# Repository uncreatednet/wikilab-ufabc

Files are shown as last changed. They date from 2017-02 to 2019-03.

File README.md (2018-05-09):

# wikilab

Um laboratório experimental baseado no [wikihouse](http://wikihouse.cc/) e na [casa modelo](http://www.archdaily.com.br/br/773676/casa-revista-a-primeira-casa-fabricada-digitalmente-no-brasil) da UFRJ (também feito com o wikihouse).

[English version here](english.md)

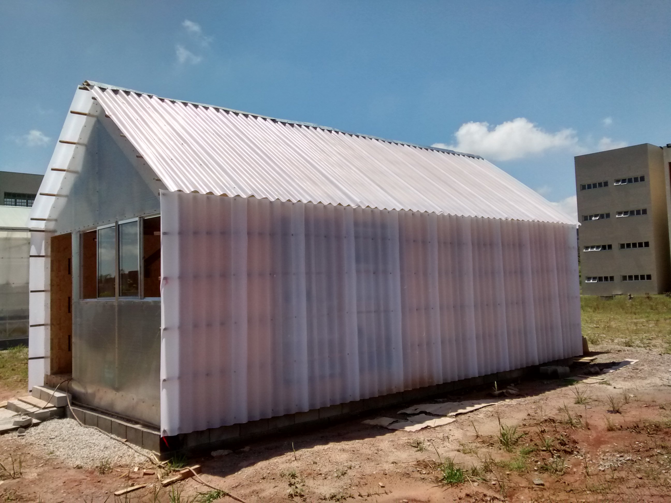
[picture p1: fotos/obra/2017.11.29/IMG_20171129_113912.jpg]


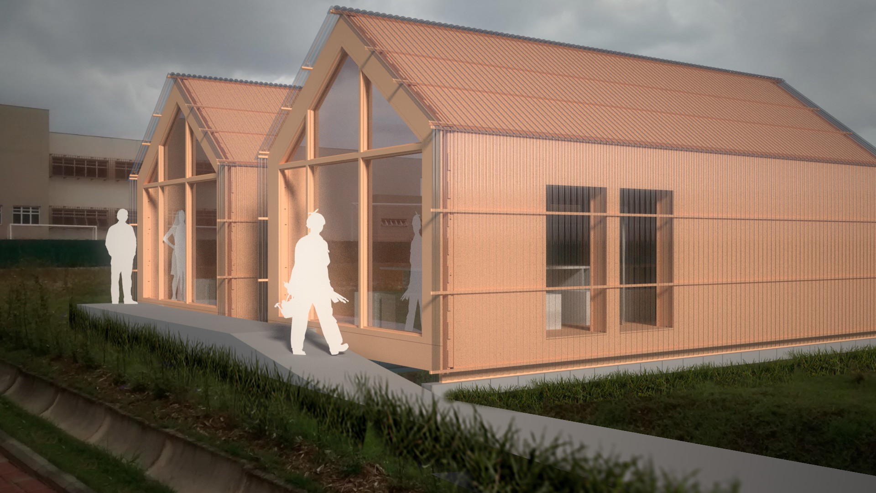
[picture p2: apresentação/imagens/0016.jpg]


Este projeto foi construído no segundo semestre de 2017. O projeto foi desenvolvido de forma aberta como parceria entre diferentes entidades incluindo o labLivre da UFABC e o [uncreated.net](http://www.uncreated.net)

Nas pastas deste projeto, podem ser encontrados:

* O modelo principal do projeto, que é o arquivo [wikilab.FCStd](wikilab.FCStd) a ser aberto com o [FreeCAD](http://www.freecadweb.org) contendo o projeto completo em 3D ([BIM](https://pt.wikipedia.org/wiki/BIM))
* O módulo de base, que serviu para o corte das peças com máquina CNC, está no arquivo separado [modulo wren.FCStd](modulo wren.FCStd)
* Um manual de construção, que descreve passo a passo todas etapas da construção do Wikilab
* Fotos da preparação, da montagem (obra) e do Wikilab acabado
* A pasta "apresentação" contém arquivos .blend do mesmo modelo, para geração de imagens, a serem abertos com o [Blender](http://www.blender.org)
* Na parta "orçamento" estão as planilhas dos orçamentos preliminares e definitivo do projeto. O projeto foi construido, com algumas trocas e modificações, dentro do preço do orçamento final
* Exemplos e referências de outros projetos
* Plantas clássicas de arquitetura, que foram feitas para obtenção da aprovação do projeto junto a UFABC, está no pasta "aprovação 
* A pasta "folhas de corte" contem as bases que foram extraidas do modelo 3D, e os arquivos gcode que forma gerados a partir dessas bases

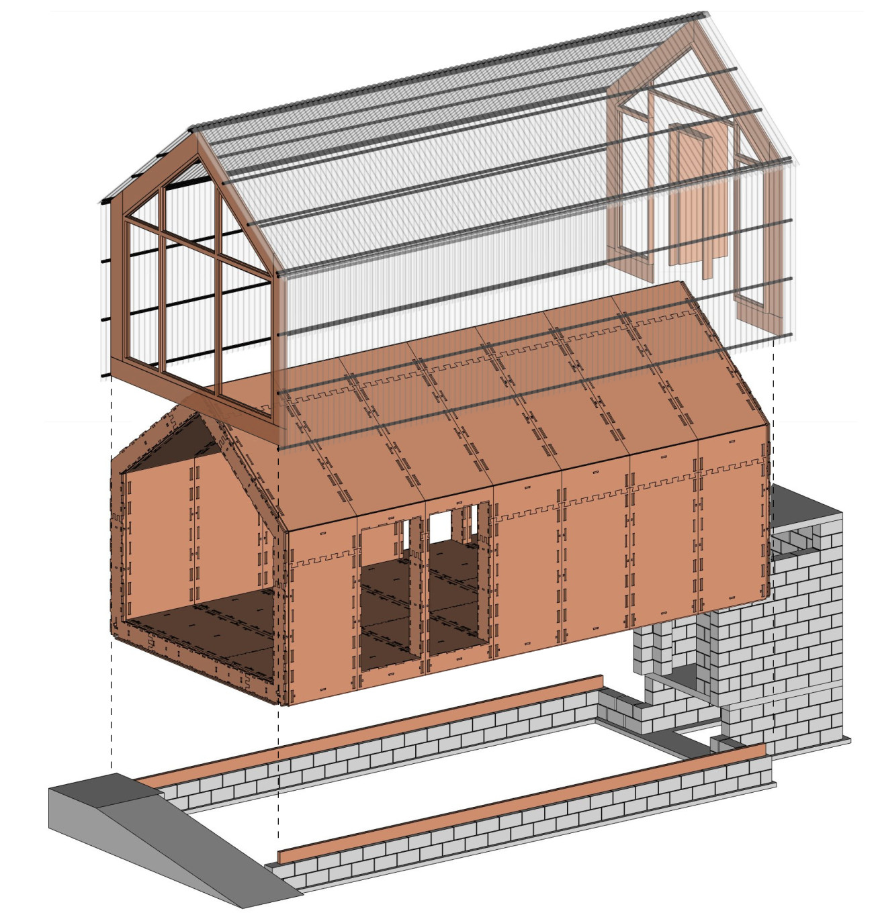
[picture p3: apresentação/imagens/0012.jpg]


Veja também o [modelo no sketchfab](https://sketchfab.com/models/bab56ed7d2414e13b3eacd6c2f29ce65)

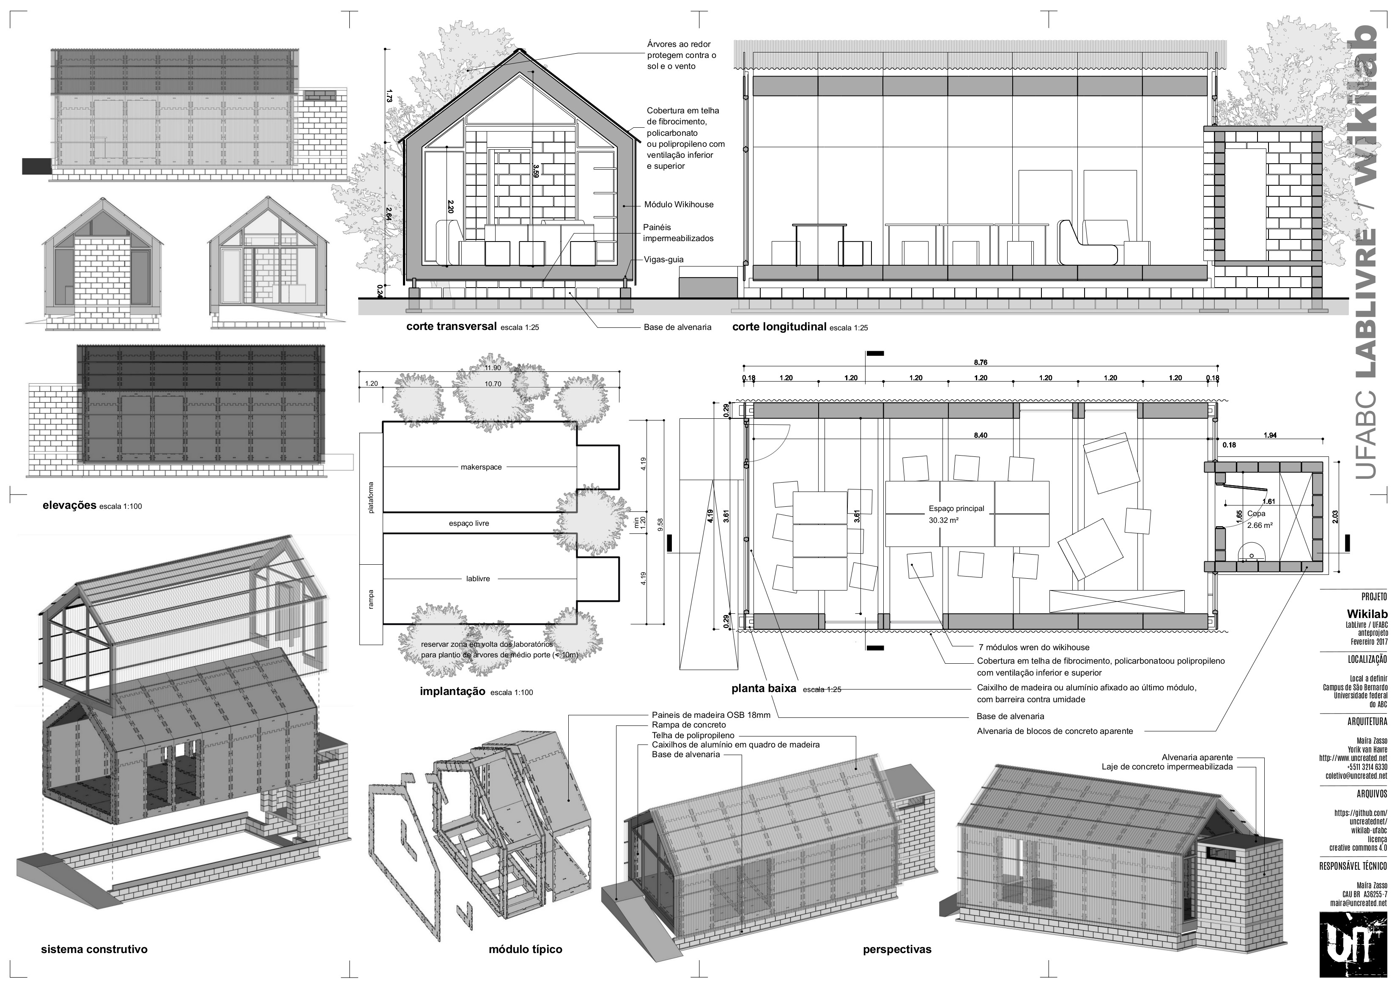
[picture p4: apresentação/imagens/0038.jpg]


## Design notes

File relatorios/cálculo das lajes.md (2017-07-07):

# Cálculo das lajes

usando o método de Marcus ([tabelas](https://drive.google.com/file/d/0B_sf8aj9_lOfUndZOWZqelZ1c2M/view?usp=sharing))

e método [curso de engenharia da USP](http://www.set.eesc.usp.br/mdidatico/concreto/Textos/11%20Lajes%20Macicas.pdf)

respeita [NBR 6118](https://drive.google.com/file/d/0B_sf8aj9_lOfVngzNnpPVkN6aWc/view?usp=sharing) e [NBR6120](https://drive.google.com/file/d/0B_sf8aj9_lOfbG9CeE1PY1ZnVHc/view?usp=sharing)

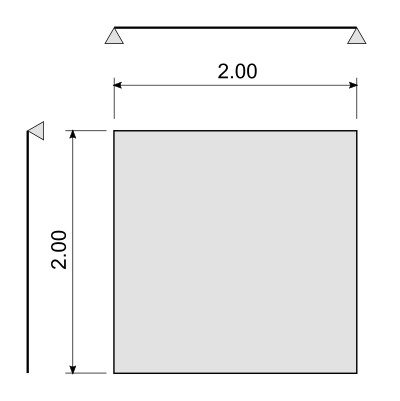
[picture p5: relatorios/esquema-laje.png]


## 1. Predimensionamento / flexão máxima

Usando a [NBR 6118](https://drive.google.com/file/d/0B_sf8aj9_lOfVngzNnpPVkN6aWc/view?usp=sharing)

Fórmula: d >= L / (psi2 x psi3)

psi2 = 1 (apoios simples em 3 lados)

psi3 = 30 (usando CA-50)

d = 200 cm / (1 x 30) = 6.7cm

espessura = 6.7 cm + 2 cm de recobrimento (tipo I da NBR) = 8.7 cm = **9 cm**

## 2. Área e carga

Área: 2 m x 2 m = **4 m²**

Peso próprio = 0.09 m x 2500 kg/m³ (concreto) = 225 kg/m² = 2.25 kN/m²

Sobrecarga = 200 kg/m² (carga padrão para uso residencial) = 2 kN/m²

Carga total = **4.25 kN/m²**

## 3. Tabela de Marcus

Usando o caso 1 da [tabela de Marcus](https://drive.google.com/file/d/0B_sf8aj9_lOfUndZOWZqelZ1c2M/view?usp=sharing), sem engastes:

Lx / Ly = 2.00 / 2.00 = 1

mx = 27.4

my = 27.4

Kx = 0.5

## 4. Cálculo dos momentos máximos

Usando a tabela de Marcus:

Mx = qL²/mx = 4.25 kN/m² x 4 m² / 27.4 = 0.62 kNm = **6.2 tfcm**

My = Mx = 0.62 kNm = 6.2 tfcm

qx = Kx x q = 0.5 x 4.25 kN/m² = 2.125 kN/m²

Considerando que um lado é engastado (improvável, só para ver o que seria o caso extremo)

Ma = -qL²/8 = -2.125 kNm = -21.25 tfcm

Usando a NBR ([tabela de Bares](https://drive.google.com/file/d/0B_sf8aj9_lOfZUlBdGNsOEcyMWM/view?usp=sharing)):

Caso 1 (apoios simples)

Mux = Muy = 4.23

Mx = My = Mux x qL²/100 = 4.23 x 4.25Kn/m² x 4 / 100 = 0.71 kNm = **7.1 tfcm**

## 5. Dimensionamento das ferragens 

Usando aço CA-50 / concreto C20

~~x = metade da altura total da laje = 9cm / 2 = 4.5cm~~

d = altura da laje acima da ferragem = 7cm

**Dimensionamento para Mx/My (Marcus)**

~~Usando sigma calculado = x/d = 4.5/7 = 0.6428 -> k6 = 41 -> k3 = 0.429~~

Usando k6 da tabela = 00 x d² / q = 100 x 7² / 6.2 tfcm = 790 -> k3 = 0.325

Área de aço As = 0.325 x 6.2 / 7 = **0.28 cm²/m**

**Dimensionamento para Mx/My (NBR)**

Usando [Tabelas Gerais](https://drive.google.com/file/d/0B_sf8aj9_lOfUGpUWXpqQ3o5UVE/view?usp=sharing)

Usando momento de cálculo Md = 1.4 x Mx = 1.4 x 0.71 kNm = 0.994 kNm = 99.4 kNcm

kc = bd²/Md = 100 x 7² / 99.4 = 49.3 cm²/kN

ks = 0.023 (tabela)

Área de aço  As = ks x Md / d = 0.023 x 99.4 / 7 = **0.32 cm²/m**

**Dimensionamento para Ma** (caso não existente  apenas para ver o que seria o extremo)

~~Usando sigma calculado = x/d = 4.5/7 = 0.6428 -> k6 = 41 -> k3 = 0.429~~

Usando k6 da tabela = 100 x d² / q = 100 x 7² / 21.25 tfcm = 230 -> k3 = 0.331

Área de aço As = 0.331 x 21.25 / 7 = **1.0 cm²/m**

## 6. Verificação tamanho mínimo (NBR):

As min = 0.00075 x h xl = 0.00075 x 7 x 100 = **0.52 cm²/m**

## 7. Ferragens

Telas disponíveis e área em cm²/m

| Bitola | 20 cm | 15 cm | 10 cm |
| --- | ----- | ----- | ----- |
| 3.4 mm | 0.36  | 0.54  | 0,81  |
| 4.2 mm | 0.55  | 0.82  | 1.24  |

Ferragem apropriado: **4.2 mm x 20 cm ou 3.4 mm x 15 cm**

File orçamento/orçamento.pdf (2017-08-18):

Wikilab - orçamento 18/08/2017 | 1/3
Orçamento definitivo | data: 18.08.2017 | fonte PMSP: http://www.prefeitura.sp.gov.br/cidade/secretarias/obras/tabelas_de_custos/index.php?p=232211
Escopo Seção | Item | Descição | Quantidade | Unidade | Preço material | Total material Total mão de obra | Preço total | Fonte do preço | Observações

E

m

# preiteira

## 1 Fundação, alvenaria e estrutura

1.1 | | 46.37 | m² | R$ 0.00 | R$ 4.15 | R$ 0.00 | R$ 192.43 | R$ 192.43 | PMSP 01-01-08
1.2 | Escavação manual das valas de 30cm x 30cm | 2.55 | m³ | R$ 0.00 | R$ 49.81 | R$ 0.00 | R$ 127.22 | R$ 127.22 | PMSP 01-04-01
1.3 | Lastro de concreto de 7cm no funda da vala | 0.60 | m³ | R$ 173.62 | R$ 140.24 | R$ 103.36 | R$ 83.49 | R$ 186.86 | PMSP 13-01-14
1.4 | Lastro de concreto de 5cm no terreno todo | 1.58 | m³ | R$ 173.62 | R$ 140.24 | R$ 273.52 | R$ 220.94 | R$ 494.46 | PMSP 13-01-14
1.5 | | 10.28 | m² | R$ 52.69 | R$ 29.53 | R$ 541.65 | R$ 303.57 | R$ 845.22 | PMSP 04-01-35
1.6 | Grauteamento dos blocos | 0.98 | m³ | R$ 219.27 | R$ 400.41 | R$ 214.14 | R$ 391.04 | R$ 605.18 | PMSP 04-01-97
1.7 | | 11.07 | kg | R$ 3.37 | R$ 3.09 | R$ 37.30 | R$ 34.19 | R$ 71.48 | PMSP 04-01-95
1.8 | | 10.28 | m² | R$ 28.19 | R$ 35.81 | R$ 289.79 | R$ 368.13 | R$ 657.92 | PMSP 02-06-05
1.9 | Lona de polietileno 4x3m de baixo da laje | 1.00 | un | R$ 16.00 | R$ 0.00 | R$ 16.00 | R$ 0.00 | R$ 16.00 | Leroy Merlin
1.10 | Forma para lajes de concreto em tábuas de madeira | 7.33 | m² | R$ 8.54 | R$ 44.52 | R$ 62.60 | R$ 326.33 | R$ 388.93 | PMSP 02-03-01
1.11 | | 0.79 | m³ | R$ 260.60 | R$ 121.96 | R$ 206.86 | R$ 96.81 | R$ 303.68 | PMSP 02-05-06
1.12 | | 5.62 | kg | R$ 4.34 | R$ 1.55 | R$ 24.39 | R$ 8.71 | R$ 33.10 | PMSP 03-02-09
1.13 | Impermeabilização de laje | 4.45 | m² | R$ 28.19 | R$ 35.81 | R$ 125.45 | R$ 159.35 | R$ 284.80 | PMSP 02-06-05
1.14 | | 26.00 | m² | R$ 52.69 | R$ 29.53 | R$ 1,370.11 | R$ 767.87 | R$ 2,137.98 | PMSP 04-01-35
1.15 | Grauteamento dos blocos abaixo da laje superior | 0.15 | m³ | R$ 219.27 | R$ 400.41 | R$ 33.68 | R$ 61.50 | R$ 95.18 | PMSP 04-01-97
1.16 | | 3.53 | kg | R$ 3.37 | R$ 3.09 | R$ 11.89 | R$ 10.90 | R$ 22.79 | PMSP 04-01-95
1.17 | Porcas 8mm + aruelas | 16.00 | un | R$ 3.40 | R$ 0.00 | R$ 54.40 | R$ 0.00 | R$ 54.40 | Leroy Merlin
1.18 | Rampa de concreto | 1.93 | m³ | R$ 258.86 | R$ 110.35 | R$ 499.60 | R$ 212.98 | R$ 712.58 | PMSP 03-03-05
1.19 | Calçada de concreto | 25.20 | m² | R$ 290.46 | R$ 35.69 | R$ 7,319.59 | R$ 899.39 | R$ 8,218.98 | PMSP 17-02-65
1.20 | Tubulação de PVC 50mm | 3.00 | m | R$ 7.34 | R$ 22.60 | R$ 22.02 | R$ 67.80 | R$ 89.82 | PMSP 10-09-31
1.21 | Tubulaçõa de PVC 75mm | 3.00 | m | R$ 10.07 | R$ 33.89 | R$ 30.21 | R$ 101.67 | R$ 131.88 | PMSP 10-09-32
| Total seção | | | | | R$ 3,417.38 | R$ 3,321.96 | R$ 6,739.33

## Lablivre Wikilab

Preço mão de
obra

Limpeza do terreno + remoção da camada vegetal em toda a área da construção (11m x 4.20m)

Sapata corrida em alvenaria de bloco de concreto estrutural de 19cm (duas fileiras, fileira de cima em bloco canaleta)

Ferragem de reforço em alvenaria: 2 barras bitola 5mm CA-50 (total 65m)
Impermeabilização da sapata com cimentagem e pintura bituminosa (topo da sapata)

Concreto estrutural 20Mpa em duas lajes de 2m x 2m x 9cm
Ferragens – malha 20x20 bitola 4.2mm – 2 peças de 2m x 2m

Alvenaria de bloco de concreto de 19cm aparente (12 fileiras, fileira superior em bloco canaleta)

Ferros filetados 16 barras dobradas CA50 de 8mm x 55cm = 9m

Retirado provisoriamente do orçamento (definir melhor
como fazer)
Retirado provisoriamente do orçamento (definir melhor
como fazer)

Escopo Seção | Item | Descição | Quantidade | Unidade | Preço material | Total material Total mão de obra | Preço total | Fonte do preço | Observações Preço mão de
obra

E

m

# preiteira

## 2 Marcenaria

2.1 | | 17.52 | m | R$ 25.00 | R$ 2.00 | R$ 438.00 | R$ 35.04 | R$ 473.04
2.2 | | 1.00 | un | R$ 153.80 | R$ 55.65 | R$ 153.80 | R$ 55.65 | R$ 209.45 | PMSP 07-01-11
2.3 | Batente de madeira para porta interior | 1.00 | un | R$ 216.20 | R$ 52.36 | R$ 216.20 | R$ 52.36 | R$ 268.56 | PMSP 07-01-50
2.4 | | 1.00 | un | R$ 953.00 | R$ 0.00 | R$ 953.00 | R$ 0.00 | R$ 953.00 | Leroy Merlin
2.5 | Caixilho de alumínio de correr 120cm x 100 cm | 2.00 | un | R$ 390.00 | R$ 0.00 | R$ 780.00 | R$ 0.00 | R$ 780.00 | Leroy Merlin
2.6 | Caixilho de alumínio maximar 60cm x 60cm | 1.00 | un | R$ 325.00 | R$ 0.00 | R$ 325.00 | R$ 0.00 | R$ 325.00 | Leroy Merlin
2.7 | Caixilho de alumínio basculante 80cm x80cm | 2.00 | un | R$ 214.00 | R$ 0.00 | R$ 428.00 | R$ 0.00 | R$ 428.00 | Leroy Merlin
2.8 | Instalação de 6 portas e caixilhos de alumínio | 5.93 | m² | R$ 0.00 | R$ 37.00 | R$ 0.00 | R$ 219.41 | R$ 219.41 | PMSP 08-02-05
2.9 | | 26.22 | m | R$ 8.00 | R$ 0.00 | R$ 209.76 | R$ 0.00 | R$ 209.76 | Leroy Merlin
2.10 | | 24.53 | m² | R$ 0.00 | R$ 29.68 | R$ 0.00 | R$ 727.99 | R$ 727.99 | PMSP 06-01-01
2.11 | | 65.00 | un | R$ 6.50 | R$ 0.00 | R$ 422.50 | R$ 0.00 | R$ 422.50 | Leroy Merlin
2.12 | | 1.00 | un | R$ 42.00 | R$ 0.00 | R$ 42.00 | R$ 0.00 | R$ 42.00 | Leroy Merlin | Quantidade estimada
2.13 | Parafusos 35mm para módulos wikihouse (caixa com 500) | 4.00 | un | R$ 26.00 | R$ 0.00 | R$ 104.00 | R$ 0.00 | R$ 104.00 | Leroy Merlin | Quantidade estimada
2.14 | Réguas de madeira de 2x2cm | 23.52 | m | R$ 4.00 | R$ 0.00 | R$ 94.08 | R$ 0.00 | R$ 94.08 | Leroy Merlin
2.15 | Enverizagem dos caibros e réguas | 10.00 | m² | R$ 18.06 | R$ 15.46 | R$ 180.60 | R$ 154.60 | R$ 335.20 | PMSP 15-02-20 | Quantidade estimada
2.16 | Vidro liso 4mm com instalação com massa de vidraceiro | 3.84 | m² | R$ 62.00 | R$ 55.68 | R$ 237.91 | R$ 213.66 | R$ 451.56 | PMSP 14-01-03
2.17 | Placas cimentícias 6mm | 12.62 | m² | R$ 44.00 | R$ 0.00 | R$ 555.28 | R$ 0.00 | R$ 555.28 | Breithaupt
2.18 | Painéis de OSB de 1cm | 5.54 | m² | R$ 35.00 | R$ 0.00 | R$ 193.90 | R$ 0.00 | R$ 193.90 | Leroy Merlin
2.19 | Caibros 3x3cm para instalação da cobertura | 374.00 | m | R$ 1.00 | R$ 0.00 | R$ 374.00 | R$ 0.00 | R$ 374.00 | Preço madeireiras
2.20 | Instalação dos caibros para cobertura | 101.36 | m² | R$ 0.00 | R$ 35.24 | R$ 0.00 | R$ 3,571.93 | R$ 3,571.93 | PMSP 06-01-13 | Instalado por voluntários
2.21 | | 5.00 | un | R$ 26.00 | R$ 0.00 | R$ 130.00 | R$ 0.00 | R$ 130.00 | Mercado livre | Quantidade estimada
Total seção | R$ 5,838.03 | R$ 1,458.71 | R$ 7,296.73

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
## 3 Módulos wikihouse

3.1 | Painéis de compensado ou OSB 1200x2400x18mm | 150.00 | un | R$ 75.00 | R$ 0.00 | R$ 11,250.00 | R$ 0.00 | R$ 11,250.00 | Beija-flor
3.3 | Recorte dos painéis em empresa de CNC | 1.00 | un | R$ 0.00 | R$ 21,000.00 | R$ 0.00 | R$ 21,000.00 | R$ 21,000.00 | 123painéis
Total seção | R$ 11,250.00 | R$ 21,000.00 | R$ 32,250.00

Vigas-guia em madeira de 9x9cm em pinus autoclavado tratado para uso exterior

PMSP 06-01-01 +
Preço madeireiras
Porta interior de madeira de 80x210cm com batente, ferragens e instalação

Porta exterior de alumínio com vidro inteiro de 90cm x 210cm

Estrutura de caibros 6x6cm autoclavados tratados para uso exterior - suporte de esquadrias
Instalação e montagem da estrutura de caibros, e fechamentos com placa cimentícia
Cantoneiras metálicas para fixação dos caibros e para fixação dos módulos wikihouse nas vigas-guia
Parafusos 45mm para fixação das cantoneiras (caixa com 500)

Parafusos + aruelas de borracha para fixação das telhas (caixa com 100)

A ser feito por equipe de
voluntários. Sem custos de mão de obra

30 minutos por painel em
média, segundo pessoas do
projeto Wikihouse

Escopo Seção | Item | Descição | Quantidade | Unidade | Preço material | Total material Total mão de obra | Preço total | Fonte do preço | Observações Preço mão de
obra

E

m

# preiteira

## 4 Elétrica

4.1 | | 1.00 | un | R$ 47.55 | R$ 40.59 | R$ 47.55 | R$ 40.59 | R$ 88.14 | PMSP 09-05-04
4.2 | Disjuntores bipolares termomagnéticos de 20A | 4.00 | un | R$ 33.47 | R$ 20.07 | R$ 133.88 | R$ 80.28 | R$ 214.16 | PMSP 09-08-12
4.3 | Eletroduto de PVC 25mm embutido em pisos e paredes | 8.00 | m | R$ 2.95 | R$ 12.93 | R$ 23.60 | R$ 103.44 | R$ 127.04 | PMSP 09-02-02
4.4 | | 42.00 | m | R$ 1.11 | R$ 2.16 | R$ 46.62 | R$ 90.72 | R$ 137.34 | PMSP 09-03-21
4.5 | Interuptores de uma tecla simples 10A – 250V | 1.00 | un | R$ 22.85 | R$ 86.21 | R$ 22.85 | R$ 86.21 | R$ 109.06 | PMSP 09-07-01
4.6 | Tomada simples | 1.00 | un | R$ 24.44 | R$ 86.21 | R$ 24.44 | R$ 86.21 | R$ 110.65 | PMSP 09-07-60
4.7 | Ponto de luz em laje de concreto | 1.00 | un | R$ 35.74 | R$ 137.93 | R$ 35.74 | R$ 137.93 | R$ 173.67 | PMSP 09-07-90
4.8 | Eletrocalha metálica perfurada 100x50mmx3m | 4.00 | un | R$ 52.00 | R$ 0.00 | R$ 208.00 | R$ 0.00 | R$ 208.00 | Mercado livre | Instalado por voluntários
4.9 | Caixa de passagem em PVC embutida em parede | 2.00 | un
| Fixação da eletrocalha?
| Total seção | | | | | R$ 542.68 | R$ 625.38 | R$ 1,168.06

Voluntários

## 5 Cobertura

5.1 | | 40.00 | un | R$ 82.00 | R$ 0.00 | R$ 3,280.00 | R$ 0.00 | R$ 3,280.00 | Telhaton | Preço a verificar
5.2 | Instalação da cobertura | 101.36 | m² | R$ 0.00 | R$ 14.06 | R$ 0.00 | R$ 1,425.12 | R$ 1,425.12 | PMSP 06-02-21 | Instalado por voluntários
| Total seção | | | | | R$ 3,280.00 | R$ 0.00 | R$ 3,280.00

E

m

# preiteira

## 6 Infraestrutura

6.1 | Escavação manual das valas de 30cm x 30cm | 3.39 | m³ | R$ 0.00 | R$ 49.81 | R$ 0.00 | R$ 169.01 | R$ 169.01 | PMSP 01-04-01
6.2 | Eletroduto de PVC 100mm enterrado | 37.70 | m | R$ 35.61 | R$ 25.86 | R$ 1,342.50 | R$ 974.92 | R$ 2,317.42 | PMSP 09-02-09
6.3 | Reaterro de vala com compactação manual | 3.39 | m³ | R$ 0.00 | R$ 9.87 | R$ 0.00 | R$ 33.49 | R$ 33.49 | PMSP 01-04-80
6.4 | Caixa de inspeção em alvenaria 30x30x60cm | 0.45 | m² | R$ 81.09 | R$ 146.71 | R$ 36.49 | R$ 66.02 | R$ 102.51 | PMSP 10-10-95/96
6.5 | Tampa de concreto 30x60cm | 0.45 | m² | R$ 38.12 | R$ 126.92 | R$ 17.15 | R$ 57.11 | R$ 74.27 | PMSP 10-10-98
Fibra ótica exterior | 70.00 | m | Providenciado pelo NTI
| | 222.00 | m | R$ 2.51 | R$ 3.02 | R$ 557.22 | R$ 670.44 | R$ 1,227.66
| Instalação da fibra ótica em canaletas existentes | 70.00 | m
| Instalação da fiação elétrica em canaletas existentes | 74.00 | m
Total seção | R$ 1,396.14 | R$ 1,300.55 | R$ 2,696.69
| material | mão de obra | total
TOTAL GERAL EMPREITEIRA | R$ 14,474.22 | R$ 6,706.59 | R$ 21,180.82
TOTAL GERAL DA OBRA | R$ 25,724.22 | R$ 27,706.59 | R$ 53,430.82

Quadro geral de distribuição elétrica em PVC embutido em parede de alvenaria

Fiação de cobre de 2.5mm / 4mm isolada com PVC com resistência mínima de 750V / 70°C

Telha de polipropileno ou fibra de vidro transparente em chapas de 1.1x3m

Fiação de cobre de 6mm isolada com PVC com resistência mínima de 0.7kV

Providenciado por?
Patrocínio? UFABC?
Providenciado pela
prefeitura?
Providenciado pela
prefeitura?

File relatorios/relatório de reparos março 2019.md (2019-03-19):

## Relatório de danos e reparos a efeituar no WikiLab

Elaborado por Yorik van Havre, [uncreated.net](http://www.uncreated.net) 15 de Março de 2019

### Danos constatados no WikiLab

Em geral, o WikiLab resistiu bastante bem desde a sua construção até agora. Não foram constatados nenhum dano grave, a quase totalidade são problemas de infiltração de água devida a vedação insuficiente entre os paineis de policarbonato alveolar das duas fachadas verticais Norte e Sul. Foram identificados os seguintes problemas:

* A água de chuva consegue entrar por dentro pelas frestas deixadas entre as placas de policarbonato, ou entre as placas de policarbonato e os caixilhos de portas e janelas. Estava prevista uma vedação melhor ali, que nunca foi feita. A água que se infiltrou danificou partes da madeia, geralmente no piso, que é onde a água acaba acumulando. Indicado nas imagens abaixo nos pontos **1,2 3,6,7**.
* A água consegue também, por vento forte, atingir as faces laterais, normalmente protegidas pelas telhas de polipropileno onduladas. Porém, ali é um dano muito superficial, que só alcance alguns centímetros, e não são motivos para preocupação, já que a madeira consegue secar com facilidade. Não está indicado nas imagens abaixo.
* Alguns dos elements de cumeira metálicos foram também mal instalados, e se deslocaram com o tempo e a força do vento nas telhas. Em um lugar, a telha de polipropileno conseguiu se soltar da cumeira, e não está mais presa em baixo. Por vento muito forte e indo na direção errada, a água consegue entrar entre a cumeira e as telhas Indicado nas imagens abaixo no ponto **4**.
* A placa de policarbonato em cima da laje de concreto está insuficientemente vedada, e a água consegue entrar para baixo dela. Indicado nas imagens abaixo no ponto **5**.
* Partes da madeira não está cobertos com placas de policarbonato e estão totalmente expostas à chuva. Indicado nas imagens abaixo nos pontos **6 e 7**.

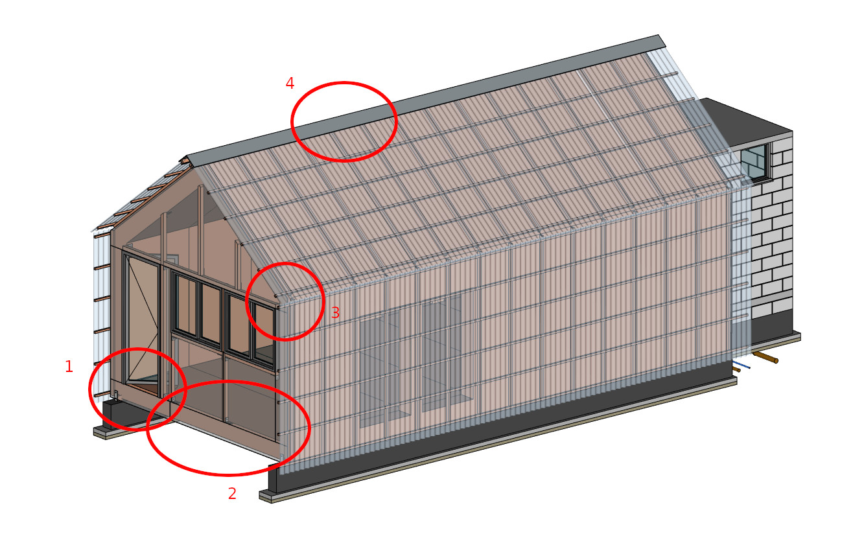
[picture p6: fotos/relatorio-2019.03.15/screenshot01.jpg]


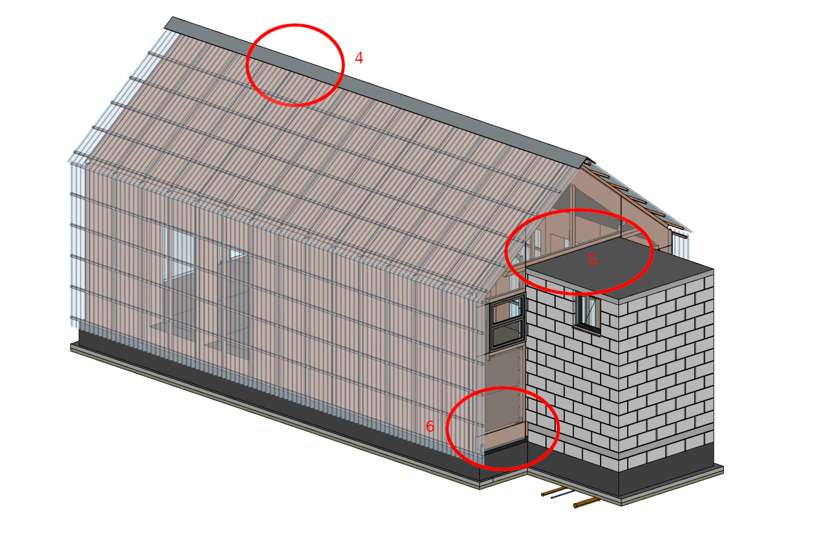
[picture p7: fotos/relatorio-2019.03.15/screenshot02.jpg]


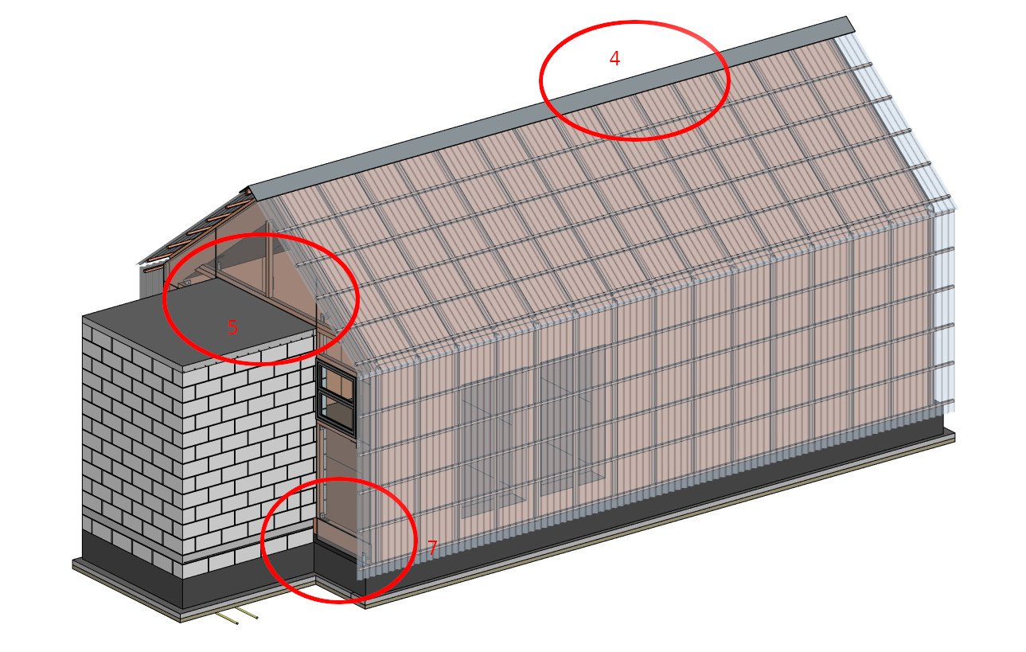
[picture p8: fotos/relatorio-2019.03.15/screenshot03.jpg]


Fotos dos problemas acima e dos danos provocados:

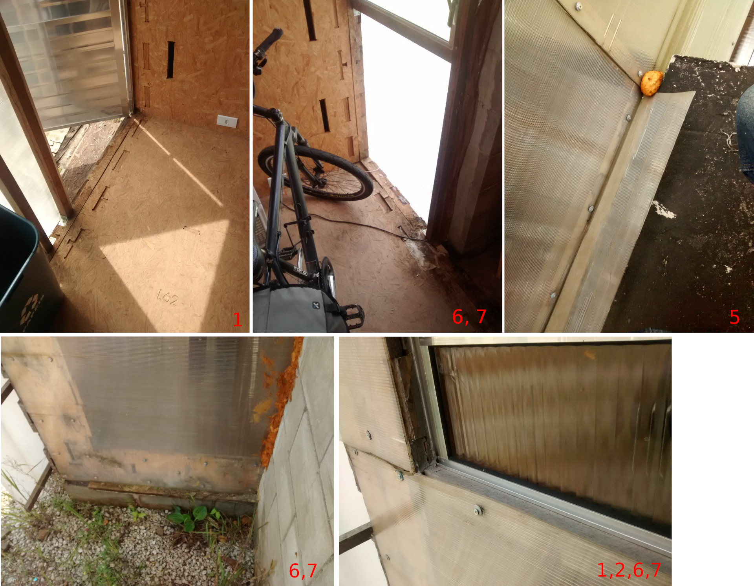
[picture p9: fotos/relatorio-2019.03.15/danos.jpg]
danos


Mais fotos das partes danificadas estão [disponíveis aqui](../foros/relatorio-2019.03.15).

### Reparos propostos

Todos os problemas acima podem ser facilmente resolvidos melhorando a vedação **exterior** do WikiLab. O elemento responsável pela impermeabilização é a "pele" exterior do WikiLab (telhas de polipropileno onduladas e placas alveolares de policarbonato). É importante ressaltar que todos os reparos devem ser feitos no exterior, porque se a pele é comprometida, e a água consegue entrar, vedar pelo interior não adianta, e pode até piorar as coisas provocando retenção de água.

As partes de madeira já danificadas não podem ser restauradas, e vão continuar com o visual danificado. No entanto, se cortamos a fonte de humidade, elas vão secar, e os problemas vão parar ali.

Propomos os reparos seguintes. Os pontos 1,2 e 3 são os mais urgentes:

#### 1,2,3,5,6,7:Vedar as juntas entre as placas de policarbonato, e entre as placas e os caixilhos metálicos, com silicone

Todas as bordas das janelas (exceto as bordas superiores, onde a água não consegue entrar), devem ser cobertas e vedadas com silicone, de maneira a formar uma superfície completamente impermeável entre os caixilhos metálicos e o policarbonato. Onde existe um espaço muito grande para ser coberto, pode ser pregado uma tira de policarbonato, para diminuir a quantidade de silicone a ser usado.

Exemplo:

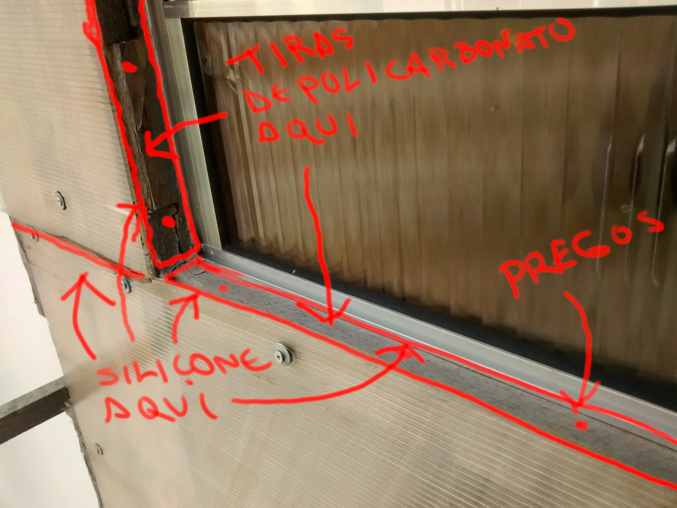
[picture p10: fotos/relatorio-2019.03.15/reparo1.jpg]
reparo1


**Material necessário estimado:**

* 4 ou 5 bisnagas de silicone, preferencialmente transparente, e uma "pistola" para as bisnagas (contando para todos os reparos deste relatório)
* Algumas tiras de policarbonato cortados a partir das sobras existentes (medir no local, onde precisar)
* Trena de medir, Estilete para cortar o policarbonato, régua para guiar o corte
* Pregos +/- 4cm e martel

#### 6,7: obrir as partes de madeira expostas no pé da fachada traseira

Mesma técnica que o ponto acima, vedar todo com silicone depois. Do lado direito, essa placa fica em contato com o solo, o que deve ser evitado também. Sugerimos cavar alguns centímetros para baixar o nível do terreno ao redor desse pedaço de madeira

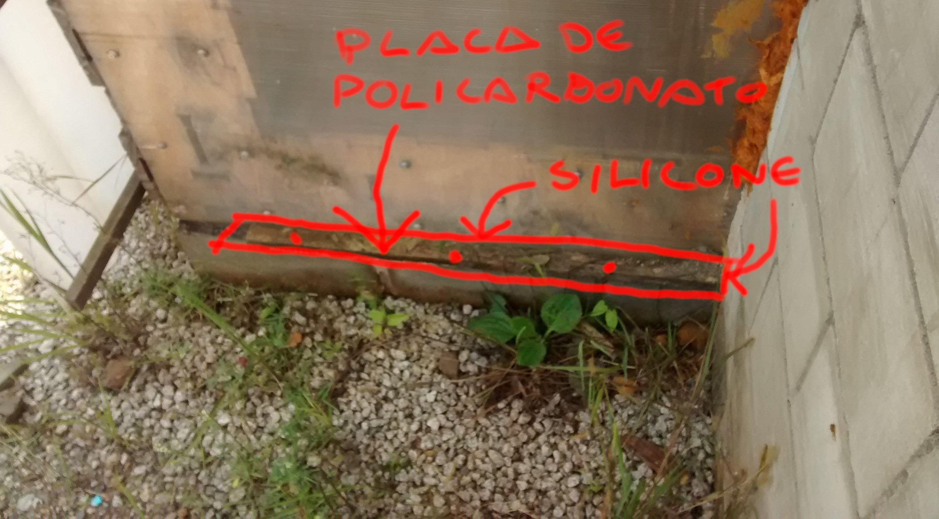
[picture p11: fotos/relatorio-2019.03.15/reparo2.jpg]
reparo2


#### 5:Vedação acima da laje

Deve ser afixado o pedaço de policarbonato "solto" na laje, usando parafusos com buchas, e vedado com silicone depois:

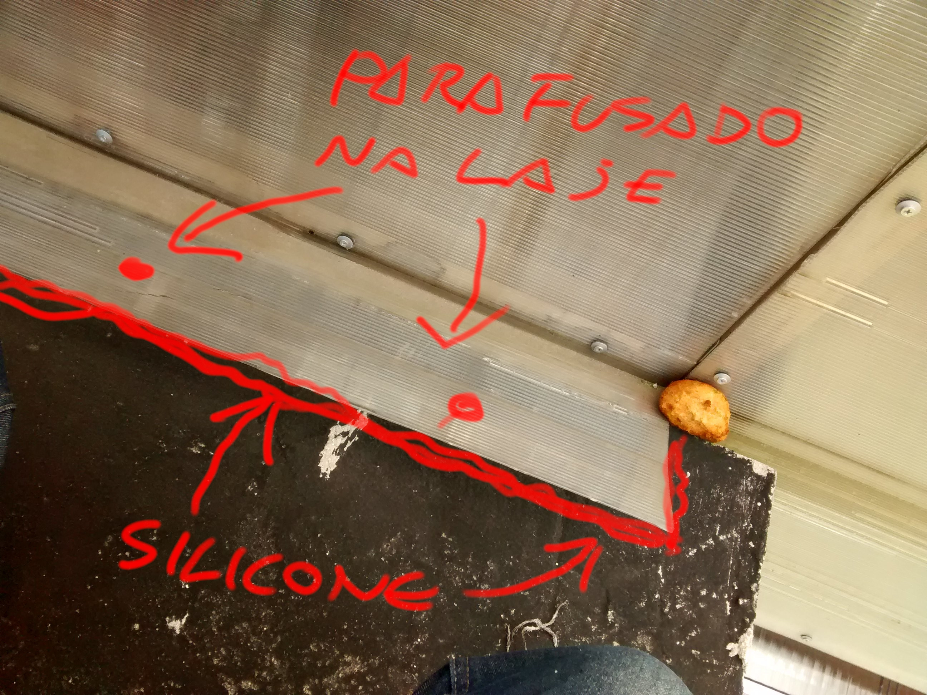
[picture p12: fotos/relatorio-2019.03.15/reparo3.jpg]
reparo3


**Material necessário estimado:**

* 5 ou 6 parafusos de +/- 4cm de comprimento (não passar de 6cm), com buchas apropriadas
* Furadeira com broca apropriada às buchas escolhidas
* Extensão elétrica

#### 4: Troca de um elemento de cumeira

Deve ser comprado um elemento adicional de cumeira em chapa de aço galvanizado (a espessura não tem muita importância), fabricado especialmente por uma funilaria com as dimensões abaixo. Se trata de um elemento simples e relativemente barato:

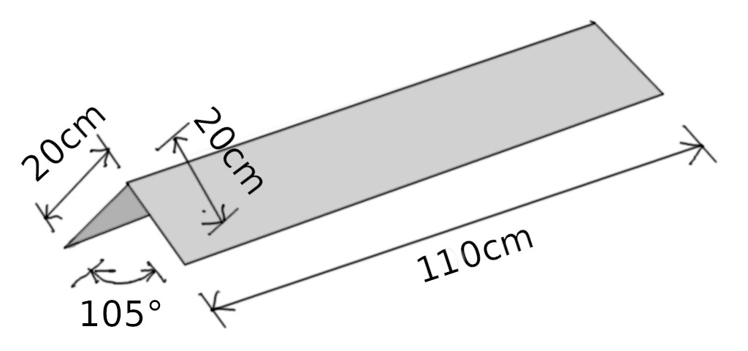
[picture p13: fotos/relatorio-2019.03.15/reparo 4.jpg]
reparo 4


Este elemento deve ser furado na hora de instalar (min. 4 furos), e parafusado no lugar do elemento antigo, que deve ser removido (e guardado para reuso futuro). Os parafusos existentes podem ser reaproveitados aqui.

**Material necessário estimado:**

* Broca grande para furar o metal (verificar tamanho dos parafusos existentes)

#### 1: Troca da soleira da porta de entrada

A soleira da entrada está danificando rapidamente. Pode ser trocada por uma peça de madeira boa (cumaru, cedor, mogno) que não vai danificar muito rapidamente e resistir por vários anos. Tamanho estimado (medir no local antes de encomendar/comprar): 85cm x 6cm x 3cm

Pode ser necessário a retirada da porta para retirar a peça existente e por a soleira nova

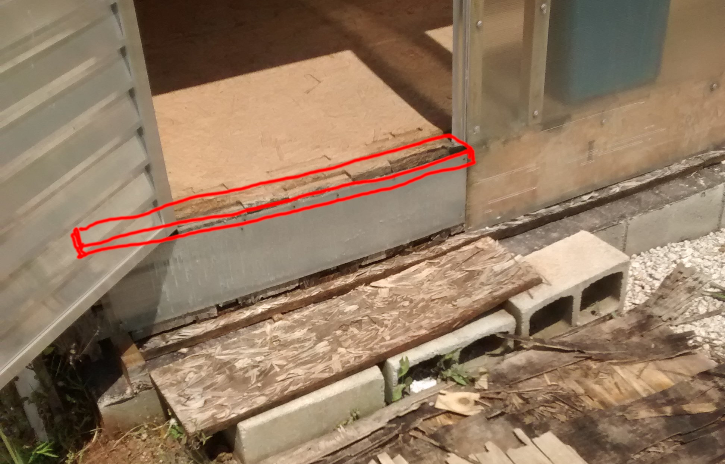
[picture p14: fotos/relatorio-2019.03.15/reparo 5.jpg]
reparo 5


### Considerações adicionais

* A fechadura da porta está danificada. Deveria ser trocada em algum momento
* O calor forte dentro do WikiLab tem duas causas principais: 1) A ventilação insuficiente (foram instaladas janelas menores do que as previstas inicialmente), e 2) A exposição muito grande da fachada da frente aos raiso do sol. O ponto 1) não pode ser melhorado muito facilmente, a não ser estudando uma maneira de fazer aberturas temporárias nas placas de policarbonato), mas o ponto 2) poderia ser resolvido de uma maneira bastante fácil e agradável instalando cabos metálicos e deixando plantas trepadeiras subir neles. Isso, obviamente, ia requerer uma manutenção cuidadosa para evitar que as plantas penetrem dentro do WikiLab:

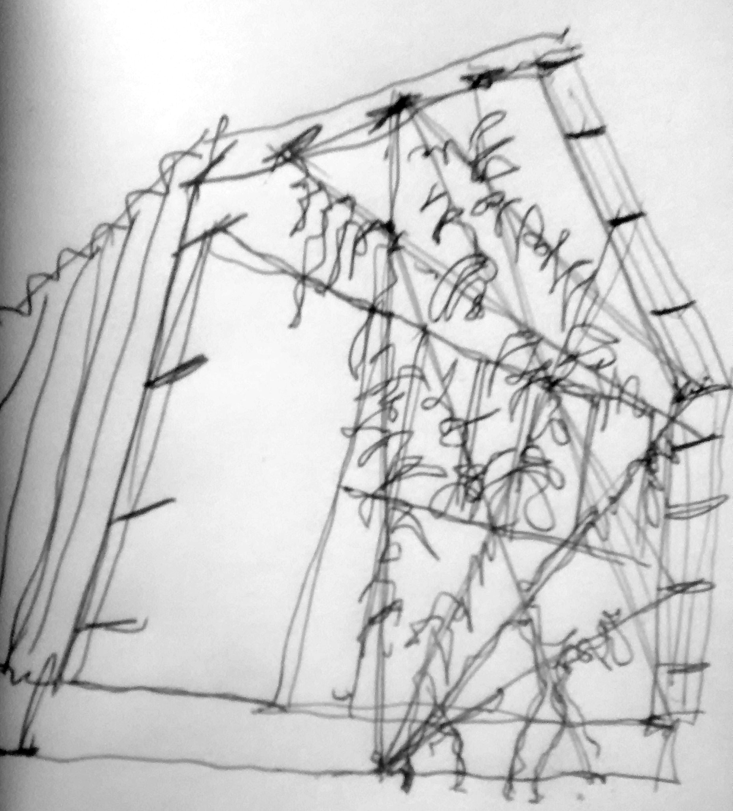
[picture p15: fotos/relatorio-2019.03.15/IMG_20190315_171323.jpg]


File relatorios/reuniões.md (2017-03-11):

## Relatório de reunio do 2017.03.11 com os engenheiros da UFABC

* De maneira geral o projeto foi bem recebido, entendido e está globalmente aprovado
* Levantarantam algumas dúvidas sobre o sistema de ventilação, a maneira de evitar que ventos de chuva, fortes e quase horizontais, penetrem no interior da cobertura de telha. Concordamos que esses pontos devero ser resolvidos com atenção particular mais adiante
* Sugerem acrescentar uma área exterior (terraço, deck,...)
* No podem ter árvores, porque o terreno deve ficar livre para o prédio futuro a ser construído no lugar
* Sugerem acrescentar uma base de concreto em baixo da construção, para diminuir a umidade
* A infra (conexões às redes de água, energia elétrica e lógica) da universidade deverá ser custeado pelo projeto
* Devemos fornecer aos engenheiros da UFABC um resumo do consumo de energia previsto
* Deverão ser instalados no wikilab um quadro de energia e um roteador/switch, talvez (mas não necessariamente) na casinha de alvenaria
* Deverá ser estudada a questão da lógica com o setor apropriado da UFABC
* O terreno ainda deverá ser definido pela engenharia da UFABC, sendo de um lado ou do outro do espaço destinado ao prédio novo, a ser definido.
* Estudar problemática dos cupins (soluções possíveis, etc)
* Sugerem instalar brises nas janelas laterais
* A evacuação da pia pode ser feita com sumidouro

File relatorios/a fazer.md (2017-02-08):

# wikilab

### Contatos

Ver da experiência desses caras e se/como pode rolar uma parceria

* Contatar Alastair Parvin - o fundador do wikihouse - http://wikihouse.cc/ - contatado 18.10.2016
* Contatar WikiHouseRio - http://wikihouserio.cc/ - contatado 18.10.2016
* Contatar Anderson França - trabalhou com o wikihouse Rio - http://www.andersonfranca.com/
* Ver contato do Alex Garcia na UFRJ que trabalhou no wikihouse
* Outros contatos na wikihouse foundation?
* Contatos com fab-labs?

### Construção

* Ver empresas ou lugares que podem cortar os painéis de madeira
* Ver possível pareceria com FabLabs? 
* Os [fab-labs livres de SP](http://fablablivresp.art.br/) que são indicados como "grande porte" tem uma máquina de tamanho suficiente para cortar os painéis de 1.20x2.40m do wikihouse
* Quem vai construir? Estudantes, empreiteiro, PPP? 
* Pode ser feito em compensado tanto quanto em OSB. OSB é melhor: mais sustentável, um pouco mais barato, e mais fácil de proteger contra fogo
* Diferentes estratégias de proteção contra fogo possíveis: impregnação com produto, revestimento com placas, etc
* A aprovação (universidade, prefeitura, bombeiros) vai ser difícil: O conceito é muito novo, vai ter alta desconfiança

### Projeto

* ~~Levantar um projeto básico do que precisa~~ feito - ver o que dá
* Conversar BEM com o pessoal sobre o aspecto experimental
* Definir estratégia de manutenção / plano "Marte"
* Ver esquema de segurança
* Accessibilidade
* Ventilação / aspecto sustentabilidade
* Ver estratégia de aprovação (instalação temporária?)
* Ver estratégia de fabricação
* Opções de material de revestimento - ver [opções no pinterest](https://au.pinterest.com/yorikvanhavre/wikilab/)
* Pesquisar proteção contra fogo
* Ver técnicas para portas e janelas
* Estimar cronograma / tempo de montagem / pessoal necessário

### Custos

* Estratégia de financiamento?
* 38.7m² no padrão popular (CUB = R$ 1300/m²) = R$ 50000
* 38.7m² = 35.3m² (wikihouse) + 3.4m² (caixa de alvenaria)
* Casa de 9 módulos = 225 painéis -> Casa de 7 módulos = 225 * 7/9 = 175 painéis
* 1 painel = +/- R$ 115 -> 175 painéis = R$ 20000
* Alternativa: 1 painel de OSB = */- R$ 100 - > 175 painéis = R$ 17500
* Precisa do custo de corte
* Custo da impregnação / proteção contra fogo
* Custo de fundação
* Custo do bloco de alvenaria completo (com instalações sanitárias)
* Custo do revestimento exterior = +/- 84m² (placas de polipropileno = R$ 41/m² x 84 = R$ 3500
* Custo conexões esgoto/água fria/eletricidade
* Pintura
* Custo portas e janelas -ver cálculo padrão abaixo
* Custo instalações elétricas
* Mobiliário?
* Custo maquete
* Custo transporte
* Custo projeto? Contribuição wikihouse
* Esquadrias: 28m² *x R$ 300/m² = R$ 8500
* Custo de uma máquina CNC?

### FreeCAD & arquivos digitais

Ajustes a fazer no FreeCAD para poder trabalhar com wikihouse. Tudo feito já.
* ~~Ver melhor formato de transferência~~ Precisa de um processo complexo para passar do formato original (sketchup) para FreeCAD. 1) No sketchup, isolar um módulo 2) exportar para collada 3) importar no Blender 4) separar as diferentes camadas de elementes em layers 5) identificar e linkar os idênticos 6) deixar somente uma face por peça 7) limpar a triangulação 8) exportar para obj 8) importar para FreeCAD 9) usar macro em anexo para extrair wires 10) criar clones para as peças duplicadas
* ~~Tornar cada peça do modelo sketchup em um painel~~
* ~~Identificar painéis idênticos~~ Isto tem que ser feito na hora de importar o arquivo para o Blender. Deixar os dois (blender e sketchup) abertos ao lado, e ir identificando cada peça. Esta etapa é também importante para ter um bom entendimento da estrutura.
* ~~Extrair "marca"?~~
* ~~Gerar perfis no plano XY. Cada perfil é "filho" do painel? Ou contrário?~~
* ~~Perfil podia ser Path (verificar se interessante)~~
### Links

#### Wikihouse

* http://buildandrenovate.co.nz/wikihouse/
* http://www.wikihouserio.cc/
* http://www.archdaily.com.br/br/773676/casa-revista-a-primeira-casa-fabricada-digitalmente-no-brasil
* https://www.newcivilengineer.com/technical-excellence/structures-home-delivery/8670782.article
* http://buildandrenovate.co.nz/wikihouse/
* http://www.plataformaarquitectura.cl/cl/800684/wikihouse-presenta-la-primera-casa-de-codigo-abierto-de-dos-pisos-en-el-london-design-festival

#### Materiais

* http://www.smartply.com/products/fr-build-osb3

### Próximos passos

* ~~Ver terreno com Reitor~~
* ~~Achar terreno~~
* Montar um projeto básico (3D, planta, corte)
* Verificar preços de corte
* Verificar preços da impregnação contra fogo
* Montar orçamento básico do resto (alvenaria, etc)

### Mobiliário necessário

#### makerspace

* 1 mesa de montagem (para trabalho) 8 lugares
* 1 mesa ou bancada para 2 impressoras lasers (+/- 3 metros)
* 2 armários fechados
* 2 mesas para computadores (3 em cada 1)
* 1 espaço para almofadas e conversas
* se possível colocar estantes em uma das paredes

#### Lablivre

* Uma mesa para 8 computadores
* 2 armários
* 2 hacks de servidores
* 1 mesa de reuniões 
* 1 espaço para projeção
* 1 mesa/bancada para impressoras
* estantes de livros (quto couber)

### Maquete

* Tamanho original: 175 painéis x 1.20m x 2.40m = 504 m²
* Escala: de 18mm para 2mm = 1:9
* 504 m² / 9 = 56 m² de painel de compensado de 2mm
* Tamanho da maquete: 46cm x 112 cm
* Custo do painel 2mm = R$ 25/m² = R$ 1400
* Custo do corte?

### Empresas CNC em So Paulo

* [Cutter CNC](http://www.cuttercnc.com/)
* [Corte Recorte](http://www.corterecorte.com.br/)
* [Forest CNC](http://forestcnc.com.br/)

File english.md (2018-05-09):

# wikilab



An experimental laboratory made with [wikihouse](http://wikihouse.cc/) technology, built on the [São Bernardo campus](https://www.google.com.br/maps/place/UFABC+-+Universidade+Federal+do+ABC+-+Campus+S%C3%A3o+Bernardo+do+Campo/@-23.6774308,-46.5664299,17z/data=!3m1!4b1!4m5!3m4!1s0x94ce43a800827001:0xb566e18f4220a86b!8m2!3d-23.6774308!4d-46.5642412?hl=en) of the [UFABC](http://www.ufabc.edu.br/) university, in the São Paulo area, Brazil. It is based on the wikihouse [wren module](https://github.com/wikihouseproject/Wren/wiki/Wren-Technical-Design-Guide) and also reuses some of the solutions experimented by the [casa modelo](http://www.archdaily.com.br/br/773676/casa-revista-a-primeira-casa-fabricada-digitalmente-no-brasil) project made at [URFJ](https://ufrj.br/) in 2015.

The laboratory hosts both the [Free Software Laboratory](http://pesquisa.ufabc.edu.br/lablivre/) of UFABC and a [Makerspace](https://en.wikipedia.org/wiki/Hackerspace) used by the [hacker communities of the ABC region](http://www.facebook.com/abcmakerspace/) and form a link between the university, free software, local community and  hacking/making movements.

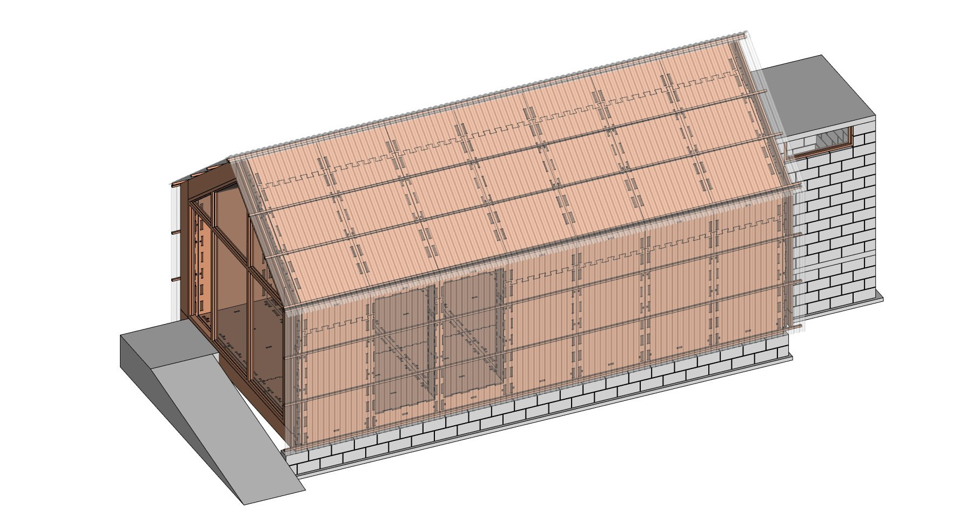
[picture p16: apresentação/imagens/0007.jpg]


*See also [a 3D version on Sketchfab](https://sketchfab.com/models/25cfcc0eaea24e3394ba76c1929d31ca)*

### The project

The project is now finished and built. The terrain has been donated by the university, and the construction costs covered by a [crowdfunding campaign](https://www.catarse.me/wikilab).

All the project documents, files, images, plans, spreadsheets, construction manuals and pictures taken during construction are [available online](https://github.com/uncreatednet/wikilab-ufabc).

The project development was done in portuguese, using open-source software, namely [FreeCAD](http//www.freecadweb.org), [Blender](http//www.blender.org), [libreOffice](http//www.libreoffice.org) and [inkscape](http://www.inkscape.org). In this project repository, you will find the project's 3D CAD file in [FreeCAD](wikilab.FCStd) and [Blender](wikilab.blend) formats, [renderings](apresenta%C3%A7%C3%A3o/imagens) and other images, [presentation documents](apresenta%C3%A7%C3%A3o/apresenta%C3%A7%C3%A3o%20inicial) in PDF format, and [cost and schedule estimations](or%C3%A7amento) in ODS format.

### The building system

The building adopts a hybrid system, with a base made in concrete blocks, on top of which the wikihouse system has been built. Finally, it is covered by a skin made of polypropylene, polycarbonate or fiber-cement panels.



This hybrid system is an interesting idea to use in this case, for several reasons:

* Being located in Southeast Brazil, which has a very mild climate, there is no need for protection against he cold. Gaps and weaknesses in the joints  between the wikihouse part and the masonry part are therefore not a big problem.
* All the hydraulic parts have been concentrated in the masonry parts, leaving the wooden part free of water tubes and appliances.
* The wooden wikihouse part is better protected against humidity by a good ventilation than by humidity barriers. Therefore, the outer skin is separated from the wooden structure, allowing air to flow between the two. The skin is open at the bottom and at the top, as well as on the front and back sides, to create natural convection with the heat generated by the sunrays hitting the exterior skin.
* These two sides also have openable windows, which create a constant ventilation on both the inner and outer sides of the wikihouse structure, and allow to dissipate the heat that could come through.
* If needed, further solutions to regulate the heat can be imagined when the building is functionning, such as sun breakers, or covering vegetation.
* The hybrid building system is also an interesting social experiment, as one part of the construction was executed by a contractor, while the other (the wikihouse part) was built by a team of volunteers. The interaction between these two actors was also part of the experiment. This way, the wikihouse system can also be more easily understood not as a revolution against traditional building techniques, but rather as an evolution.



### Collaborative approach

The adaptation of the Wikihouse [Wren module](https://github.com/wikihouseproject/Wren/wiki/Wren-Technical-Design-Guide) into this project has been done originally by Maíra and Yorik of [uncreated.net](http://www.uncreated.net) with almost no modification of the base module. The pretension was to build by the book, and follow the guidelines as close as possible, to minimize possible problems and also contribute with a kind of "tropical version" of the Wren module guidelines.

Another aim was to develop simple and adaptive ways to create natural climate control, using cheap techniques and materials. This is an ongoing process that will last for much longer than the construction time, as it will develop during the laboratory lifetime.

All these experiments are and will continue to be fully documented here, to be used by anybody interested. The whole process, including the further developments of the project, are open to anybody interested in contributing. Contact [Maíra or Yorik](http://www.uncreated.net), or simply create a [Github](http://www.github.com) account and open an issue on this repository to start a conversation. The project also has a [blog](https://wikilab.blog.br/) and a [Facebook page](https://www.facebook.com/wikilab.abc/) (in portuguese) and regularly organizes meetings in São Bernardo where anybody interested is welcome to participate.

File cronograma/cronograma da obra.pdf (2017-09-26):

Cronograma de obra | data: | 26.09.2017
← Início da obra | ← Fundação pronta | ← Estrutura de madeira pronta | Obra pronta →
Tarefa | Agosto | Setembro | Outubro
24 25 26 27 | 28 29 30 31 | 1 | 2 | 3 | 4 | 5 | 6 | 7 | 8 | 9 | 10 11 12 13 14 15 16 17 | 18 19 20 21 22 23 24 25 26 27 28 29 30 | 1 | 2 | 3 | 4 | 5 | 6 | 7 | 8 | 9 | 10 11 12 13 14 | 15
Q | S | S | D | S | T | Q | Q | S | S | D | S | T | Q | Q | S | S | D | S | T | Q | Q | S | S | D | S | T | Q | Q | S | S | D | S | T | Q | Q | S | S | D | S | T | Q | Q | S | S | D | S | T | Q | Q | S | S | D

Início da obra
Execução da fundação
Execução da alvenaria e das lajes Colocação das vigas-guia
Montagem da estrutura de madeira Colocação da estrutura de madeira Colocação dos painéis de fechamento Caixas de visita e tubulações enterradas Colocação das telhas
Colocação dos caixilhos
Instalação elétrica
Acabamentos

Executado
Empreiteira
Estudantes/Voluntários
Obra parada

## Lablivre Wikilab

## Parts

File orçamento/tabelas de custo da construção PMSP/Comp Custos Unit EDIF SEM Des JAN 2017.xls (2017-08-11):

CÓDIGO | NOME DO SERVIÇO |  |  |  | CUSTO UNIT. |  | UNID |  | VALOR
 |  | CODINS | NOMINS | UNID |  | COEF. |  | Vparc
10101 | LIMPEZA MECANIZADA GERAL, INCLUSIVE REMOÇÃO DA COBERTURA VEGETAL - TRONCOS COM DIÂMETRO ATÉ 10CM - SEM TRANSPORTE |  |  |  |  |  | M2 |  | 1.01
 |  | 02099 | SERVENTE (SGSP) | H | 16.60 | 0.009800 |  | 0.1627
 |  | 94061 | TRATOR DE ESTEIRA - 9 TON. | H | 173.23 | 0.004900 |  | 0.8489
10102 | DESTOCAMENTO, INCLUSIVE REMOÇÃO DAS RAÍZES - DIÂMETROS DE 10,01 À 30CM |  |  |  |  |  | UN |  | 33.46
 |  | 02099 | SERVENTE (SGSP) | H | 16.60 | 0.450000 |  | 7.4710
 |  | 94061 | TRATOR DE ESTEIRA - 9 TON. | H | 173.23 | 0.150000 |  | 25.9852
10103 | DESTOCAMENTO, INCLUSIVE REMOÇÃO DAS RAÍZES - DIÂMETRO 30,01 À 50 CM |  |  |  |  |  | UN |  | 93.01
 |  | 02099 | SERVENTE (SGSP) | H | 16.60 | 1.251000 |  | 20.7695
 |  | 94061 | TRATOR DE ESTEIRA - 9 TON. | H | 173.23 | 0.417000 |  | 72.2389
10104 | DESTOCAMENTO, INCLUSIVE REMOÇÃO DAS RAÍZES - DIÂMETROS MAIORES QUE 50 CM |  |  |  |  |  | UN |  | 110.81
 |  | 02099 | SERVENTE (SGSP) | H | 16.60 | 1.490400 |  | 24.7441
 |  | 94061 | TRATOR DE ESTEIRA - 9 TON. | H | 173.23 | 0.496800 |  | 86.0630
10105 | CARGA MECANIZADA E REMOÇÃO DE ENTULHO, INCLUSIVE TRANSPORTE ATÉ 1KM |  |  |  |  |  | M3 |  | 5.95
 |  | 94008 | CAMINHÃO BASCULANTE - 10 M3 | H | 127.19 | 0.029810 |  | 3.7916
 |  | 94015 | PÁ CARREGADEIRA DE PNEUS - 1,80 M3 | H | 143.83 | 0.015000 |  | 2.1575
10106 | CARGA MANUAL E REMOÇÃO DE ENTULHO, INCLUSIVE TRANSPORTE ATÉ 1 KM |  |  |  |  |  | M3 |  | 23.71
 |  | 02099 | SERVENTE (SGSP) | H | 16.60 | 1.200000 |  | 19.9228
 |  | 94008 | CAMINHÃO BASCULANTE - 10 M3 | H | 127.19 | 0.029810 |  | 3.7916
10107 | REMOÇÃO DE ENTULHO COM CAÇAMBA METÁLICA, INCLUSIVE CARGA MANUAL E DESCARGA EM BOTA-FORA |  |  |  |  |  | M3 |  | 79.92
 |  | 02099 | SERVENTE (SGSP) | H | 16.60 | 1.200000 |  | 19.9228
 |  | 79722 | ALUGUEL DE CAÇAMBA METÁLICA - CAPACIDADE 4 M3 P/ ENTULHO DE ALVENARIA | Un | 300.00 | 0.200000 |  | 60.0000
10108 | LIMPEZA MANUAL GERAL INCLUSIVE REMOÇÃO DE COBERTURA VEGETAL - TRONCO ATÉ 10CM - SEM TRANSPORTE |  |  |  |  |  | M2 |  | 4.15
 |  | 02099 | SERVENTE (SGSP) | H | 16.60 | 0.250000 |  | 4.1506
10109 | DESTOCAMENTO MANUAL, INCLUSIVE REMOÇÃO DE RAÍZES - DIÂMETRO 10,01 À 30 CM |  |  |  |  |  | UN |  | 49.81
 |  | 02099 | SERVENTE (SGSP) | H | 16.60 | 3.000000 |  | 49.8070
10110 | TRANSPORTE DE ENTULHO POR CAMINHÃO BASCULANTE, A PARTIR DE 1KM |  |  |  |  |  | M3XKM |  | 0.94
 |  | 94008 | CAMINHÃO BASCULANTE - 10 M3 | H | 127.19 | 0.007408 |  | 0.9422
10120 | CORTE, RECORTE E REMOÇÃO DE ÁRVORES INCLUSIVE RAIZES DIÂM. > 5 E < 15CM |  |  |  |  |  | UN |  | 149.26
 |  | 02099 | SERVENTE (SGSP) | H | 16.60 | 6.000000 |  | 99.6139
 |  | 94307 | MOTOSERRA A GASOLINA DE PEQUENO PORTE, POTÊNCIA MÍN. 4 CV | H | 24.83 | 2.000000 |  | 49.6508
10121 | CORTE, RECORTE E REMOÇÃO DE ÁRVORES INCLUSIVE RAIZES DIÂM. > 15 E < 30CM |  |  |  |  |  | UN |  | 337.41
 |  | 02099 | SERVENTE (SGSP) | H | 16.60 | 6.000000 |  | 99.6139
 |  | 94045 | RETROESCAVADEIRA - CAP. CAÇAMBA FRONTAL 0,76 M3 | H | 94.07 | 2.000000 |  | 188.1472
 |  | 94307 | MOTOSERRA A GASOLINA DE PEQUENO PORTE, POTÊNCIA MÍN. 4 CV | H | 24.83 | 2.000000 |  | 49.6508
10122 | CORTE, RECORTE E REMOÇÃO DE ÁRVORES INCLUSIVE RAIZES DIÂM. > 30 E < 60CM |  |  |  |  |  | UN |  | 421.76
 |  | 02099 | SERVENTE (SGSP) | H | 16.60 | 7.500000 |  | 124.5174
 |  | 94045 | RETROESCAVADEIRA - CAP. CAÇAMBA FRONTAL 0,76 M3 | H | 94.07 | 2.500000 |  | 235.1840
 |  | 94307 | MOTOSERRA A GASOLINA DE PEQUENO PORTE, POTÊNCIA MÍN. 4 CV | H | 24.83 | 2.500000 |  | 62.0634
10123 | CORTE, RECORTE E REMOÇÃO DE ÁRVORES INCLUSIVE RAIZES DIÂM. > 60 E < 90CM |  |  |  |  |  | UN |  | 506.12
 |  | 02099 | SERVENTE (SGSP) | H | 16.60 | 9.000000 |  | 149.4209
 |  | 94045 | RETROESCAVADEIRA - CAP. CAÇAMBA FRONTAL 0,76 M3 | H | 94.07 | 3.000000 |  | 282.2208
 |  | 94307 | MOTOSERRA A GASOLINA DE PEQUENO PORTE, POTÊNCIA MÍN. 4 CV | H | 24.83 | 3.000000 |  | 74.4761
10124 | CORTE, RECORTE E REMOÇÃO DE ÁRVORES INCLUSIVE RAIZES DIÂM. > 90CM |  |  |  |  |  | UN |  | 590.47
 |  | 02099 | SERVENTE (SGSP) | H | 16.60 | 10.500000 |  | 174.3244
 |  | 94045 | RETROESCAVADEIRA - CAP. CAÇAMBA FRONTAL 0,76 M3 | H | 94.07 | 3.500000 |  | 329.2576
 |  | 94307 | MOTOSERRA A GASOLINA DE PEQUENO PORTE, POTÊNCIA MÍN. 4 CV | H | 24.83 | 3.500000 |  | 86.8888
10201 | CORTE |  |  |  |  |  | M3 |  | 33.20
 |  | 02099 | SERVENTE (SGSP) | H | 16.60 | 2.000000 |  | 33.2046
10202 | CORTE E ESPALHAMENTO DENTRO DA OBRA |  |  |  |  |  | M3 |  | 41.51
 |  | 02099 | SERVENTE (SGSP) | H | 16.60 | 2.500000 |  | 41.5058
10205 | ATERRO, INCLUSIVE COMPACTAÇÃO |  |  |  |  |  | M3 |  | 24.90
 |  | 02099 | SERVENTE (SGSP) | H | 16.60 | 1.500000 |  | 24.9035
10210 | CARGA MECANIZADA E REMOÇÃO DE TERRA, INCLUSIVE TRANSPORTE ATÉ 1KM |  |  |  |  |  | M3 |  | 7.30
 |  | 94008 | CAMINHÃO BASCULANTE - 10 M3 | H | 127.19 | 0.037040 |  | 4.7112
 |  | 94015 | PÁ CARREGADEIRA DE PNEUS - 1,80 M3 | H | 143.83 | 0.018000 |  | 2.5889
10211 | CARGA MANUAL E REMOÇÃO DE TERRA, INCLUSIVE TRANSPORTE ATÉ 1 KM |  |  |  |  |  | M3 |  | 24.63
 |  | 02099 | SERVENTE (SGSP) | H | 16.60 | 1.200000 |  | 19.9228
 |  | 94008 | CAMINHÃO BASCULANTE - 10 M3 | H | 127.19 | 0.037040 |  | 4.7112
10301 | CORTE E ESPALHAMENTO DENTRO DA OBRA |  |  |  |  |  | M3 |  | 9.41
 |  | 94045 | RETROESCAVADEIRA - CAP. CAÇAMBA FRONTAL 0,76 M3 | H | 94.07 | 0.100000 |  | 9.4074
10302 | CORTE E ATERRO COMPACTADO |  |  |  |  |  | M3 |  | 10.74
 |  | 94014 | CAMINHÃO IRRIGADEIRA - 6000 L- BASCULANTE C/CABINE. | H | 101.68 | 0.010000 |  | 1.0168
 |  | 94029 | GRADE ARADORA DE 18 DISCOS | H | 2.77 | 0.010000 |  | 0.0277
 |  | 94038 | MOTONIVELADORA - 125 HP | H | 176.14 | 0.005000 |  | 0.8807
 |  | 94045 | RETROESCAVADEIRA - CAP. CAÇAMBA FRONTAL 0,76 M3 | H | 94.07 | 0.080000 |  | 7.5259
 |  | 94054 | ROLO COMPACTADOR VIBRATÓRIO DE UM CILINDRO PÉ DE CARNEIRO 7,5 TON | H | 94.44 | 0.005000 |  | 0.4722
 |  | 94059 | TRATOR DE TRAÇÃO AGRÍCOLA | H | 81.81 | 0.010000 |  | 0.8181
10303 | CORTE E CARREGAMENTO PARA BOTA-FORA, INCLUSIVE TRANSPORTE ATÉ 1KM |  |  |  |  |  | M3 |  | 12.64
 |  | 94008 | CAMINHÃO BASCULANTE - 10 M3 | H | 127.19 | 0.047040 |  | 5.9831
 |  | 94015 | PÁ CARREGADEIRA DE PNEUS - 1,80 M3 | H | 143.83 | 0.028000 |  | 4.0273
 |  | 94045 | RETROESCAVADEIRA - CAP. CAÇAMBA FRONTAL 0,76 M3 | H | 94.07 | 0.028000 |  | 2.6341
10305 | FORNECIMENTO DE TERRA, INCLUSIVE CORTE, CARGA, DESCARGA E TRANSPORTE ATÉ 1KM |  |  |  |  |  | M3 |  | 14.86
 |  | 94008 | CAMINHÃO BASCULANTE - 10 M3 | H | 127.19 | 0.047040 |  | 5.9831
 |  | 94015 | PÁ CARREGADEIRA DE PNEUS - 1,80 M3 | H | 143.83 | 0.028000 |  | 4.0273
 |  | 94061 | TRATOR DE ESTEIRA - 9 TON. | H | 173.23 | 0.028000 |  | 4.8506
10306 | ATERRO, INCLUSIVE COMPACTAÇÃO |  |  |  |  |  | M3 |  | 4.03
 |  | 02099 | SERVENTE (SGSP) | H | 16.60 | 0.049000 |  | 0.8135
 |  | 94014 | CAMINHÃO IRRIGADEIRA - 6000 L- BASCULANTE C/CABINE. | H | 101.68 | 0.010000 |  | 1.0168
 |  | 94029 | GRADE ARADORA DE 18 DISCOS | H | 2.77 | 0.010000 |  | 0.0277
 |  | 94038 | MOTONIVELADORA - 125 HP | H | 176.14 | 0.005000 |  | 0.8807
 |  | 94054 | ROLO COMPACTADOR VIBRATÓRIO DE UM CILINDRO PÉ DE CARNEIRO 7,5 TON | H | 94.44 | 0.005000 |  | 0.4722
 |  | 94059 | TRATOR DE TRAÇÃO AGRÍCOLA | H | 81.81 | 0.010000 |  | 0.8181
10310 | TRANSPORTE DE TERRA POR CAMINHÃO BASCULANTE, A PARTIR DE 1KM |  |  |  |  |  | M3XKM |  | 1.21
 |  | 94008 | CAMINHÃO BASCULANTE - 10 M3 | H | 127.19 | 0.009519 |  | 1.2107
10401 | ESCAVAÇÃO MANUAL, PROFUNDIDADE IGUAL OU INFERIOR A 1,50M |  |  |  |  |  | M3 |  | 49.81
 |  | 02099 | SERVENTE (SGSP) | H | 16.60 | 3.000000 |  | 49.8070
10402 | ESCAVAÇÃO MANUAL, PROFUNDIDADE SUPERIOR A 1,50M |  |  |  |  |  | M3 |  | 58.11
 |  | 02099 | SERVENTE (SGSP) | H | 16.60 | 3.500000 |  | 58.1081
10405 | ESCORAMENTO DE VALAS, CONTINUO |  |  |  |  |  | M2 |  | 65.31
 |  | 02013 | CARPINTEIRO (SGSP) | H | 20.44 | 1.333000 |  | 27.2512
 |  | 02014 | AJUDANTE DE CARPINTEIRO (SGSP) | H | 16.65 | 1.333000 |  | 22.1996
 |  | 11037 | EUCALIPTO D=20 / 30 CM NA BASE - 6M - SEM TRATAMENTO E SEM CASCA (CITRIODORA) | M | 54.80 | 0.104000 |  | 5.6992
 |  | 11050 | PEROBA DO NORTE (CUPIÚBA) - TÁBUA DE 3 X 16 CM - BRUTA | M | 7.10 | 1.050000 |  | 7.4550
 |  | 15516 | PEROBA DO NORTE (CUPIÚBA) - VIGA DE 6 X 16 CM - BRUTA | M | 16.25 | 0.100000 |  | 1.6250
 |  | 17515 | PREGO 18 X 27 COMUM - POLIDO | Kg | 5.42 | 0.200000 |  | 1.0840
10406 | ESCORAMENTO DE VALAS, DESCONTINUO |  |  |  |  |  | M2 |  | 40.14
 |  | 02013 | CARPINTEIRO (SGSP) | H | 20.44 | 0.800000 |  | 16.3548
 |  | 02014 | AJUDANTE DE CARPINTEIRO (SGSP) | H | 16.65 | 0.800000 |  | 13.3231
 |  | 11037 | EUCALIPTO D=20 / 30 CM NA BASE - 6M - SEM TRATAMENTO E SEM CASCA (CITRIODORA) | M | 54.80 | 0.104000 |  | 5.6992
 |  | 11050 | PEROBA DO NORTE (CUPIÚBA) - TÁBUA DE 3 X 16 CM - BRUTA | M | 7.10 | 0.350000 |  | 2.4850
 |  | 15516 | PEROBA DO NORTE (CUPIÚBA) - VIGA DE 6 X 16 CM - BRUTA | M | 16.25 | 0.100000 |  | 1.6250
 |  | 17515 | PREGO 18 X 27 COMUM - POLIDO | Kg | 5.42 | 0.120000 |  | 0.6504
10410 | APILOAMENTO DO FUNDO DE VALAS, PARA SIMPLES REGULARIZAÇÃO |  |  |  |  |  | M2 |  | 4.15
 |  | 02099 | SERVENTE (SGSP) | H | 16.60 | 0.250000 |  | 4.1506
10414 | LASTRO DE AGREGADO RECICLADO |  |  |  |  |  | M3 |  | 84.40
 |  | 02099 | SERVENTE (SGSP) | H | 16.60 | 2.000000 |  | 33.2046
 |  | 10502 | AGREGADO RECICLADO (DIVERSAS GLANULOMETRIAS) | M3 | 42.66 | 1.200000 |  | 51.1920
10415 | LASTRO DE BRITA |  |  |  |  |  | M3 |  | 118.03
 |  | 02099 | SERVENTE (SGSP) | H | 16.60 | 2.000000 |  | 33.2046
 |  | 10543 | PEDRA BRITADA NÚMERO 2 | M3 | 70.69 | 1.200000 |  | 84.8280
10416 | LASTRO DE CONCRETO, 150KG CIM/M3 |  |  |  |  |  | M3 |  | 314.20
 |  | 02020 | PEDREIRO (SGSP) | H | 20.31 | 2.000000 |  | 40.6293
 |  | 02099 | SERVENTE (SGSP) | H | 16.60 | 6.000000 |  | 99.6139
 |  | 10602 | CONCRETO FCK=5MPA C/ BRITA 1 E 2 | M3 | 165.68 | 1.050000 |  | 173.9606
10417 | LASTRO DE CONCRETO COM AGREGADO RECICLADO, 150 KG CIM/M3 |  |  |  |  |  | M3 |  | 286.79
 |  | 02020 | PEDREIRO (SGSP) | H | 20.31 | 2.000000 |  | 40.6293
 |  | 02099 | SERVENTE (SGSP) | H | 16.60 | 6.000000 |  | 99.6139
 |  | 10600 | CONCRETO FCK=5MPA C/ AGREGADO RECICLADO | M3 | 139.57 | 1.050000 |  | 146.5456
10420 | TUBO DE PEAD CORRUGADO E PERFURADOPARA DRENAGEM - DIÂMETRO 2,5" (EM ACORDO COM AS NORMAS DNIT 093/06, NBR 15073 E NBR 14692) |  |  |  |  |  | M |  | 17.36
 |  | 02035 | ENCANADOR (SGSP) | H | 21.17 | 0.220000 |  | 4.6564
 |  | 02036 | AJUDANTE DE ENCANADOR (SGSP) | H | 16.50 | 0.220000 |  | 3.6298
 |  | 72445 | TUBO DE PEAD CORRUG. E PERFUR. P/ DRENAG. DIÂM. 2,5" (EM ACORDO COM AS NORMAS DNIT 093/06 E NBR 15073) | M | 8.98 | 1.010000 |  | 9.0698
10421 | TUBO DE PEAD CORRUGADO E PERFURADOPARA DRENAGEM - DIÂMETRO 3,0" (EM ACORDO COM AS NORMAS DNIT 093/06, NBR 15073 E NBR 14692) |  |  |  |  |  | M |  | 19.32
 |  | 02035 | ENCANADOR (SGSP) | H | 21.17 | 0.220000 |  | 4.6564
 |  | 02036 | AJUDANTE DE ENCANADOR (SGSP) | H | 16.50 | 0.220000 |  | 3.6298
 |  | 72446 | TUBO DE PEAD CORRUG. E PERFUR. P/ DRENAG. DIÂM. 3,0" (EM ACORDO COM AS NORMAS DNIT 093/06 E NBR 15073) | M | 10.92 | 1.010000 |  | 11.0292
10422 | TUBO DE PEAD CORRUGADO E PERFURADOPARA DRENAGEM - DIÂMETRO 4,0" (EM ACORDO COM AS NORMAS DNIT 093/06, NBR 15073 E NBR 14692) |  |  |  |  |  | M |  | 22.23
 |  | 02035 | ENCANADOR (SGSP) | H | 21.17 | 0.220000 |  | 4.6564
 |  | 02036 | AJUDANTE DE ENCANADOR (SGSP) | H | 16.50 | 0.220000 |  | 3.6298
 |  | 72447 | TUBO DE PEAD CORRUG. E PERFUR. P/ DRENAG. DIÂM. 4,0" (EM ACORDO COM AS NORMAS DNIT 093/06 E NBR 15073) | M | 13.81 | 1.010000 |  | 13.9481
10423 | TUBO DE PEAD CORRUGADO E PERFURADOPARA DRENAGEM - DIÂMETRO 6,0" (EM ACORDO COM AS NORMAS DNIT 093/06, NBR 15073 E NBR 14692) |  |  |  |  |  | M |  | 39.85
 |  | 02035 | ENCANADOR (SGSP) | H | 21.17 | 0.220000 |  | 4.6564
 |  | 02036 | AJUDANTE DE ENCANADOR (SGSP) | H | 16.50 | 0.220000 |  | 3.6298
 |  | 72448 | TUBO DE PEAD CORRUG. E PERFUR. P/ DRENAG. DIÂM. 6.0" (EM ACORDO COM AS NORMAS DNIT 093/06 E NBR 15073) | M | 31.25 | 1.010000 |  | 31.5625
10426 | TUBO PVC PERFURADO PARA DRENAGEM - DIÂMETRO 4" (100MM) |  |  |  |  |  | M |  | 28.68
 |  | 02035 | ENCANADOR (SGSP) | H | 21.17 | 0.222000 |  | 4.6987
 |  | 02036 | AJUDANTE DE ENCANADOR (SGSP) | H | 16.50 | 0.222000 |  | 3.6628
 |  | 72442 | TUBO DE PVC CORRUGADO E PERFURADO P/ DRENO 4" | M | 20.12 | 1.010000 |  | 20.3212
10427 | TUBO PVC PERFURADO PARA DRENAGEM - DIÂMETRO 6" (150MM) |  |  |  |  |  | M |  | 53.02
 |  | 02035 | ENCANADOR (SGSP) | H | 21.17 | 0.222000 |  | 4.6987
 |  | 02036 | AJUDANTE DE ENCANADOR (SGSP) | H | 16.50 | 0.222000 |  | 3.6628
 |  | 72444 | TUBO DE PVC CORRUGADO E PERFURADO P/ DRENO 6" | M | 44.22 | 1.010000 |  | 44.6622
10430 | TUBO DE CONCRETO - DIÂMETRO DE 30CM |  |  |  |  |  | M |  | 34.84
 |  | 02020 | PEDREIRO (SGSP) | H | 20.31 | 0.064000 |  | 1.3001
 |  | 02099 | SERVENTE (SGSP) | H | 16.60 | 0.097000 |  | 1.6104
 |  | 10630 | ARGAMASSA DE CIMENTO COM AREIA GROSSA 1:3 | M3 | 464.69 | 0.000800 |  | 0.3717
 |  | 70002 | TUBO DE CONCRETO SIMPLES PS -1 D = 300 MM | M | 31.56 | 1.000000 |  | 31.5600
10431 | TUBO DE CONCRETO - DIÂMETRO DE 40CM |  |  |  |  |  | M |  | 49.63
 |  | 02020 | PEDREIRO (SGSP) | H | 20.31 | 0.092000 |  | 1.8689
 |  | 02099 | SERVENTE (SGSP) | H | 16.60 | 0.142000 |  | 2.3575
 |  | 10630 | ARGAMASSA DE CIMENTO COM AREIA GROSSA 1:3 | M3 | 464.69 | 0.001100 |  | 0.5112
 |  | 70003 | TUBO DE CONCRETO SIMPLES PS -1 D = 400 MM | M | 40.19 | 1.000000 |  | 40.1900
 |  | 94045 | RETROESCAVADEIRA - CAP. CAÇAMBA FRONTAL 0,76 M3 | H | 94.07 | 0.050000 |  | 4.7037
10432 | TUBO DE CONCRETO - DIÂMETRO DE 50CM |  |  |  |  |  | M |  | 69.58
 |  | 02020 | PEDREIRO (SGSP) | H | 20.31 | 0.122300 |  | 2.4845
 |  | 02099 | SERVENTE (SGSP) | H | 16.60 | 0.192300 |  | 3.1926
 |  | 10630 | ARGAMASSA DE CIMENTO COM AREIA GROSSA 1:3 | M3 | 464.69 | 0.001400 |  | 0.6506
 |  | 70004 | TUBO DE CONCRETO SIMPLES PS -1 D = 500 MM | M | 56.67 | 1.000000 |  | 56.6700
 |  | 94045 | RETROESCAVADEIRA - CAP. CAÇAMBA FRONTAL 0,76 M3 | H | 94.07 | 0.070000 |  | 6.5852
10433 | TUBO DE CONCRETO - DIÂMETRO DE 60CM |  |  |  |  |  | M |  | 85.61
 |  | 02020 | PEDREIRO (SGSP) | H | 20.31 | 0.152700 |  | 3.1020
 |  | 02099 | SERVENTE (SGSP) | H | 16.60 | 0.242700 |  | 4.0294
 |  | 10630 | ARGAMASSA DE CIMENTO COM AREIA GROSSA 1:3 | M3 | 464.69 | 0.001600 |  | 0.7435
 |  | 70005 | TUBO DE CONCRETO SIMPLES PS -1 D = 600 MM | M | 69.27 | 1.000000 |  | 69.2700
 |  | 94045 | RETROESCAVADEIRA - CAP. CAÇAMBA FRONTAL 0,76 M3 | H | 94.07 | 0.090000 |  | 8.4666
10435 | TUBO DE CONCRETO - DIÂMETRO DE 80CM |  |  |  |  |  | M |  | 187.57
 |  | 02020 | PEDREIRO (SGSP) | H | 20.31 | 0.223700 |  | 4.5444
 |  | 02099 | SERVENTE (SGSP) | H | 16.60 | 0.363700 |  | 6.0383
 |  | 10630 | ARGAMASSA DE CIMENTO COM AREIA GROSSA 1:3 | M3 | 464.69 | 0.002100 |  | 0.9758
 |  | 70027 | TUBO DE CONCRETO ARMADO PA -2 D = 0,80M | M | 162.84 | 1.000000 |  | 162.8400
 |  | 94045 | RETROESCAVADEIRA - CAP. CAÇAMBA FRONTAL 0,76 M3 | H | 94.07 | 0.140000 |  | 13.1703
10437 | TUBO DE CONCRETO - DIÂMETRO DE 100CM |  |  |  |  |  | M |  | 263.09
 |  | 02020 | PEDREIRO (SGSP) | H | 20.31 | 0.234700 |  | 4.7678
 |  | 02099 | SERVENTE (SGSP) | H | 16.60 | 0.364700 |  | 6.0549
 |  | 10630 | ARGAMASSA DE CIMENTO COM AREIA GROSSA 1:3 | M3 | 464.69 | 0.002600 |  | 1.2082
 |  | 70029 | TUBO DE CONCRETO ARMADO PA -2 D = 1,00M | M | 231.58 | 1.000000 |  | 231.5800
 |  | 94233 | ESCAVADEIRA HIDRÁULICA SOBRE ESTEIRAS CAP. 1,50 M3 | H | 149.85 | 0.130000 |  | 19.4806
10439 | TUBO DE CONCRETO - DIÂMETRO DE 120CM |  |  |  |  |  | M |  | 415.60
 |  | 02020 | PEDREIRO (SGSP) | H | 20.31 | 0.345700 |  | 7.0228
 |  | 02099 | SERVENTE (SGSP) | H | 16.60 | 0.565700 |  | 9.3919
 |  | 10630 | ARGAMASSA DE CIMENTO COM AREIA GROSSA 1:3 | M3 | 464.69 | 0.003200 |  | 1.4870
 |  | 70031 | TUBO DE CONCRETO ARMADO PA -2 D = 1,20M | M | 364.73 | 1.000000 |  | 364.7300
 |  | 94233 | ESCAVADEIRA HIDRÁULICA SOBRE ESTEIRAS CAP. 1,50 M3 | H | 149.85 | 0.220000 |  | 32.9671
10448 | CAIXA DE LIGAÇÃO OU INSPEÇÃO - ESCAVAÇÃO E APILOAMENTO |  |  |  |  |  | M3 |  | 44.83
 |  | 02099 | SERVENTE (SGSP) | H | 16.60 | 2.700000 |  | 44.8263
10449 | CAIXA DE LIGAÇÃO OU INSPEÇÃO - LASTRO DE CONCRETO (FUNDO) |  |  |  |  |  | M3 |  | 336.70
 |  | 02020 | PEDREIRO (SGSP) | H | 20.31 | 2.000000 |  | 40.6293
 |  | 02099 | SERVENTE (SGSP) | H | 16.60 | 6.000000 |  | 99.6139
 |  | 10604 | CONCRETO FCK=10MPA C/ BRITA 2 | M3 | 187.10 | 1.050000 |  | 196.4539
10450 | CAIXA DE LIGAÇÃO OU INSPEÇÃO - ALVENARIA DE 1/2 TIJOLO, REVESTIDA |  |  |  |  |  | M2 |  | 180.79
 |  | 02020 | PEDREIRO (SGSP) | H | 20.31 | 4.030000 |  | 81.8680
 |  | 02099 | SERVENTE (SGSP) | H | 16.60 | 3.020000 |  | 50.1390
 |  | 10636 | ARGAMASSA DE CIMENTO COM AREIA GROSSA 1:6 | M3 | 362.63 | 0.014000 |  | 5.0768
 |  | 10648 | ARGAMASSA MISTA COM AREIA GROSSA 1:2:8 | M3 | 411.63 | 0.047000 |  | 19.3465
 |  | 12580 | TIJOLO MAÇICO DE BARRO COMUM | Un | 0.29 | 84.000000 |  | 24.3600
10451 | CAIXA DE LIGAÇÃO OU INSPEÇÃO - ALVENARIA DE 1 TIJOLO, REVESTIDA |  |  |  |  |  | M2 |  | 250.62
 |  | 02020 | PEDREIRO (SGSP) | H | 20.31 | 4.490000 |  | 91.2127
 |  | 02099 | SERVENTE (SGSP) | H | 16.60 | 4.907000 |  | 81.4676
 |  | 10636 | ARGAMASSA DE CIMENTO COM AREIA GROSSA 1:6 | M3 | 362.63 | 0.014000 |  | 5.0768
 |  | 10648 | ARGAMASSA MISTA COM AREIA GROSSA 1:2:8 | M3 | 411.63 | 0.065000 |  | 26.7558
 |  | 12580 | TIJOLO MAÇICO DE BARRO COMUM | Un | 0.29 | 159.000000 |  | 46.1100
10452 | CAIXA DE LIGAÇÃO OU INSPEÇÃO - TAMPA DE CONCRETO |  |  |  |  |  | M2 |  | 165.03
 |  | 02013 | CARPINTEIRO (SGSP) | H | 20.44 | 2.420000 |  | 49.4734
 |  | 02014 | AJUDANTE DE CARPINTEIRO (SGSP) | H | 16.65 | 2.420000 |  | 40.3024
 |  | 02015 | FERREIRO (SGSP) | H | 20.57 | 0.460000 |  | 9.4633
 |  | 02016 | AJUDANTE DE FERREIRO - ARMADOR (SGSP) | H | 18.05 | 0.460000 |  | 8.3012
 |  | 02020 | PEDREIRO (SGSP) | H | 20.31 | 0.300000 |  | 6.0944
 |  | 02099 | SERVENTE (SGSP) | H | 16.60 | 0.800000 |  | 13.2819
 |  | 10608 | CONCRETO FCK=15MPA C/ BRITA 2 | M3 | 242.90 | 0.050000 |  | 12.1450
 |  | 11021 | COMPENSADO RESINADO 12MM COLA BRANCA - CHAPA DE 2,20 X 1,10 M | M2 | 13.73 | 0.400000 |  | 5.4920
 |  | 11070 | PINUS - TÁBUA DE 1" X 12" - BRUTA | M | 5.14 | 0.400000 |  | 2.0560
 |  | 11520 | AÇO CA-60B - MÉDIA BITOLAS | KG | 3.40 | 5.270000 |  | 17.9312
 |  | 17740 | ARAME RECOZIDO N. 16 E N. 18 | Kg | 5.41 | 0.090000 |  | 0.4869
10470 | ENVOLVIMENTO DE TUBOS COM BRITA |  |  |  |  |  | M3 |  | 126.33
 |  | 02099 | SERVENTE (SGSP) | H | 16.60 | 2.500000 |  | 41.5058
 |  | 10543 | PEDRA BRITADA NÚMERO 2 | M3 | 70.69 | 1.200000 |  | 84.8280
10471 | ENVOLVIMENTO DE TUBOS COM AREIA |  |  |  |  |  | M3 |  | 146.42
 |  | 02099 | SERVENTE (SGSP) | H | 16.60 | 3.500000 |  | 58.1081
 |  | 10501 | AREIA LAVADA | M3 | 76.79 | 1.150000 |  | 88.3121
10475 | MANTA GEOTÊXTIL |  |  |  |  |  | M2 |  | 5.17
 |  | 02020 | PEDREIRO (SGSP) | H | 20.31 | 0.030000 |  | 0.6094
 |  | 24110 | MANTA GEOTÊXTIL C/ RESISTÊNCIA À TRAÇÃO LONG. DE 16 KN/M E TRAÇÃO TRANSV. 14 KN/M | M2 | 4.34 | 1.050000 |  | 4.5570
10476 | FORNECIMENTO E APLICAÇÃO DE GEOMEMBRANA DE PEAD - 1MM DE ESPESSURA |  |  |  |  |  | M2 |  | 23.20
 |  | 24120 | GEOMEMBRANA DE 1MM DE ESPESSURA DE PEAD | M2 | 16.57 | 1.400000 |  | 23.1980
10477 | FORNECIMENTO E APLICAÇÃO DE MANTA FORMADA PELA ASSOCIAÇÃO DE UM TECIDO TÉCNICO DE POLIESTER COM UM FILME DE POLIETILENO DE BAIXA DENSIDADE EM ACORDO COM A NBR 12824 |  |  |  |  |  | M2 |  | 17.21
 |  | 02020 | PEDREIRO (SGSP) | H | 20.31 | 0.030000 |  | 0.6094
 |  | 24121 | MANTA FORMADA PELA ASSOC. DE TECIDO TÉCN. DE POLIÉSTER C/ FILME DE POLIETILENO DE BAIXA INTENS, DE ACORDO C/NBR 12824 | M2 | 15.81 | 1.050000 |  | 16.6005
10478 | FORNECIMENTO E APLICAÇÃO DE GEOCOMPOSTO FORMADO POR NÚCLEO TRIDIMENSIONAL, FLEXÍVEL DE FILAMENTO DE POLIPROPILENO, ASSOCIADO ÀS SUAS DUAS SUPERFÍCIES GEOTEXTEIS NÃO TECIDOS |  |  |  |  |  | M2 |  | 24.51
 |  | 02020 | PEDREIRO (SGSP) | H | 20.31 | 0.030000 |  | 0.6094
 |  | 24122 | GEOCOMPOSTO FORMADO POR NÚCLEO TRIDIMENSIONAL FLEXÍVEL DE FILAM. POLIPROPILENO ASSOC. ÀS SUAS DS SUPERF.GEOT. NÃO TEC. | M2 | 22.76 | 1.050000 |  | 23.8980
10480 | REATERRO DE VALAS, INCLUSIVE COMPACTAÇÃO |  |  |  |  |  | M3 |  | 9.97
 |  | 02099 | SERVENTE (SGSP) | H | 16.60 | 0.500000 |  | 8.3012
 |  | 94221 | COMPACTADOR MANUAL DE PLACA VIBRATÓRIA REVERSÍVEL 282 KG | H | 26.91 | 0.062000 |  | 1.6686
10501 | TAPUME CHAPA COMPENSADA 6MM |  |  |  |  |  | M2 |  | 47.34
 |  | 02013 | CARPINTEIRO (SGSP) | H | 20.44 | 0.800000 |  | 16.3548
 |  | 02099 | SERVENTE (SGSP) | H | 16.60 | 0.800000 |  | 13.2819
 |  | 11019 | COMPENSADO RESINADO 6 MM COLA BRANCA - CHAPA DE 2,20 X 1,10 M | M2 | 7.45 | 1.100000 |  | 8.1950
 |  | 11046 | PINUS - PONTALETE DE 3" X 3" - BRUTO | M | 2.76 | 3.150000 |  | 8.6940
 |  | 17515 | PREGO 18 X 27 COMUM - POLIDO | Kg | 5.42 | 0.150000 |  | 0.8130
10502 | TAPUME CHAPA COMPENSADA RESINADA 10MM |  |  |  |  |  | M2 |  | 51.50
 |  | 02013 | CARPINTEIRO (SGSP) | H | 20.44 | 0.800000 |  | 16.3548
 |  | 02099 | SERVENTE (SGSP) | H | 16.60 | 0.800000 |  | 13.2819
 |  | 11020 | COMPENSADO RESINADO 10MM COLA BRANCA - CHAPA DE 2,20 X 1,10 M | M2 | 11.23 | 1.100000 |  | 12.3530
 |  | 11046 | PINUS - PONTALETE DE 3" X 3" - BRUTO | M | 2.76 | 3.150000 |  | 8.6940
 |  | 17515 | PREGO 18 X 27 COMUM - POLIDO | Kg | 5.42 | 0.150000 |  | 0.8130
10505 | TAPUME METÁLICO COM TELHA METÁLICA, SEM PINTURA, TRAPEZOIDAL 40 ESP=0,43MM, COLUNAS, BASES E PARAFUSOS |  |  |  |  |  | M2 |  | 113.11
 |  | 02020 | PEDREIRO (SGSP) | H | 20.31 | 0.200000 |  | 4.0629
 |  | 02045 | SERRALHEIRO (SGSP) | H | 40.55 | 1.000000 |  | 40.5519
 |  | 02046 | AJUDANTE DE SERRALHEIRO (SGSP) | H | 17.53 | 1.000000 |  | 17.5304
 |  | 02099 | SERVENTE (SGSP) | H | 16.60 | 1.200000 |  | 19.9228
 |  | 16420 | TAPUME METÁLICO COM TELHA METÁLICA, SEM PINTURA,TRAPEZOIDAL 40-ESP. 0,43MM, COLUNAS, BASES E PARAFUSOS | M2 | 72.19 | 0.430000 |  | 31.0417
10506 | PORTÃO METÁLICO DE OBRA - 5M, PIVOTANTE, 2 FOLHAS, PARA TAPUME |  |  |  |  |  | M2 |  | 181.86
 |  | 02020 | PEDREIRO (SGSP) | H | 20.31 | 0.200000 |  | 4.0629
 |  | 02045 | SERRALHEIRO (SGSP) | H | 40.55 | 1.000000 |  | 40.5519
 |  | 02046 | AJUDANTE DE SERRALHEIRO (SGSP) | H | 17.53 | 1.000000 |  | 17.5304
 |  | 02099 | SERVENTE (SGSP) | H | 16.60 | 1.200000 |  | 19.9228
 |  | 30746 | PORTÃO METÁLICO DE OBRA 5m, PIVOTANTE,2 FOLHAS, PARA TAPUME METÁLICO | M2 | 232.07 | 0.430000 |  | 99.7901
10507 | PORTÃO DE PEDESTRES - 1,15M, PARA TAPUME |  |  |  |  |  | M2 |  | 169.19
 |  | 02020 | PEDREIRO (SGSP) | H | 20.31 | 0.200000 |  | 4.0629
 |  | 02045 | SERRALHEIRO (SGSP) | H | 40.55 | 1.000000 |  | 40.5519
 |  | 02046 | AJUDANTE DE SERRALHEIRO (SGSP) | H | 17.53 | 1.000000 |  | 17.5304
 |  | 02099 | SERVENTE (SGSP) | H | 16.60 | 1.200000 |  | 19.9228
 |  | 30747 | PORTÃO DE PEDESTRES - 1,15 M, PARA TABUME METÁLICO | M2 | 202.62 | 0.430000 |  | 87.1266
10540 | TELA PARA PROTEÇÃO DE OBRAS, MALHA 2 MM |  |  |  |  |  | M2 |  | 20.06
 |  | 02013 | CARPINTEIRO (SGSP) | H | 20.44 | 0.440000 |  | 8.9952
 |  | 02014 | AJUDANTE DE CARPINTEIRO (SGSP) | H | 16.65 | 0.530000 |  | 8.8266
 |  | 11046 | PINUS - PONTALETE DE 3" X 3" - BRUTO | M | 2.76 | 0.060000 |  | 0.1656
 |  | 11066 | PINUS - SARRAFO DE 1" X 4" - BRUTO | M | 1.34 | 0.200000 |  | 0.2680
 |  | 17515 | PREGO 18 X 27 COMUM - POLIDO | Kg | 5.42 | 0.010000 |  | 0.0542
 |  | 38043 | TELA POLIETILENO P/ PROTEÇÃO DE FACHADA-TRAMA 2,2MM | M2 | 1.59 | 1.100000 |  | 1.7490
20101 | BROCA DE CONCRETO - DIÂMETRO DE 20CM |  |  |  |  |  | M |  | 39.29
 |  | 02015 | FERREIRO (SGSP) | H | 20.57 | 0.050000 |  | 1.0286
 |  | 02016 | AJUDANTE DE FERREIRO - ARMADOR (SGSP) | H | 18.05 | 0.050000 |  | 0.9023
 |  | 02020 | PEDREIRO (SGSP) | H | 20.31 | 0.160000 |  | 3.2503
 |  | 02099 | SERVENTE (SGSP) | H | 16.60 | 1.460000 |  | 24.2394
 |  | 10608 | CONCRETO FCK=15MPA C/ BRITA 2 | M3 | 242.90 | 0.031400 |  | 7.6271
 |  | 11501 | AÇO CA-25 - MÉDIA BITOLAS | KG | 3.47 | 0.630000 |  | 2.1882
 |  | 17740 | ARAME RECOZIDO N. 16 E N. 18 | Kg | 5.41 | 0.010000 |  | 0.0541
20102 | BROCA DE CONCRETO - DIÂMETRO DE 25CM |  |  |  |  |  | M |  | 59.44
 |  | 02015 | FERREIRO (SGSP) | H | 20.57 | 0.060000 |  | 1.2343
 |  | 02016 | AJUDANTE DE FERREIRO - ARMADOR (SGSP) | H | 18.05 | 0.060000 |  | 1.0828
 |  | 02020 | PEDREIRO (SGSP) | H | 20.31 | 0.190000 |  | 3.8598
 |  | 02099 | SERVENTE (SGSP) | H | 16.60 | 2.281280 |  | 37.8745
 |  | 10608 | CONCRETO FCK=15MPA C/ BRITA 2 | M3 | 242.90 | 0.049000 |  | 11.9021
 |  | 11501 | AÇO CA-25 - MÉDIA BITOLAS | KG | 3.47 | 0.980000 |  | 3.4039
 |  | 17740 | ARAME RECOZIDO N. 16 E N. 18 | Kg | 5.41 | 0.015100 |  | 0.0817
20103 | BROCA DE CONCRETO - DIÂMETRO DE 30CM |  |  |  |  |  | M |  | 88.51
 |  | 02015 | FERREIRO (SGSP) | H | 20.57 | 0.115200 |  | 2.3699
 |  | 02016 | AJUDANTE DE FERREIRO - ARMADOR (SGSP) | H | 18.05 | 0.115200 |  | 2.0789
 |  | 02020 | PEDREIRO (SGSP) | H | 20.31 | 0.360000 |  | 7.3133
 |  | 02099 | SERVENTE (SGSP) | H | 16.60 | 3.285410 |  | 54.5454
 |  | 10608 | CONCRETO FCK=15MPA C/ BRITA 2 | M3 | 242.90 | 0.070600 |  | 17.1487
 |  | 11501 | AÇO CA-25 - MÉDIA BITOLAS | KG | 3.47 | 1.411200 |  | 4.9017
 |  | 17740 | ARAME RECOZIDO N. 16 E N. 18 | Kg | 5.41 | 0.028800 |  | 0.1558
20105 | ESTACA DE CONCRETO MOLDADA NO LOCAL, TIPO "STRAUSS" - ATÉ 20T |  |  |  |  |  | M |  | 44.71
 |  | 02099 | SERVENTE (SGSP) | H | 16.60 | 0.100000 |  | 1.6602
 |  | 10010 | CRAVAÇÃO DE ESTACAS MOLDADAS NO LOCAL TIPO STRAUSS D=25 CM (ATÉ 20 TON) | M | 29.50 | 1.000000 |  | 29.5000
 |  | 10608 | CONCRETO FCK=15MPA C/ BRITA 2 | M3 | 242.90 | 0.049000 |  | 11.9021
 |  | 11501 | AÇO CA-25 - MÉDIA BITOLAS | KG | 3.47 | 0.460000 |  | 1.5978
 |  | 17740 | ARAME RECOZIDO N. 16 E N. 18 | Kg | 5.41 | 0.010000 |  | 0.0541
20106 | ESTACA DE CONCRETO MOLDADA NO LOCAL, TIPO "STRAUSS" - ATÉ 30T |  |  |  |  |  | M |  | 56.78
 |  | 02099 | SERVENTE (SGSP) | H | 16.60 | 0.100000 |  | 1.6602
 |  | 10011 | CRAVAÇÃO DE ESTACAS MOLDADAS NO LOCAL TIPO STRAUSS D=32 CM (ATÉ 30 TON) | M | 34.04 | 1.000000 |  | 34.0400
 |  | 10608 | CONCRETO FCK=15MPA C/ BRITA 2 | M3 | 242.90 | 0.080000 |  | 19.4320
 |  | 11501 | AÇO CA-25 - MÉDIA BITOLAS | KG | 3.47 | 0.460000 |  | 1.5978
 |  | 17740 | ARAME RECOZIDO N. 16 E N. 18 | Kg | 5.41 | 0.010000 |  | 0.0541
20107 | ESTACA DE CONCRETO MOLDADA NO LOCAL, TIPO "STRAUSS" - ATÉ 40T |  |  |  |  |  | M |  | 72.51
 |  | 02099 | SERVENTE (SGSP) | H | 16.60 | 0.100000 |  | 1.6602
 |  | 10012 | CRAVAÇÃO DE ESTACAS MOLDADAS NO LOCAL TIPO STRAUSS D=38 CM (ATÉ 40 TON) | M | 40.52 | 1.000000 |  | 40.5200
 |  | 10608 | CONCRETO FCK=15MPA C/ BRITA 2 | M3 | 242.90 | 0.113000 |  | 27.4477
 |  | 11501 | AÇO CA-25 - MÉDIA BITOLAS | KG | 3.47 | 0.800000 |  | 2.7787
 |  | 17740 | ARAME RECOZIDO N. 16 E N. 18 | Kg | 5.41 | 0.020000 |  | 0.1082
20108 | ESTACA DE CONCRETO MOLDADA NO LOCAL, TIPO "STRAUSS" - ATÉ 60T |  |  |  |  |  | M |  | 96.36
 |  | 02099 | SERVENTE (SGSP) | H | 16.60 | 0.150000 |  | 2.4903
 |  | 10013 | CRAVAÇÃO DE ESTACAS MOLDADAS NO LOCAL TIPO STRAUSS D=45 CM (ATÉ 60 TON) | M | 58.92 | 1.000000 |  | 58.9200
 |  | 10608 | CONCRETO FCK=15MPA C/ BRITA 2 | M3 | 242.90 | 0.132000 |  | 32.0628
 |  | 11501 | AÇO CA-25 - MÉDIA BITOLAS | KG | 3.47 | 0.800000 |  | 2.7787
 |  | 17740 | ARAME RECOZIDO N. 16 E N. 18 | Kg | 5.41 | 0.020000 |  | 0.1082
20120 | TUBULÃO - ESCAVAÇÃO A CÉU ABERTO, COM PÁ E PICARETA |  |  |  |  |  | M3 |  | 373.55
 |  | 02008 | POCEIRO - EXECUTA ESCAVAÇÃO A CÉU ABERTO (SGSP) | H | 19.34 | 10.000000 |  | 193.3500
 |  | 02009 | AJUDANTE DE POCEIRO - EXECUTA ESCAVAÇÃO A CÉU ABERTO (SGSP) | H | 18.02 | 10.000000 |  | 180.2022
20134 | TUBULÃO A CÉU ABERTO FCK=20 MPA |  |  |  |  |  | M3 |  | 497.35
 |  | 02020 | PEDREIRO (SGSP) | H | 20.31 | 2.000000 |  | 40.6293
 |  | 02099 | SERVENTE (SGSP) | H | 16.60 | 12.000000 |  | 199.2278
 |  | 10524 | CONCRETO USINADO, BRITA 1E2,SLUMP 5+OU-1cm / FCK= 20,0MPA | M3 | 257.49 | 1.000000 |  | 257.4900
20138 | ESTACA DE CONCRETO PRÉ-MOLDADA COM CARGA ADMISSÍVEL PARA ESTRUTURA DE 20 T |  |  |  |  |  | M |  | 67.03
 |  | 10001 | FORNECIMENTO E CRAVAÇÃO DE ESTACA DE CONCRETO PRÉ-MOLDADA COM CARGA ADMISSÍVEL P/ ESTRUTURA DE 20T - ATÉ 10M | M | 65.08 | 1.030000 |  | 67.0324
20139 | ESTACA DE CONCRETO PRÉ-MOLDADA COM CARGA ADMISSÍVEL PARA ESTRUTURA DE 30 T |  |  |  |  |  | M |  | 87.96
 |  | 10002 | FORNECIMENTO E CRAVAÇÃO DE ESTACA DE CONCRETO PRÉ-MOLDADA COM CARGA ADMISSÍVEL P/ ESTRUTURA DE 30T - ATÉ 10M | M | 85.40 | 1.030000 |  | 87.9620
20140 | ESTACA DE CONCRETO PRÉ-MOLDADA COM CARGA ADMISSÍVEL PARA ESTRUTURA DE 40 T |  |  |  |  |  | M |  | 101.75
 |  | 10003 | FORNECIMENTO E CRAVAÇÃO DE ESTACA DE CONCRETO PRÉ-MOLDADA COM CARGA ADMISSÍVEL P/ ESTRUTURA DE 40T - ATÉ 10M | M | 98.79 | 1.030000 |  | 101.7537
20141 | ESTACA DE CONCRETO PRÉ-MOLDADA COM CARGA ADMISSÍVEL PARA ESTRUTURA DE 60 T |  |  |  |  |  | M |  | 144.87
 |  | 10004 | FORNECIMENTO E CRAVAÇÃO DE ESTACA DE CONCRETO PRÉ-MOLDADA COM CARGA ADMISSÍVEL P/ ESTRUTURA DE 60T - ATÉ 10M | M | 140.65 | 1.030000 |  | 144.8695
20142 | ESTACA DE CONCRETO PRÉ-MOLDADA COM CARGA ADMISSÍVEL PARA ESTRUTURA DE 70 T |  |  |  |  |  | M |  | 177.84
 |  | 10005 | FORNECIMENTO E CRAVAÇÃO DE ESTACA DE CONCRETO PRÉ-MOLDADA COM CARGA ADMISSÍVEL P/ ESTRUTURA DE 70T - ATÉ 10M | M | 172.66 | 1.030000 |  | 177.8398
20143 | EMENDA DE ESTACA DE CONCRETO PRÉ-MOLDADA - DIÂMETRO 17 CM - 20 T |  |  |  |  |  | UN |  | 29.62
 |  | 10060 | EMENDA DE ESTACA DE CONCRETO PRÉ MOLDADA 17 CM - 20 T | Un | 29.62 | 1.000000 |  | 29.6200
20144 | EMENDA DE ESTACA DE CONCRETO PRÉ-MOLDADA - DIÂMETRO 20 CM - 30 T |  |  |  |  |  | UN |  | 31.71
 |  | 10061 | EMENDA DE ESTACA DE CONCRETO PRÉ MOLDADA 20 CM - 30 T | Un | 31.71 | 1.000000 |  | 31.7100
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

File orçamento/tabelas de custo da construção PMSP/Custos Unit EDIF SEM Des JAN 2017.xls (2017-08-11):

CÓDIGO | DESCRIÇÃO | UNIDADE | CUSTO UNIT R$
10000 | SERVICOS PRELIMINARES
10100 | LIMPEZA DO TERRENO | . | .
10101 | LIMPEZA MECANIZADA GERAL, INCLUSIVE REMOÇÃO DA COBERTURA VEGETAL - TRONCOS COM DIÂMETRO ATÉ 10CM - SEM TRANSPORTE | M2 | 1.01
10102 | DESTOCAMENTO, INCLUSIVE REMOÇÃO DAS RAÍZES - DIÂMETROS DE 10,01 À 30CM | UN | 33.46
10103 | DESTOCAMENTO, INCLUSIVE REMOÇÃO DAS RAÍZES - DIÂMETRO 30,01 À 50 CM | UN | 93.01
10104 | DESTOCAMENTO, INCLUSIVE REMOÇÃO DAS RAÍZES - DIÂMETROS MAIORES QUE 50 CM | UN | 110.81
10105 | CARGA MECANIZADA E REMOÇÃO DE ENTULHO, INCLUSIVE TRANSPORTE ATÉ 1KM | M3 | 5.95
10106 | CARGA MANUAL E REMOÇÃO DE ENTULHO, INCLUSIVE TRANSPORTE ATÉ 1 KM | M3 | 23.71
10107 | REMOÇÃO DE ENTULHO COM CAÇAMBA METÁLICA, INCLUSIVE CARGA MANUAL E DESCARGA EM BOTA-FORA | M3 | 79.92
10108 | LIMPEZA MANUAL GERAL INCLUSIVE REMOÇÃO DE COBERTURA VEGETAL - TRONCO ATÉ 10CM - SEM TRANSPORTE | M2 | 4.15
10109 | DESTOCAMENTO MANUAL, INCLUSIVE REMOÇÃO DE RAÍZES - DIÂMETRO 10,01 À 30 CM | UN | 49.81
10110 | TRANSPORTE DE ENTULHO POR CAMINHÃO BASCULANTE, A PARTIR DE 1KM | M3XKM | 0.94
10120 | CORTE, RECORTE E REMOÇÃO DE ÁRVORES INCLUSIVE RAIZES DIÂM. > 5 E < 15CM | UN | 149.26
10121 | CORTE, RECORTE E REMOÇÃO DE ÁRVORES INCLUSIVE RAIZES DIÂM. > 15 E < 30CM | UN | 337.41
10122 | CORTE, RECORTE E REMOÇÃO DE ÁRVORES INCLUSIVE RAIZES DIÂM. > 30 E < 60CM | UN | 421.76
10123 | CORTE, RECORTE E REMOÇÃO DE ÁRVORES INCLUSIVE RAIZES DIÂM. > 60 E < 90CM | UN | 506.12
10124 | CORTE, RECORTE E REMOÇÃO DE ÁRVORES INCLUSIVE RAIZES DIÂM. > 90CM | UN | 590.47
10200 | MOVIMENTO DE TERRA MANUAL | . | .
10201 | CORTE | M3 | 33.20
10202 | CORTE E ESPALHAMENTO DENTRO DA OBRA | M3 | 41.51
10205 | ATERRO, INCLUSIVE COMPACTAÇÃO | M3 | 24.90
10210 | CARGA MECANIZADA E REMOÇÃO DE TERRA, INCLUSIVE TRANSPORTE ATÉ 1KM | M3 | 7.30
10211 | CARGA MANUAL E REMOÇÃO DE TERRA, INCLUSIVE TRANSPORTE ATÉ 1 KM | M3 | 24.63
10300 | MOVIMENTO DE TERRA MECANIZADO | . | .
10301 | CORTE E ESPALHAMENTO DENTRO DA OBRA | M3 | 9.41
10302 | CORTE E ATERRO COMPACTADO | M3 | 10.74
10303 | CORTE E CARREGAMENTO PARA BOTA-FORA, INCLUSIVE TRANSPORTE ATÉ 1KM | M3 | 12.64
10305 | FORNECIMENTO DE TERRA, INCLUSIVE CORTE, CARGA, DESCARGA E TRANSPORTE ATÉ 1KM | M3 | 14.86
10306 | ATERRO, INCLUSIVE COMPACTAÇÃO | M3 | 4.03
10310 | TRANSPORTE DE TERRA POR CAMINHÃO BASCULANTE, A PARTIR DE 1KM | M3XKM | 1.21
10400 | DRENAGEM DO TERRENO | . | .
10401 | ESCAVAÇÃO MANUAL, PROFUNDIDADE IGUAL OU INFERIOR A 1,50M | M3 | 49.81
10402 | ESCAVAÇÃO MANUAL, PROFUNDIDADE SUPERIOR A 1,50M | M3 | 58.11
10405 | ESCORAMENTO DE VALAS, CONTINUO | M2 | 65.31
10406 | ESCORAMENTO DE VALAS, DESCONTINUO | M2 | 40.14
10410 | APILOAMENTO DO FUNDO DE VALAS, PARA SIMPLES REGULARIZAÇÃO | M2 | 4.15
10414 | LASTRO DE AGREGADO RECICLADO | M3 | 84.40
10415 | LASTRO DE BRITA | M3 | 118.03
10416 | LASTRO DE CONCRETO, 150KG CIM/M3 | M3 | 314.20
10417 | LASTRO DE CONCRETO COM AGREGADO RECICLADO, 150 KG CIM/M3 | M3 | 286.79
10420 | TUBO DE PEAD CORRUGADO E PERFURADOPARA DRENAGEM - DIÂMETRO 2,5" (EM ACORDO COM AS NORMAS DNIT 093/06, NBR 15073 E NBR 14692) | M | 17.36
10421 | TUBO DE PEAD CORRUGADO E PERFURADOPARA DRENAGEM - DIÂMETRO 3,0" (EM ACORDO COM AS NORMAS DNIT 093/06, NBR 15073 E NBR 14692) | M | 19.32
10422 | TUBO DE PEAD CORRUGADO E PERFURADOPARA DRENAGEM - DIÂMETRO 4,0" (EM ACORDO COM AS NORMAS DNIT 093/06, NBR 15073 E NBR 14692) | M | 22.23
10423 | TUBO DE PEAD CORRUGADO E PERFURADOPARA DRENAGEM - DIÂMETRO 6,0" (EM ACORDO COM AS NORMAS DNIT 093/06, NBR 15073 E NBR 14692) | M | 39.85
10426 | TUBO PVC PERFURADO PARA DRENAGEM - DIÂMETRO 4" (100MM) | M | 28.68
10427 | TUBO PVC PERFURADO PARA DRENAGEM - DIÂMETRO 6" (150MM) | M | 53.02
10430 | TUBO DE CONCRETO - DIÂMETRO DE 30CM | M | 34.84
10431 | TUBO DE CONCRETO - DIÂMETRO DE 40CM | M | 49.63
10432 | TUBO DE CONCRETO - DIÂMETRO DE 50CM | M | 69.58
10433 | TUBO DE CONCRETO - DIÂMETRO DE 60CM | M | 85.61
10435 | TUBO DE CONCRETO - DIÂMETRO DE 80CM | M | 187.57
10437 | TUBO DE CONCRETO - DIÂMETRO DE 100CM | M | 263.09
10439 | TUBO DE CONCRETO - DIÂMETRO DE 120CM | M | 415.60
10448 | CAIXA DE LIGAÇÃO OU INSPEÇÃO - ESCAVAÇÃO E APILOAMENTO | M3 | 44.83
10449 | CAIXA DE LIGAÇÃO OU INSPEÇÃO - LASTRO DE CONCRETO (FUNDO) | M3 | 336.70
10450 | CAIXA DE LIGAÇÃO OU INSPEÇÃO - ALVENARIA DE 1/2 TIJOLO, REVESTIDA | M2 | 180.79
10451 | CAIXA DE LIGAÇÃO OU INSPEÇÃO - ALVENARIA DE 1 TIJOLO, REVESTIDA | M2 | 250.62
10452 | CAIXA DE LIGAÇÃO OU INSPEÇÃO - TAMPA DE CONCRETO | M2 | 165.03
10470 | ENVOLVIMENTO DE TUBOS COM BRITA | M3 | 126.33
10471 | ENVOLVIMENTO DE TUBOS COM AREIA | M3 | 146.42
10475 | MANTA GEOTÊXTIL | M2 | 5.17
10476 | FORNECIMENTO E APLICAÇÃO DE GEOMEMBRANA DE PEAD - 1MM DE ESPESSURA | M2 | 23.20
10477 | FORNECIMENTO E APLICAÇÃO DE MANTA FORMADA PELA ASSOCIAÇÃO DE UM TECIDO TÉCNICO DE POLIESTER COM UM FILME DE POLIETILENO DE BAIXA DENSIDADE EM ACORDO COM A NBR 12824 | M2 | 17.21
10478 | FORNECIMENTO E APLICAÇÃO DE GEOCOMPOSTO FORMADO POR NÚCLEO TRIDIMENSIONAL, FLEXÍVEL DE FILAMENTO DE POLIPROPILENO, ASSOCIADO ÀS SUAS DUAS SUPERFÍCIES GEOTEXTEIS NÃO TECIDOS | M2 | 24.51
10480 | REATERRO DE VALAS, INCLUSIVE COMPACTAÇÃO | M3 | 9.97
10500 | TAPUMES | . | .
10501 | TAPUME CHAPA COMPENSADA 6MM | M2 | 47.34
10502 | TAPUME CHAPA COMPENSADA RESINADA 10MM | M2 | 51.50
10505 | TAPUME METÁLICO COM TELHA METÁLICA, SEM PINTURA, TRAPEZOIDAL 40 ESP=0,43MM, COLUNAS, BASES E PARAFUSOS | M2 | 113.11
10506 | PORTÃO METÁLICO DE OBRA - 5M, PIVOTANTE, 2 FOLHAS, PARA TAPUME | M2 | 181.86
10507 | PORTÃO DE PEDESTRES - 1,15M, PARA TAPUME | M2 | 169.19
10540 | TELA PARA PROTEÇÃO DE OBRAS, MALHA 2 MM | M2 | 20.06
20000 | FUNDACOES
20100 | FUNDAÇÃO PROFUNDA | . | .
20101 | BROCA DE CONCRETO - DIÂMETRO DE 20CM | M | 39.29
20102 | BROCA DE CONCRETO - DIÂMETRO DE 25CM | M | 59.44
20103 | BROCA DE CONCRETO - DIÂMETRO DE 30CM | M | 88.51
20105 | ESTACA DE CONCRETO MOLDADA NO LOCAL, TIPO "STRAUSS" - ATÉ 20T | M | 44.71
20106 | ESTACA DE CONCRETO MOLDADA NO LOCAL, TIPO "STRAUSS" - ATÉ 30T | M | 56.78
20107 | ESTACA DE CONCRETO MOLDADA NO LOCAL, TIPO "STRAUSS" - ATÉ 40T | M | 72.51
20108 | ESTACA DE CONCRETO MOLDADA NO LOCAL, TIPO "STRAUSS" - ATÉ 60T | M | 96.36
20120 | TUBULÃO - ESCAVAÇÃO A CÉU ABERTO, COM PÁ E PICARETA | M3 | 373.55
20134 | TUBULÃO A CÉU ABERTO FCK=20 MPA | M3 | 497.35
20138 | ESTACA DE CONCRETO PRÉ-MOLDADA COM CARGA ADMISSÍVEL PARA ESTRUTURA DE 20 T | M | 67.03
20139 | ESTACA DE CONCRETO PRÉ-MOLDADA COM CARGA ADMISSÍVEL PARA ESTRUTURA DE 30 T | M | 87.96
20140 | ESTACA DE CONCRETO PRÉ-MOLDADA COM CARGA ADMISSÍVEL PARA ESTRUTURA DE 40 T | M | 101.75
20141 | ESTACA DE CONCRETO PRÉ-MOLDADA COM CARGA ADMISSÍVEL PARA ESTRUTURA DE 60 T | M | 144.87
20142 | ESTACA DE CONCRETO PRÉ-MOLDADA COM CARGA ADMISSÍVEL PARA ESTRUTURA DE 70 T | M | 177.84
20143 | EMENDA DE ESTACA DE CONCRETO PRÉ-MOLDADA - DIÂMETRO 17 CM - 20 T | UN | 29.62
20144 | EMENDA DE ESTACA DE CONCRETO PRÉ-MOLDADA - DIÂMETRO 20 CM - 30 T | UN | 31.71
20145 | EMENDA DE ESTACA DE CONCRETO PRÉ-MOLDADA - DIÂMETRO 23 CM - 40 T | UN | 45.59
20146 | EMENDA DE ESTACA DE CONCRETO PRÉ-MOLDADA - DIÂMETRO 28 CM - 60 T | UN | 39.88
20147 | EMENDA DE ESTACA DE CONCRETO PRÉ-MOLDADA - DIÂMETRO 33 CM - 70 T | UN | 44.46
20148 | CORTE E REPARO DE CABEÇA DE ESTACA | UN | 46.58
20151 | ESTACAS ESCAVADAS MECANICAMENTE - DIÂMETRO DE 25CM | M | 26.45
20152 | ESTACAS ESCAVADAS MECANICAMENTE - DIÂMETRO DE 30CM | M | 34.01
20153 | ESTACAS ESCAVADAS MECANICAMENTE - DIÂMETRO DE 35CM | M | 43.02
20155 | ESTACAS ESCAVADAS MECANICAMENTE - DIÂMETRO DE 40CM | M | 57.08
20156 | ESTACAS ESCAVADAS MECANICAMENTE - DIÂMETRO DE 80CM | M | 192.67
20160 | ESTACA RAIZ DIÂMETRO DE 160MM PARA ATÉ 35 TF | M | 223.52
20161 | ESTACA RAIZ DIÂMETRO DE 200MM PARA ATÉ 50 TF | M | 257.04
20162 | ESTACA RAIZ DIÂMETRO DE 250MM PARA ATÉ 80 TF | M | 295.62
20163 | ESTACA RAIZ DIÂMETRO DE 310MM PARA ATÉ 100 TF | M | 353.22
20164 | EXECUÇÃO DE ESTACA RAIZ DIÂMETRO DE 160MM PARA ATÉ 35TF (EXCLUSIVE MATERIAIS) | M | 157.10
20165 | EXECUÇÃO DE ESTACA RAIZ DIÂMETRO DE 200MM PARA ATÉ 50TF (EXCLUSIVE MATERIAIS) | M | 172.64
20166 | EXECUÇÃO DE ESTACA RAIZ DIÂMETRO DE 250MM PARA ATÉ 80TF (EXCLUSIVE MATERIAIS | M | 189.21
20167 | EXECUÇÃO DE ESTACA RAIZ DIÂMETRO DE 310MM PARA ATÉ 100TF (EXCLUSIVE MATERIAIS) | M | 211.38
20170 | FORNECIMENTO E CRAVAÇÃO DE ESTACA METÁLICA - PERFIL DE AÇO LAMINADO W 250X32,7 | M | 139.40
20171 | FORNECIMENTO E CRAVAÇÃO DE ESTACA METÁLICA - PERFIL DE AÇO LAMINADO W 310X52 | M | 211.47
20172 | FORNECIMENTO E CRAVAÇÃO DE ESTACA PERFIL DE AÇO I 15" | M | 654.74
20173 | CORTE DE ESTACA METÁLICA PERFIL 10" | UN | 84.43
20174 | CORTE DE ESTACA METÁLICA PERFIL 12" | UN | 97.91
20175 | CORTE DE ESTACA METÁLICA PERFIL I 15" | UN | 110.45
20176 | EMENDA DE TOPO PARA ESTACA METÁLICA PERFIL 10" | UN | 253.81
20177 | EMENDA DE TOPO PARA ESTACA METÁLICA PERFIL 12" | UN | 290.02
20178 | EMENDA DE TOPO PARA ESTACA METÁLICA PERFIL I 15" | UN | 393.84
20180 | ESTACA ESCAVADA HÉLICE CONTÍNUA - DIÂMETRO 25CM | M | 37.21
20181 | ESTACA ESCAVADA HÉLICE CONTÍNUA - DIÂMETRO 30CM | M | 52.59
20182 | ESTACA ESCAVADA HÉLICE CONTÍNUA - DIÂMETRO 35CM | M | 65.14
20183 | ESTACA ESCAVADA HÉLICE CONTÍNUA - DIÂMETRO 40CM | M | 79.73
20184 | ESTACA ESCAVADA HÉLICE CONTÍNUA - DIÂMETRO 50CM | M | 115.67
20185 | ESTACA ESCAVADA HÉLICE CONTÍNUA - DIÂMETRO 60CM | M | 150.89
20190 | ESTACA ESCAVADA HÉLICE CONTÍNUA - DIÂMETRO 25CM - EXCLUSIVE MATERIAIS | M | 21.05
20191 | ESTACA ESCAVADA HÉLICE CONTÍNUA - DIÂMETRO 30CM - EXCLUSIVE MATERIAIS | M | 29.57
20192 | ESTACA ESCAVADA HÉLICE CONTÍNUA - DIÂMETRO 35CM - EXCLUSIVE MATERIAIS | M | 33.83
20193 | ESTACA ESCAVADA HÉLICE CONTÍNUA - DIÂMETRO 40CM - EXCLUSIVE MATERIAIS | M | 35.82
20194 | ESTACA ESCAVADA HÉLICE CONTÍNUA - DIÂMETRO 50CM - EXCLUSIVE MATERIAIS | M | 47.32
20195 | ESTACA ESCAVADA HÉLICE CONTÍNUA - DIÂMETRO 60CM - EXCLUSIVE MATERIAIS | M | 52.24
20196 | MATERIAIS PARA ESTACA (AS QUANTIDADES SERÃO LEVANTADAS NO PROJETO) - FORNECIMENTO DE CIMENTO COMUM | KG | 0.42
20197 | MATERIAIS PARA ESTACA (AS QUANTIDADES SERÃO LEVANTADAS NO PROJETO) - FORNECIMENTO DE AREIA | M3 | 76.21
20198 | MATERIAIS PARA ESTACA (AS QUANTIDADES SERÃO LEVANTADAS NO PROJETO) - FORNECIMENTO DE ÁGUA | M3 | 21.80
20200 | VALAS | . | .
20201 | ESCAVAÇÃO MANUAL COM PROFUNDIDADE IGUAL OU INFERIOR A 1,50M | M3 | 49.81
20202 | ESCAVAÇÃO MANUAL COM PROFUNDIDADE SUPERIOR A 1,50M | M3 | 58.11
20205 | ESCORAMENTO DE VALAS - CONTINUO | M2 | 65.33
20206 | ESCORAMENTO DE VALAS - DESCONTINUO | M2 | 40.14
20210 | APILOAMENTO DO FUNDO DE VALAS, PARA SIMPLES REGULARIZAÇÃO | M2 | 4.15
20211 | APILOAMENTO DO FUNDO DE VALAS, COM SOQUETE VIBRATÓRIO | M2 | 2.26
20215 | LASTRO DE BRITA | M3 | 118.03
20216 | LASTRO DE CONCRETO - 150KG CIM/M3 | M3 | 313.87
20217 | LASTRO DE CONCRETO COM AGREGADO RECICLADO - 150 KG CIM/M3 | M3 | 286.79
20300 | FUNDAÇÃO - FORMA | . | .
20301 | FORMA COMUM DE TÁBUAS DE PINUS | M2 | 53.05
20304 | FORMA COMUM DE TÁBUAS DE PINUS - NÃO RECUPERÁVEL | M2 | 60.31
20400 | FUNDAÇÃO - ARMADURA | . | .
20404 | ARMADURA EM AÇO CA-50 | KG | 6.46
20407 | ARMADURA EM AÇO CA-60 | KG | 6.94
20409 | ARMADURA EM AÇO CA-60 - TELA | KG | 5.88
20500 | FUNDAÇÃO - CONCRETO | . | .
20505 | CONCRETO FCK=15,0MPA - VIRADO NA OBRA | M3 | 370.29
20506 | CONCRETO FCK=20,0MPA - VIRADO NA OBRA | M3 | 382.66
20508 | CONCRETO FCK=15,0MPA - USINADO | M3 | 305.51
20509 | CONCRETO FCK=20,0MPA - USINADO | M3 | 318.73
20510 | CONCRETO FCK=25MPA - USINADO | M3 | 329.95
20511 | CONCRETO FCK=30MPA - USINADO | M3 | 339.52
20600 | EMBASAMENTO | . | .
20601 | ALVENARIA DE EMBASAMENTO - TIJOLOS MACIÇOS COMUNS | M3 | 602.63
20605 | IMPERMEABILIZAÇÃO DO RESPALDO DA FUNDAÇÃO - ARGAMASSA IMPERMEÁVEL | M2 | 64.00
20610 | REATERRO DE VALAS, INCLUSIVE APILOAMENTO | M3 | 24.90
25000 | DEMOLIÇÕES | . | .
25001 | DEMOLIÇÃO DE ALVENARIA DE EMBASAMENTO - TIJOLOS MACIÇOS COMUNS | M3 | 55.90
25003 | DEMOLIÇÃO MANUAL DE CONCRETO SIMPLES | M3 | 182.63
25004 | DEMOLIÇÃO MANUAL DE CONCRETO ARMADO | M3 | 332.05
25005 | DEMOLIÇÃO MECANIZADA DE CONCRETO SIMPLES | M3 | 117.62
25006 | DEMOLIÇÃO MECANIZADA DE CONCRETO ARMADO | M3 | 235.25
29000 | OUTROS SERVIÇOS | . | .
29040 | BUZINOTE PVC - 2", C=0,30 M | UN | 9.53
30000 | ESTRUTURA
30100 | ESTRUTURA DE CONCRETO ARMADO - FORMAS | . | .
30101 | FORMA COMUM DE TÁBUAS DE PINUS - PLANA | M2 | 57.97
30104 | FORMA COMUM DE TÁBUAS DE PINUS - NÃO RECUPERÁVEL | M2 | 60.31
30111 | FORMA ESPECIAL DE CHAPAS RESINADAS (10MM) - CURVA | M2 | 85.36
30113 | FORMA ESPECIAL DE CHAPAS PLASTIFICADAS (10MM) - CURVA | M2 | 88.39
30114 | FORMA ESPECIAL DE CHAPAS RESINADAS (10MM) - PLANA | M2 | 64.31
30115 | FORMA ESPECIAL DE CHAPAS RESINADAS (12MM) - PLANA | M2 | 65.38
30116 | FORMA ESPECIAL DE CHAPAS PLASTIFICADAS (10MM) - PLANA | M2 | 66.73
30117 | FORMA ESPECIAL DE CHAPAS PLASTIFICADAS (12MM) - PLANA | M2 | 67.62
30120 | FORMA DE TUBO DE PAPELÃO, DIÂMETRO 350MM | M | 106.90
30130 | CIMBRAMENTO PARA ALTURAS ENTRE 3,01M E 7,00M | M3 | 24.90
30200 | ESTRUTURA DE CONCRETO ARMADO - ARMADURA | . | .
30204 | ARMADURA EM AÇO CA-50 | KG | 6.46
30207 | ARMADURA EM AÇO CA-60 | KG | 6.94
30209 | ARMADURA EM AÇO CA-60 - TELA | KG | 5.88
30300 | ESTRUTURA DE CONCRETO ARMADO - CONCRETO | . | .
30305 | CONCRETO FCK = 15,0MPA - VIRADO NA OBRA | M3 | 370.48
30307 | CONCRETO FCK = 20,0MPA - VIRADO NA OBRA | M3 | 382.66
30308 | CONCRETO FCK = 25,0MPA - VIRADO NA OBRA | M3 | 395.72
30309 | CONCRETO FCK = 15,0MPA - USINADO | M3 | 305.51
30315 | CONCRETO FCK = 20,0MPA - USINADO | M3 | 318.73
30316 | CONCRETO FCK = 20,0MPA - USINADO E BOMBEÁVEL | M3 | 300.36
30317 | CONCRETO FCK = 25,0MPA - USINADO | M3 | 329.95
30318 | CONCRETO FCK = 25,0MPA - USINADO E BOMBEÁVEL | M3 | 310.11
30319 | CONCRETO USINADO, BOMBEÁVEL FCK = 20MPA COM PEDRA 1 | M3 | 307.66
30320 | CONCRETO FCK = 30,0MPA - USINADO | M3 | 339.52
30321 | CONCRETO FCK = 30,0MPA - USINADO E BOMBEÁVEL | M3 | 315.08
30322 | CONCRETO FCK = 35,0MPA - USINADO | M3 | 359.74
30323 | CONCRETO FCK = 35,0MPA - USINADO E BOMBEÁVEL | M3 | 336.31
30324 | CONCRETO FCK = 40,0MPA - USINADO | M3 | 371.23
30325 | CONCRETO FCK = 40,0MPA - USINADO E BOMBEÁVEL | M3 | 356.30
30330 | BOMBEAMENTO DE CONCRETO | M3 | 30.82
30400 | ESTRUTURA DE CONCRETO - LAJE MISTA | . | .
30419 | LAJE MISTA TRELIÇADA H-8CM COM CAPEAMENTO 4CM (12CM) | M2 | 87.25
30420 | LAJE MISTA TRELIÇADA H-10CM COM CAPEAMENTO 4CM (14CM) | M2 | 99.26
30421 | LAJE MISTA TRELIÇADA H-12CM COM CAPEAMENTO 4CM (16CM) | M2 | 104.67
30422 | LAJE MISTA TRELIÇADA H-15CM COM CAPEAMENTO 4CM (19CM) | M2 | 112.83
30423 | LAJE MISTA TRELIÇADA H-20CM COM CAPEAMENTO 4CM (24CM) | M2 | 130.27
30424 | LAJE MISTA TRELIÇADA H-25CM COM CAPEAMENTO 5CM (30CM) | M2 | 161.64
34000 | ESTRUTURA DE CONCRETO - RECUPERAÇÃO E TRATAMENTO | . | .
34002 | APICOAMENTO DE SUPERFÍCIE DE CONCRETO | M2 | 83.01
34005 | LIMPEZA DE SUPERFÍCIES COM HIDROJATEAMENTO | M2 | 5.00
34010 | LIMPEZA E REMOÇÃO DE SUPERFÍCIE DETERIORADA COM JATEAMENTO | M2 | 68.32
34015 | LIMPEZA DE JUNTA DE DILATAÇÃO COM REMOÇÃO DO EXCESSO DE CONCRETO - ATÉ 3CM | M | 22.54
34018 | LIMPEZA DE CONCRETO E ARMADURA COM ESCOVA DE AÇO | M2 | 10.80
34022 | TRATAMENTO DE ARMADURA COM APLICAÇÃO DE PRODUTO INIBIDOR OXIDANTE | M | 4.50
34024 | LIXAMENTO MECÂNICO EM SUPERFÍCIES DE CONCRETO | M2 | 6.44
34025 | PREPARO E APLICAÇÃO DE ESTUQUE | M2 | 13.64
34026 | LIXAMENTO MANUAL DE SUPERFÍCIES DE CONCRETO | M2 | 5.05
34050 | POLIMENTO DE CONCRETO | M2 | 4.91
34051 | POLIMENTO DE CONCRETO NOVO | M2 | 4.91
34060 | PREPARAÇÃO DE PONTE DE ADERÊNCIA COM ADESIVO A BASE DE EPÓXI | M2 | 110.80
34070 | ANCORAGEM DE BARRAS DE AÇO COM ADESIVO A BASE DE EPÓXI | UN | 9.15
35000 | DEMOLIÇÕES | . | .
35001 | DEMOLIÇÃO MECANIZADA DE CONCRETO SIMPLES | M3 | 117.62
35002 | DEMOLIÇÃO MECANIZADA DE CONCRETO ARMADO | M3 | 235.25
35003 | DEMOLIÇÃO MANUAL DE CONCRETO SIMPLES | M3 | 182.63
35004 | DEMOLIÇÃO MANUAL DE CONCRETO ARMADO | M3 | 332.05
35005 | DEMOLIÇÃO DE LAJES MISTAS COM ESPESSURA FINAL IGUAL OU INFERIOR A 16CM | M2 | 29.05
35006 | DEMOLIÇÃO DE LAJES MISTAS COM ESPESSURA FINAL SUPERIOR A 16 CM, ATÉ 30CM | M2 | 41.51
36000 | ESTRUTURA METÁLICA VERTICAL | . | .
36001 | FORNECIMENTO E MONTAGEM DE ESTRUTURA METÁLICA VERTICAL - NÃO PATINÁVEL | KG | 16.33
36002 | FORNECIMENTO E MONTAGEM DE ESTRUTURA METÁLICA VERTICAL - PATINÁVEL | KG | 18.97
40000 | VEDOS
40100 | ALVENARIA DE TIJOLOS E BLOCOS | . | .
40101 | TIJOLOS MACIÇOS COMUNS - ESPELHO | M2 | 49.01
40102 | TIJOLOS MACIÇOS COMUNS - 1/2 TIJOLO | M2 | 90.85
40104 | TIJOLOS MACIÇOS COMUNS - 1 1/2 TIJOLO | M2 | 208.60
40111 | TIJOLOS MACIÇOS COMUNS - APARENTE, 1/2 TIJOLO | M2 | 90.85
40112 | TIJOLOS MACIÇOS COMUNS - APARENTE, 1 TIJOLO | M2 | 154.89
40115 | TIJOLOS CERÂMICOS FURADOS - 1/2 TIJOLO | M2 | 56.61
40116 | TIJOLOS CERÂMICOS FURADOS - 1 TIJOLO | M2 | 98.98
40120 | TIJOLOS LAMINADOS - ESPELHO | M2 | 131.01
40121 | TIJOLOS LAMINADOS - 1/2 TIJOLO | M2 | 208.83
40122 | TIJOLOS LAMINADOS - 1 TIJOLO | M2 | 363.63
40125 | TIJOLOS DE VIDRO - CANELADO, 19X19CM | M2 | 458.66
40126 | TIJOLOS DE VIDRO - TIJOLINHO, 19X19CM | M2 | 557.38
40127 | TIJOLOS DE VIDRO - VENTILAÇÃO TIPO VENEZIANA | M2 | 681.38
40131 | BLOCOS VAZADOS DE CONCRETO ESTRUTURAL - 14CM - 8MPA | M2 | 68.83
40132 | BLOCOS VAZADOS DE CONCRETO ESTRUTURAL - 14CM - 10MPA | M2 | 71.19
40133 | BLOCOS VAZADOS DE CONCRETO ESTRUTURAL - 14CM - 12MPA | M2 | 72.24
40134 | BLOCOS VAZADOS DE CONCRETO ESTRUTURAL - 14CM - 14MPA | M2 | 75.25
40135 | BLOCOS VAZADOS DE CONCRETO ESTRUTURAL - 19CM - 8MPA | M2 | 82.22
40136 | BLOCOS VAZADOS DE CONCRETO ESTRURURAL - 19CM - 10MPA | M2 | 83.66
40137 | BLOCOS VAZADOS DE CONCRETO ESTRUTURAL - 19CM - 12MPA | M2 | 86.41
40138 | BLOCOS VAZADOS DE CONCRETO ESTRUTURAL - 19CM - 14MPA | M2 | 89.69
40140 | BLOCOS VAZADOS DE CONCRETO - 09CM | M2 | 47.13
40141 | BLOCOS VAZADOS DE CONCRETO - 14CM | M2 | 53.94
40142 | BLOCOS VAZADOS DE CONCRETO - 19CM | M2 | 63.87
40144 | BLOCO SÍLICO CALCÁRIO - 14CM | M2 | 59.59
40145 | BLOCO SÍLICO CALCÁRIO - 19CM | M2 | 69.23
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

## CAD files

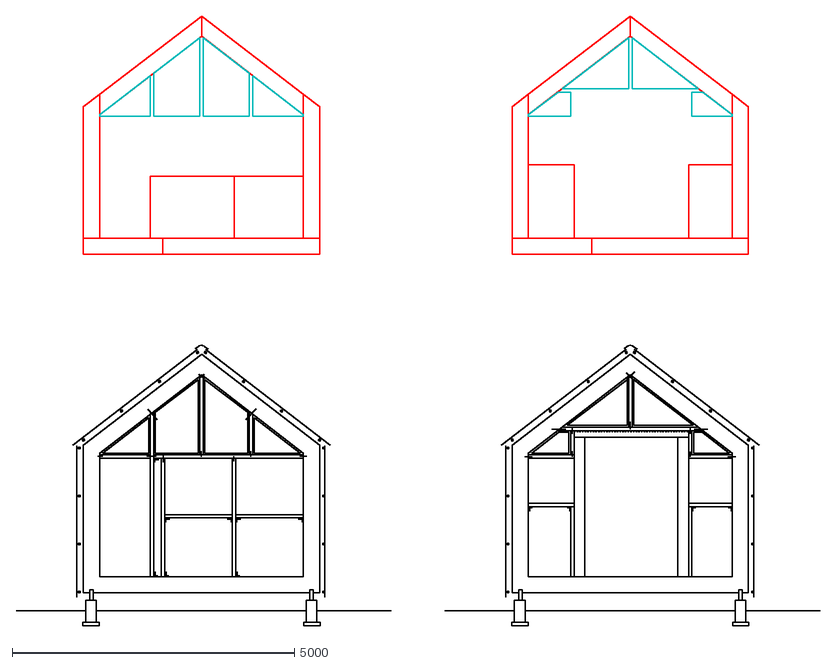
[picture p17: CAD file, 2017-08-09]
estudos/caixilhos frontais.dxf
14254.7 x 10812.7

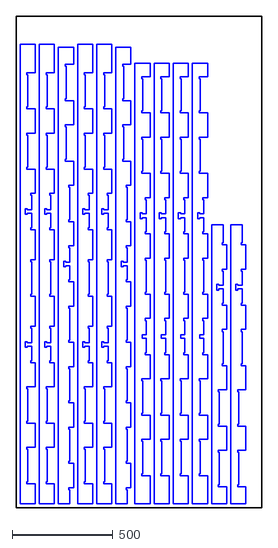
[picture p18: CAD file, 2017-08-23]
folhas de corte/plotsheet 4 - acabamentos de bordas (1x).dxf
1220.0 x 2440.0

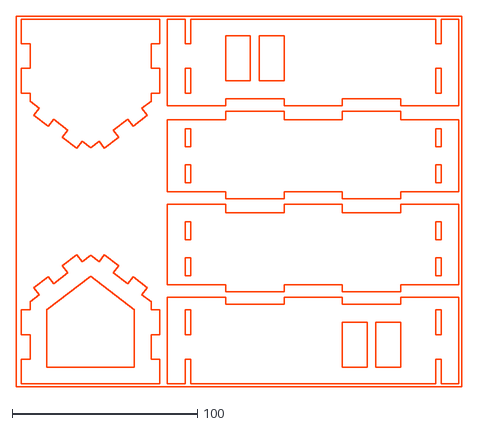
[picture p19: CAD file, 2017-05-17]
maquete 10.5x5x5cm/maquete v2.dxf
240.6 x 200.1

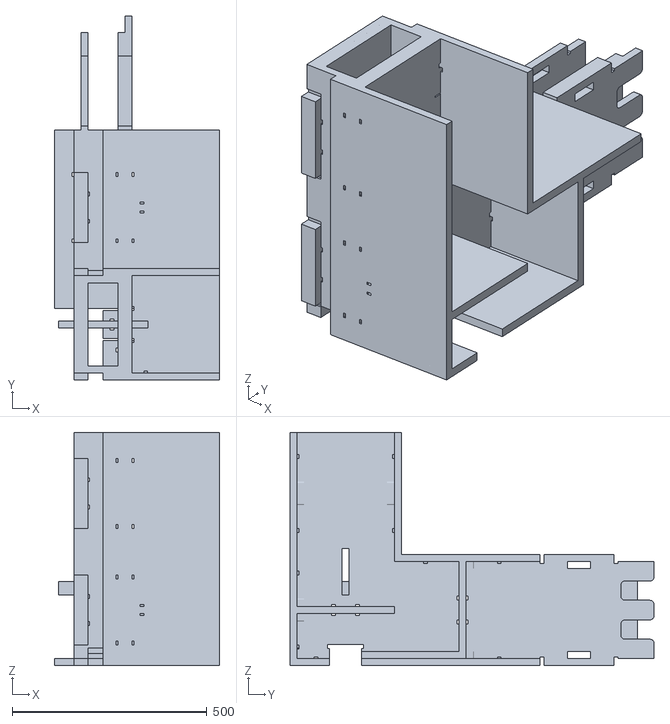
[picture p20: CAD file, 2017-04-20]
teste de encaixe/test part.stl
425.0 x 935.7 x 600.0

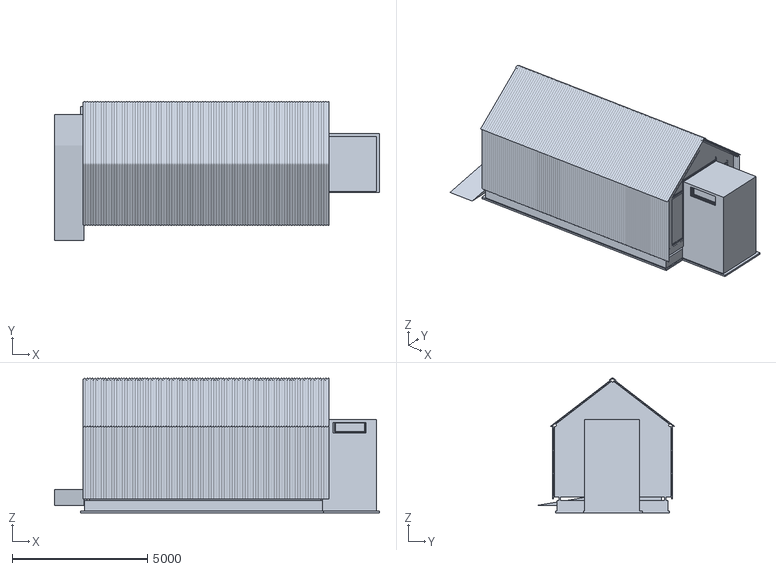
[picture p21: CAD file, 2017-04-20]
wikilab.stl
12004.3 x 5131.9 x 4978.7

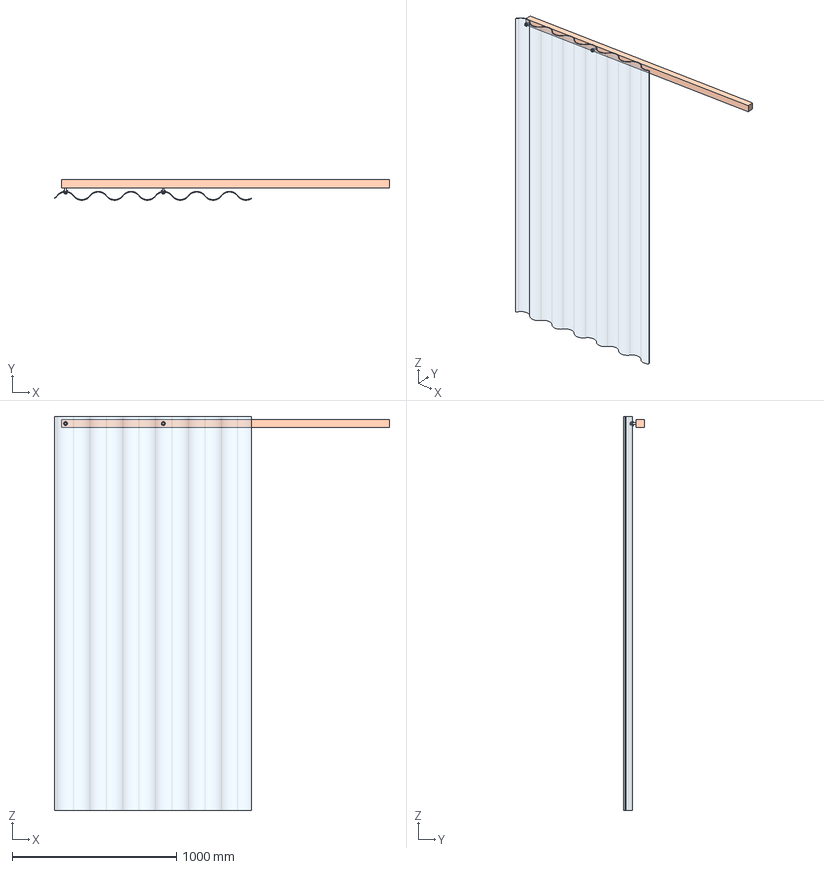
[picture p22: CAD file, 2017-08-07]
estudos/telhas.FCStd
2041.9 x 125.9 x 2400.0 mm
Panel
Structure
M10x45-Screw
M12-Washer
M12-Washer001
M10x45-Screw006
M12-Washer013
M12-Washer014

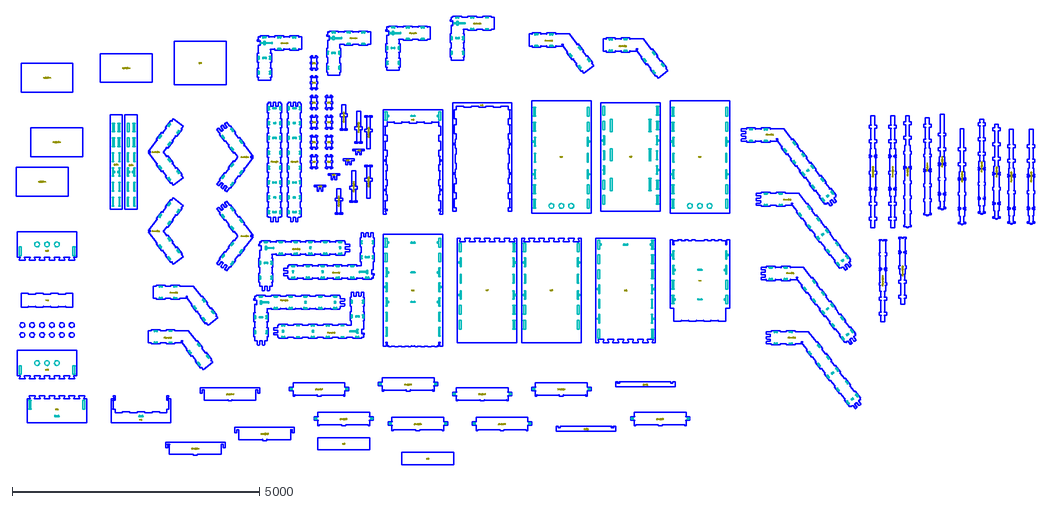
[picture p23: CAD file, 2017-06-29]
folhas de corte/plotsheet 3 - elemento vazado (4x).dxf
20600.0 x 9071.5

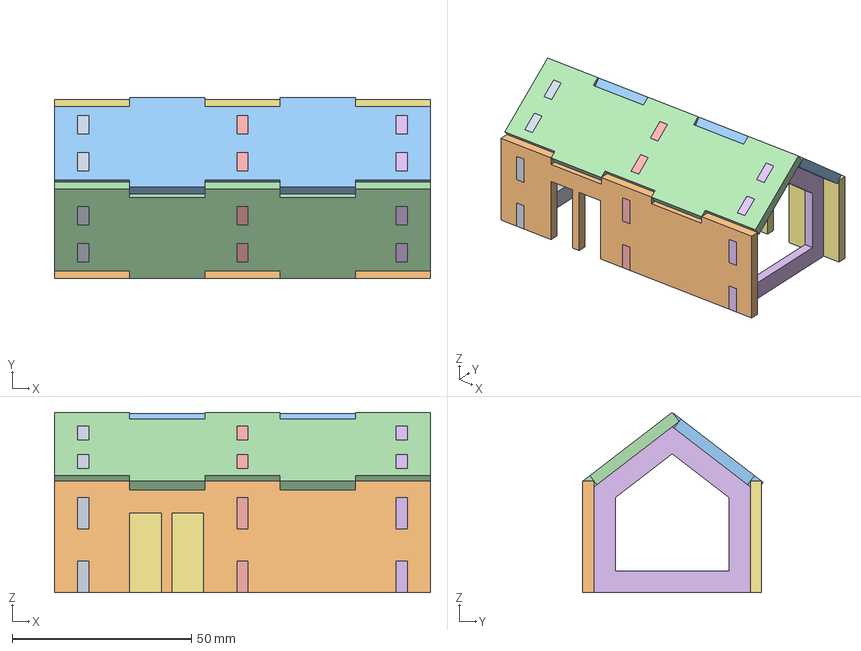
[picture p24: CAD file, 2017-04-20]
maquete 10.5x5x5cm/maquete.FCStd
105.0 x 50.4 x 50.4 mm
Panel
Panel001
Panel002
Panel003
Panel004
Panel005
Panel006

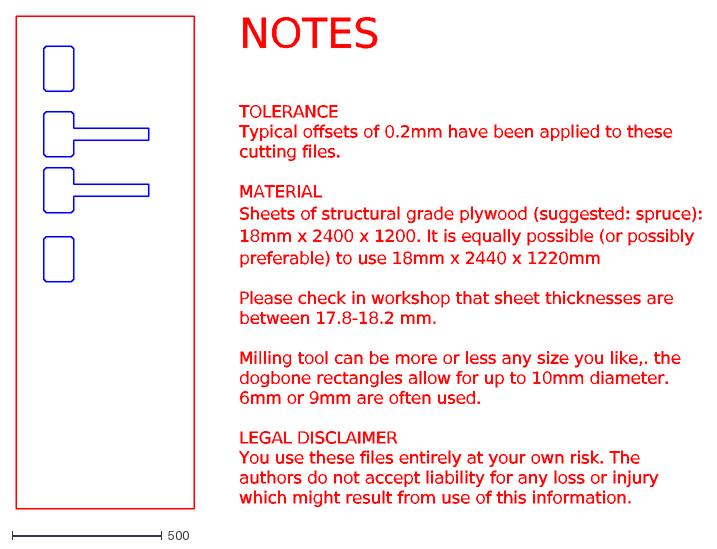
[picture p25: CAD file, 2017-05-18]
estudos/mallet.dxf
NOTES
TOLERANCE
Typical offsets of 0.2mm have been applied to these
cutting files.
MATERIAL
Sheets of structural grade plywood (suggested: spruce):
18mm x 2400 x 1200. It is equally possible (or possibly
preferable) to use 18mm x 2440 x 1220mm
Please check in workshop that sheet thicknesses are
between 17.8-18.2 mm.
Milling tool can be more or less any size you like,. the
dogbone rectangles allow for up to 10mm diameter.
6mm or 9mm are often used.
LEGAL DISCLAIMER
You use these files entirely at your own risk. The
authors do not accept liability for any loss or injury
which might result from use of this information.

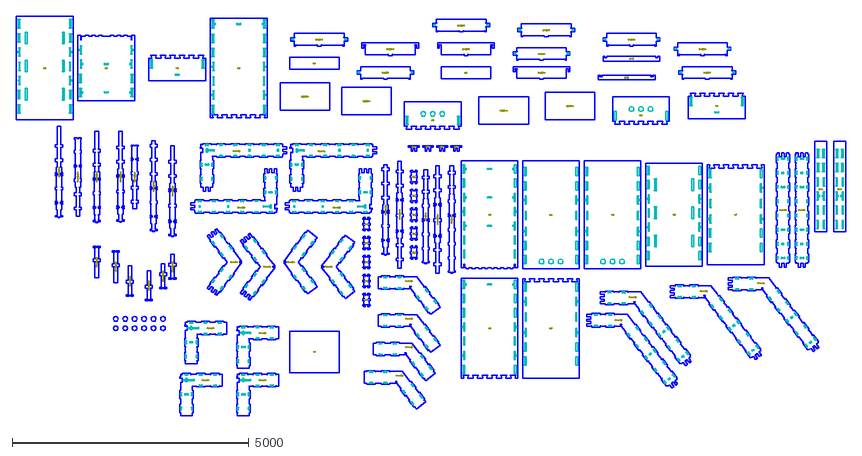
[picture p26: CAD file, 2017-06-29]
folhas de corte/plotsheet 2 - elemento basico (3x).dxf
17525.0 x 8439.8

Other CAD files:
aprovação UFABC/discussão infraestrutura/Proposta Wikilab para infraestrutura.dxf
elétrico/anteprojeto/Elétrica - Projeto Básico - proposta.dwg
elétrico/final/1718-EL-DE-01-R01.dwg
exemplos & referências/estrutura similar.dwg
elétrico/anteprojeto/Elétrica - Projeto Básico.dwg
elétrico/final/1718-EL-DE-01-R00.dwg
modulo.fcstd
teste de encaixe/test.FCStd
estudos/base.obj
estudos/mobiliário.blend
estudos/wren.obj
folhas de corte/plotsheet 1 - elemento final (1x).dxf
folhas de corte/teste cut sheet.dxf
maquete 10.5x5x5cm/maquete.dxf
maquete 10.5x5x5cm/maquete.stl
teste de encaixe/test part.dxf
wikilab.blend

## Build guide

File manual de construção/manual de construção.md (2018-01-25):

# WikiLab: Manual de montagem



Este manual de montagem segue o [manual original da MicroHouse](https://github.com/wikihouseproject/Microhouse/blob/master/MicroHouse_AssemblyManual_v1_sm.pdf) com acréscimo das partes que não são feitas com tecnologia WikiHouse, e algumas particularidades próprias ao projeto WikiLab.

**Atenção**

Este manual é uma tentativa de perimitir que um projeto de construção esteja entendido e possa ser construido por pessoas que não tem experiência prévia de construção. No entanto, certas partes, como a ferragem das lajes ou a instalação elétrica, necessitam cálculos especiais, e a construção pode ser perigosa (risco de acidentes). É muito importante nunca começar uma construção como esta sem o conselho e a ajuda de profissionais ou pessoas com boa experiência da construção.

A construção descrita abaixo é baseada no projeto do WikiLab que se encontra disponível para baixar, copiar e modificar [na plataforma Github](https://github.com/uncreatednet/wikilab-ufabc). as dimensões e especificações indicadas abaixo seguem esse projeto, e podem variar caso esse projeto seja adaptado ou modificado.

Um relatório fotográfico completo da construção está também [disponível](https://github.com/uncreatednet/wikilab-ufabc/tree/master/fotos) na mesma plataforma.

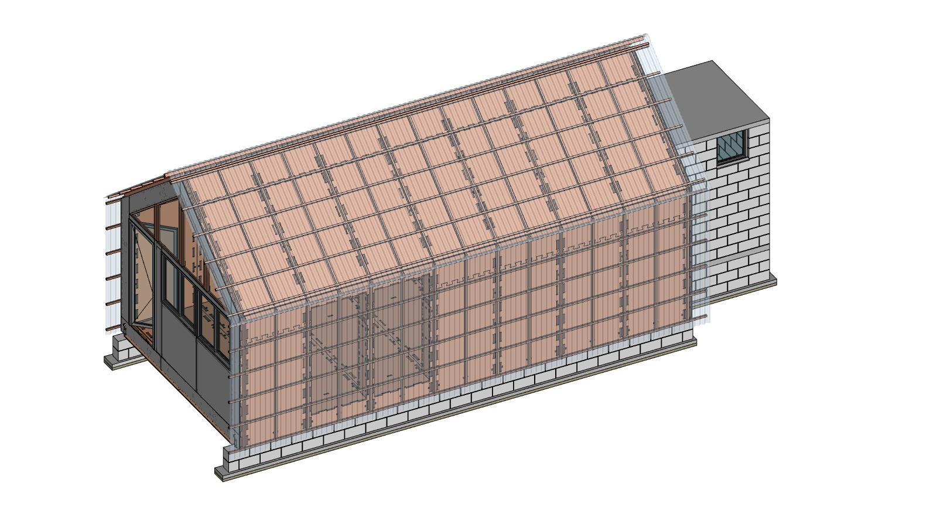
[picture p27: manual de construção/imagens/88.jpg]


## 1. Alvenaria

Observação: Esta parte é prevista para ser realizada por empreiteira, pedreiro ou outra pessoa que tenha experiência na construção.

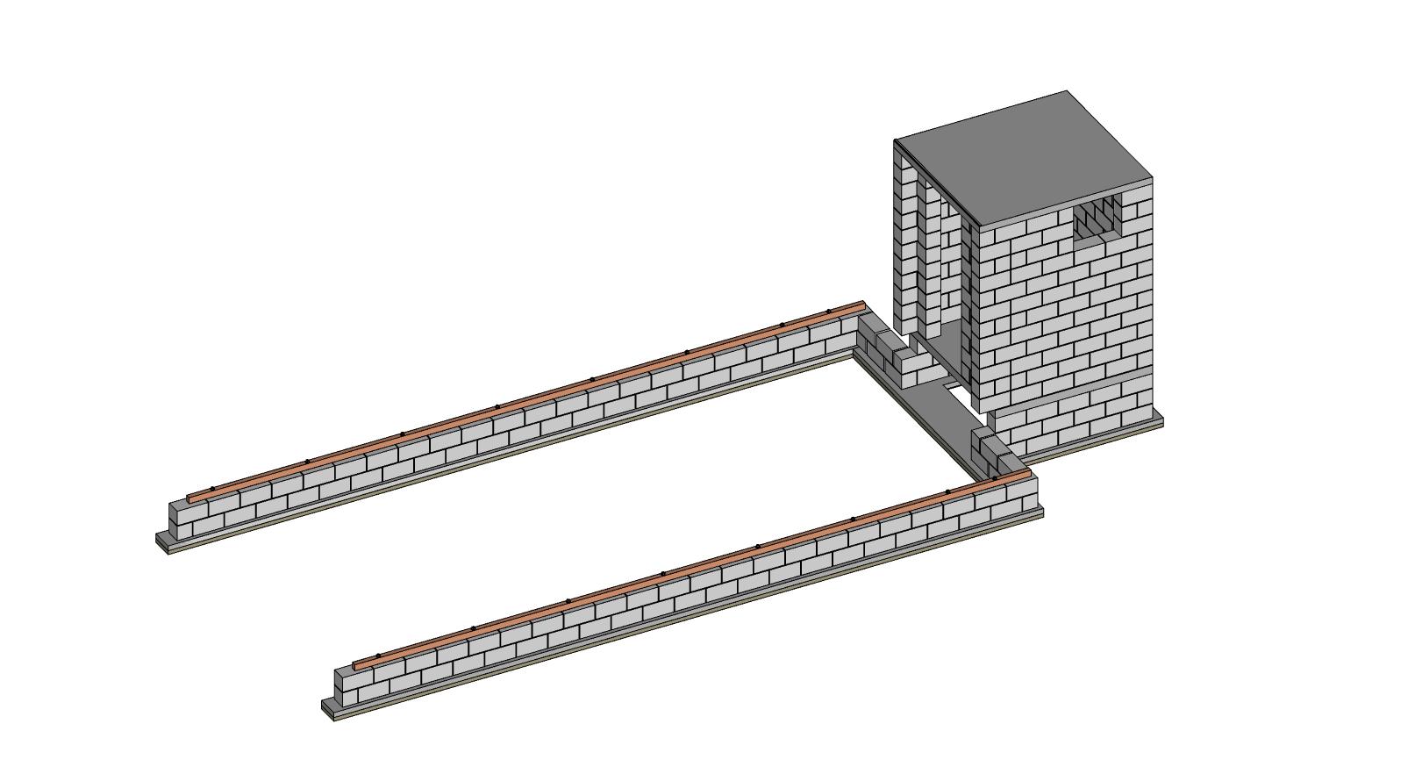
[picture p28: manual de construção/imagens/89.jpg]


### 1.1. Preparo do terreno e escavação

O perímetro de construção de 11.04m x 4.20m deve ser marcado no terreno com 4 marcadores nos cantos. A medida diagonal de 11.81m permite verificar que os cantos estejam com ângulos retos.

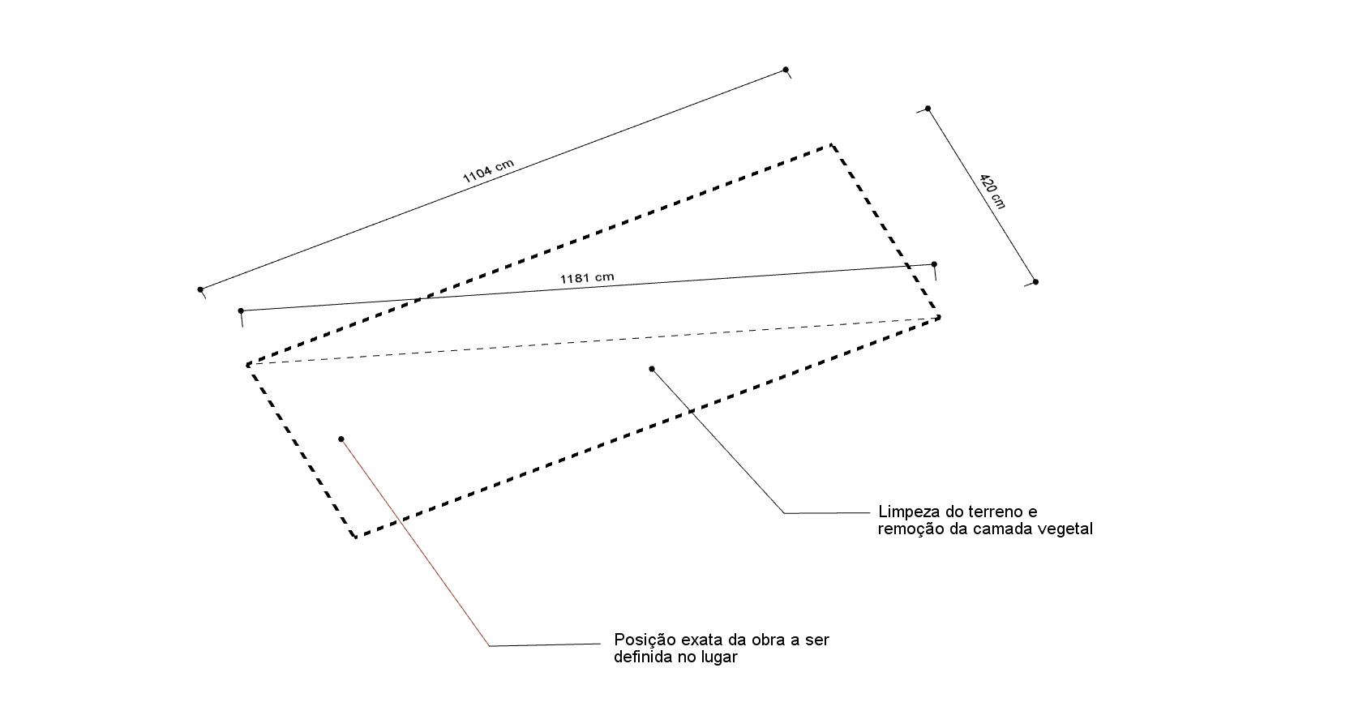
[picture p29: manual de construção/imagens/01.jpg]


Escavação de uma vala para fundação corrida. Profundidade = 30cm, largura = 30cm. Área total da escavação = 8.68 m², volume de terra a ser retirado = 8.68 x 0.30 = 2.6 m³.

O fundo da vala deve ser coberto de uma camada de 5cm de areia seca, e em seguida apiloado e compactado manualmente. É importante fazer a escavação em dias secos, para que a base sobre qual a mureta de alvenaria será construída fique rigorosamente seca. No caso contrário, podem ocorrer deformações da mureta no futuro.

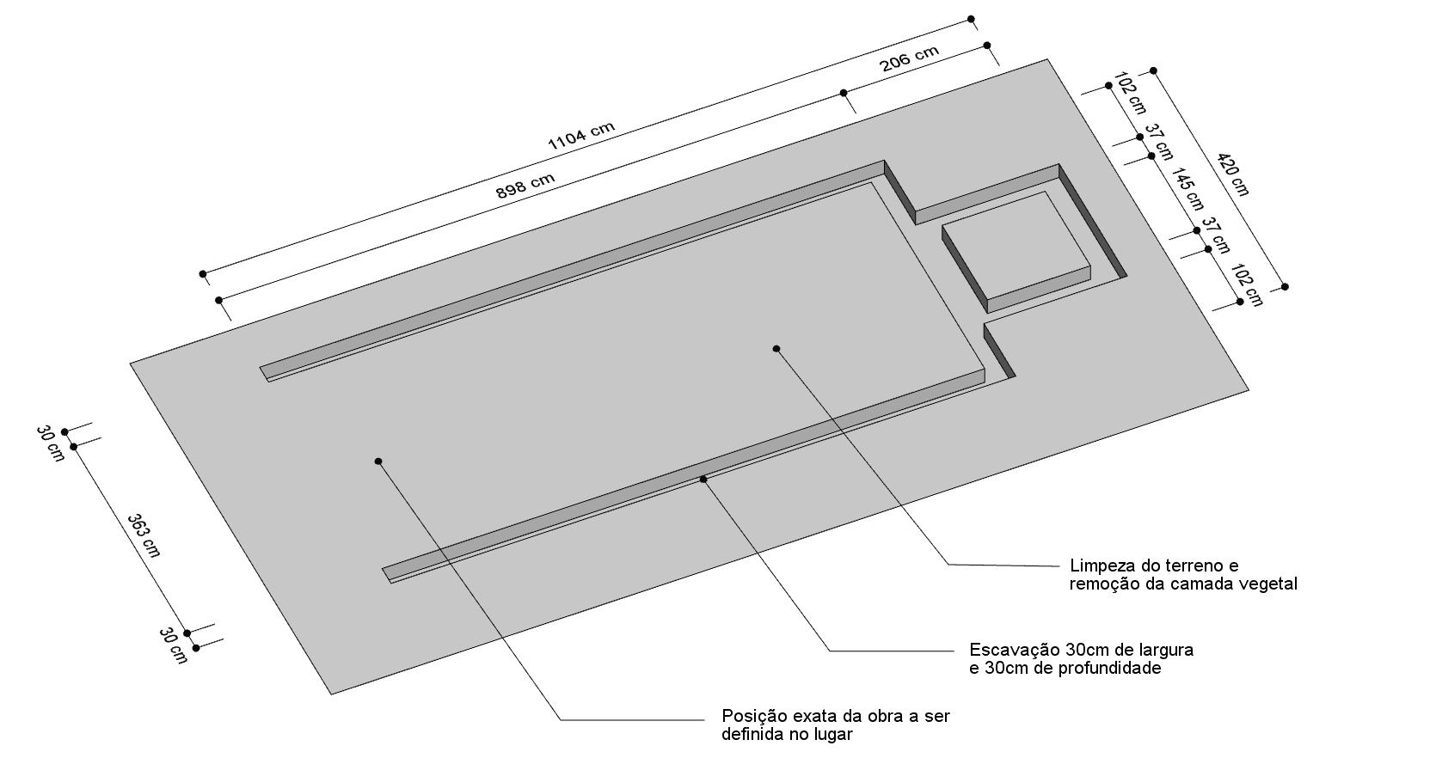
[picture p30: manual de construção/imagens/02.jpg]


Após a colocação da camada de areia, o fundo da vala deve estar a 25 cm de profundidade.

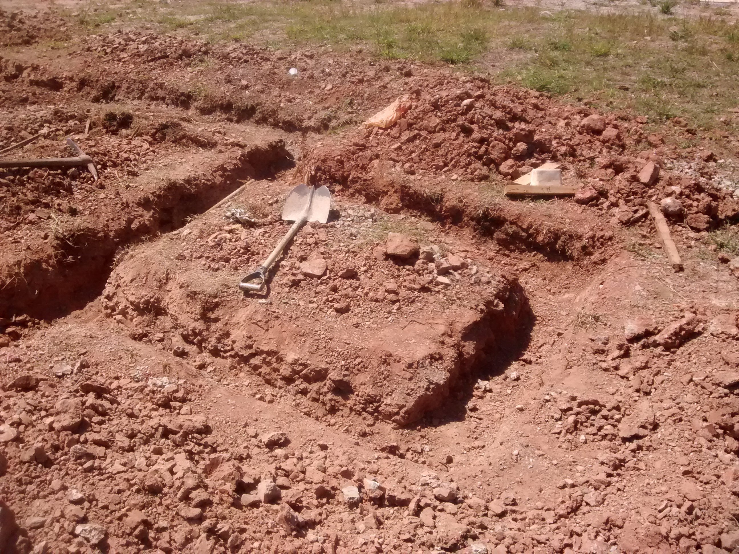
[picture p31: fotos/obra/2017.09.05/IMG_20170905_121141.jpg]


### 1.2. Fundação em alvenaria

Na base da vala é colocada uma camada de 5cm de concreto magro, que forma a base da fundação. Sobre esta camada é constuida uma mureta (alicerce) de duas fileiras de blocos de concreto de 19 x 19 x 39cm, aparelhados e grauteados com argamassa traço 1:4 (uma parte de cimento para quatro partes de areia)

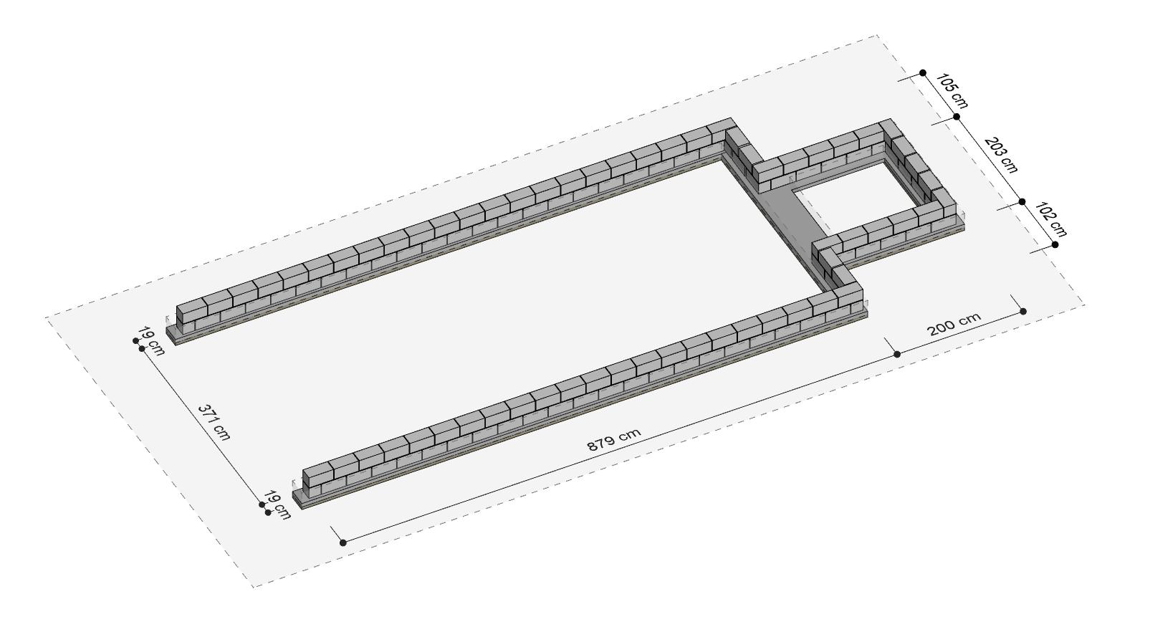
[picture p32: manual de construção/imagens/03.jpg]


A segunda fileira de blocos deve ter seus furos preenchidos com argamassa. Para tanto, se enche primeiro a primeira fileira com terra oriunda da escavação. No final, se obtem uma mureta com a face superior bem lisa e horizontal. Sempre usar um nível para verificar a horizontalidade.

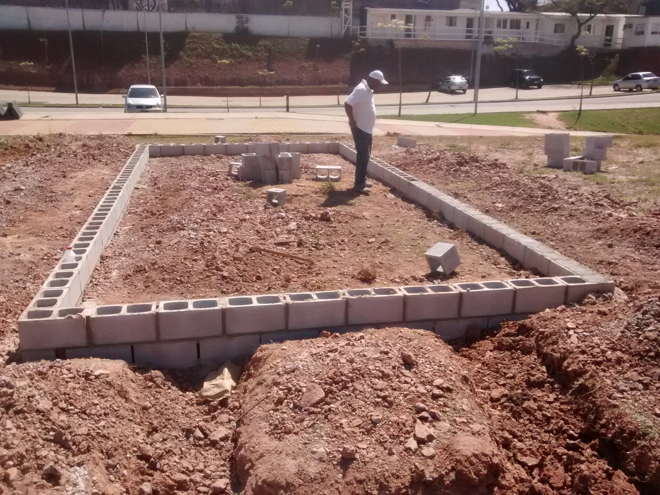
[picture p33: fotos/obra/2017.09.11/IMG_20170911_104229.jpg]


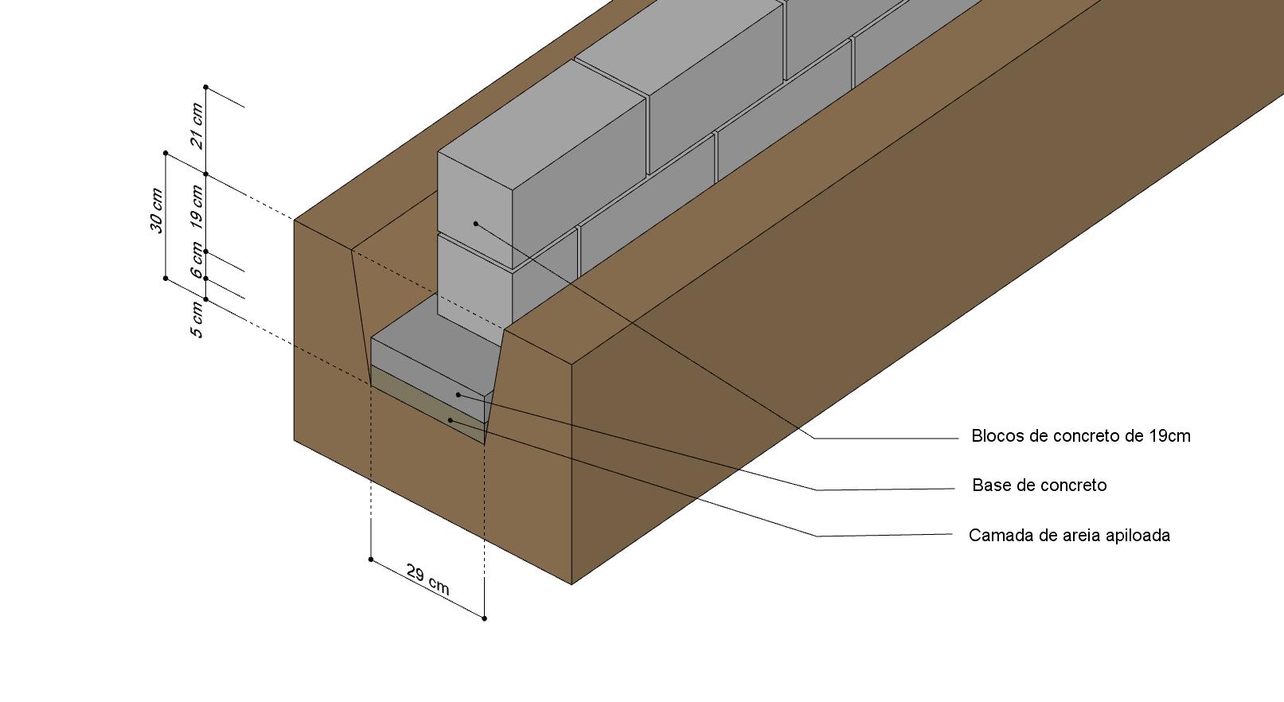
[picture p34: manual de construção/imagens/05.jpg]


A cada 3 blocos, é colocada uma barra de aço filetada em posição vertical. Os dois blocos abaixo de cada barra devem ser grauteados. A barra deve ter no mínimo 12 cm livres acima da alvenaria (mais se se planeja usar vigas-guia maiores que 8cm). A distância entre as duas fileiras de barras deve ser **exatamente 390cm**

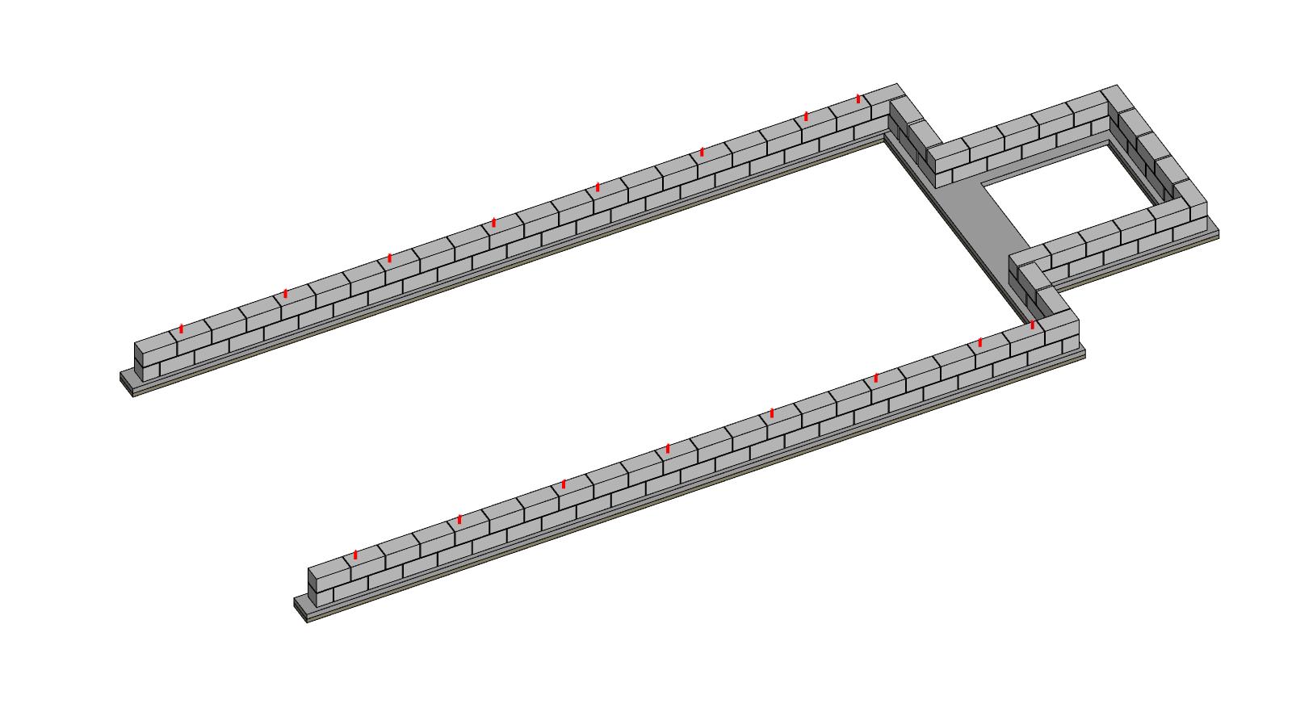
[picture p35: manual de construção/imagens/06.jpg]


**Atenção**: É importante colocar os ferros nas posições acima, para evitar que batam com as "costelas" de madeira que serão instaladas depois:

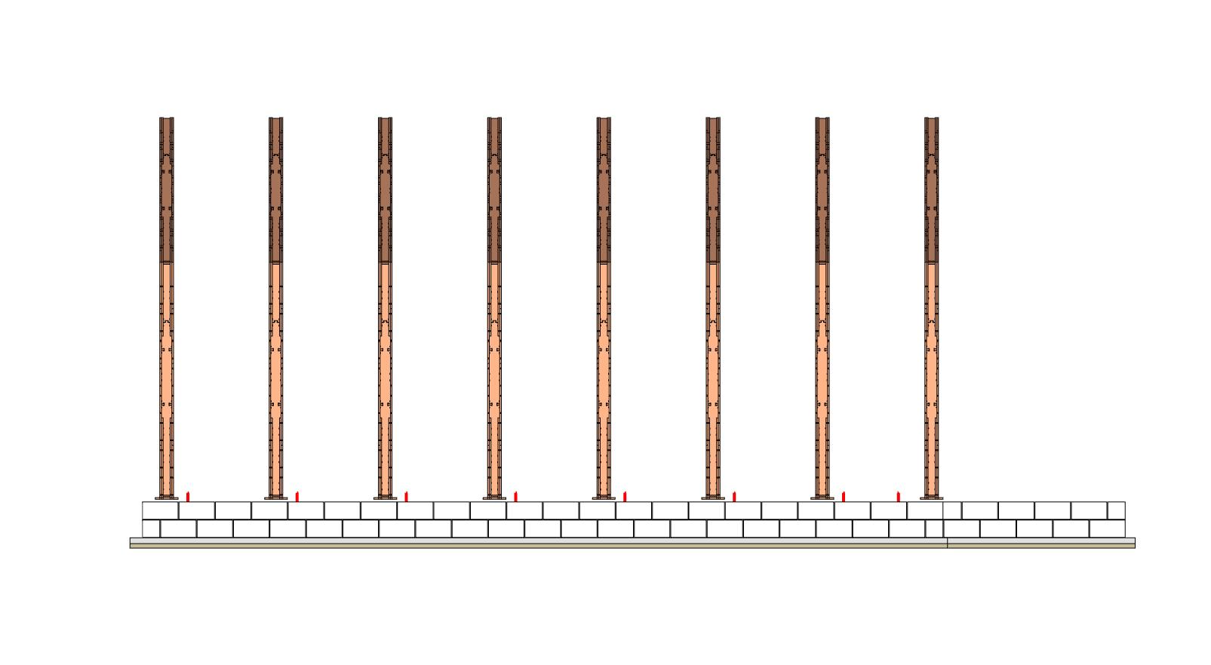
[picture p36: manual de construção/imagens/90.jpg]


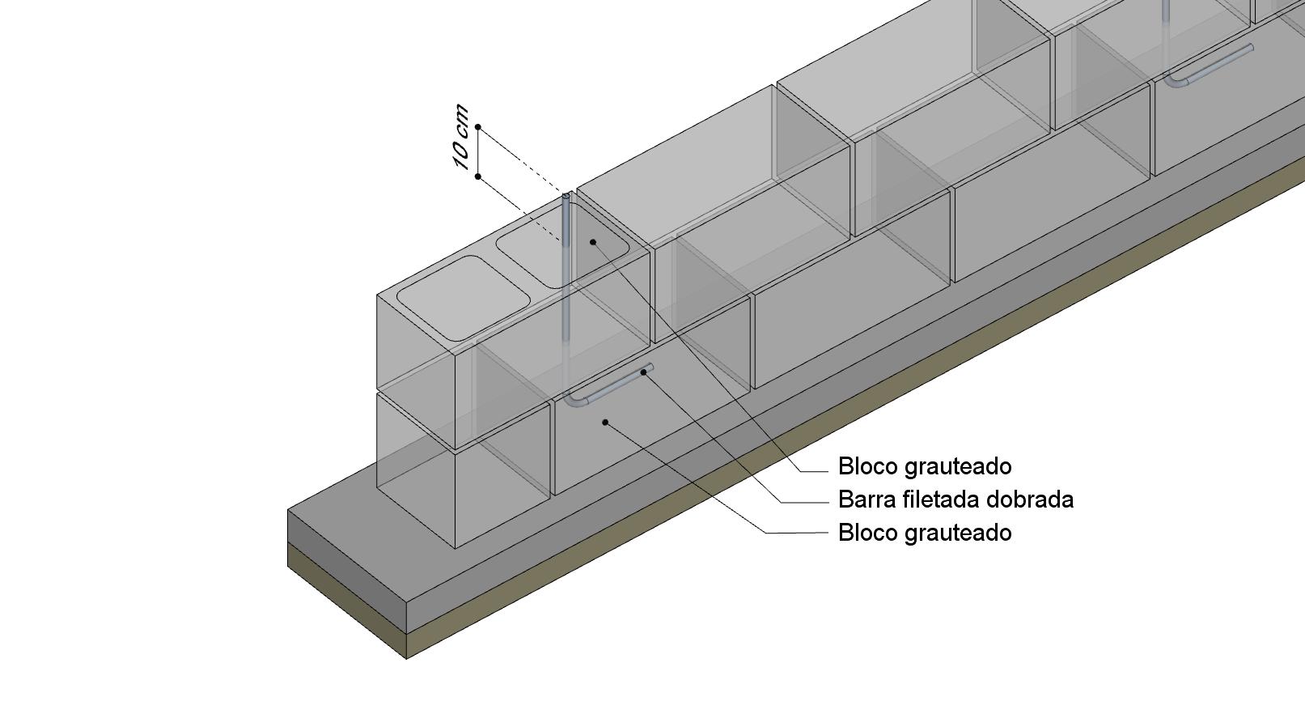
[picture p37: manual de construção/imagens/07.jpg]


**Opcional**

Em vez das barras filetadas, podem ser usados chumbadores de aço inox para afixar as vigas-guia na alvenaria. É o sistema que acabamos usando no WikiLab.

**Opcional**

Para diminuir a quantidade de umidade que chegará à estrutura de madeira por evaporação a partir do solo, pode ser coberto a parte de solo entre as muretas de alvenaria com uma camada de 5cm de concreto:

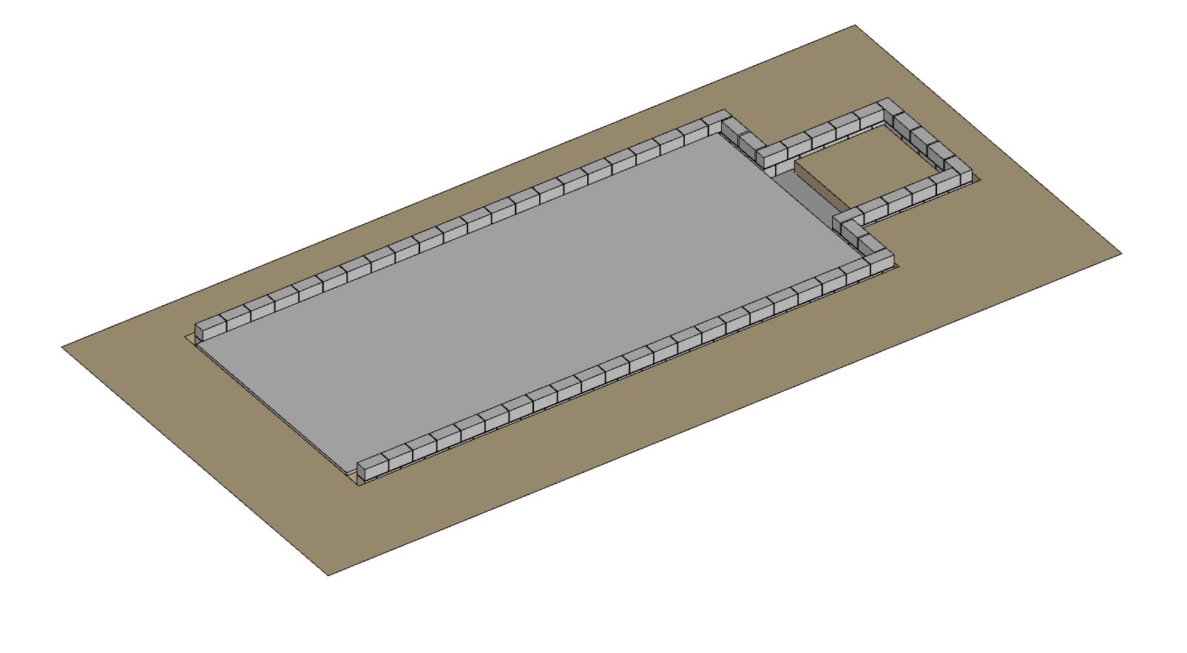
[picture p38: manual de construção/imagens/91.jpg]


Tubos de PVC para esgoto (pia e WC) e chegada de água fria estão colocados na parte interna da parede do banheiro, com cotovelos e saída embaixo da fundação. 

**Atenção**

Verificar, antes de colocar a tubulação, a localização das caixas coletoras de esgoto, e da disponibilidade de chegada de água fria

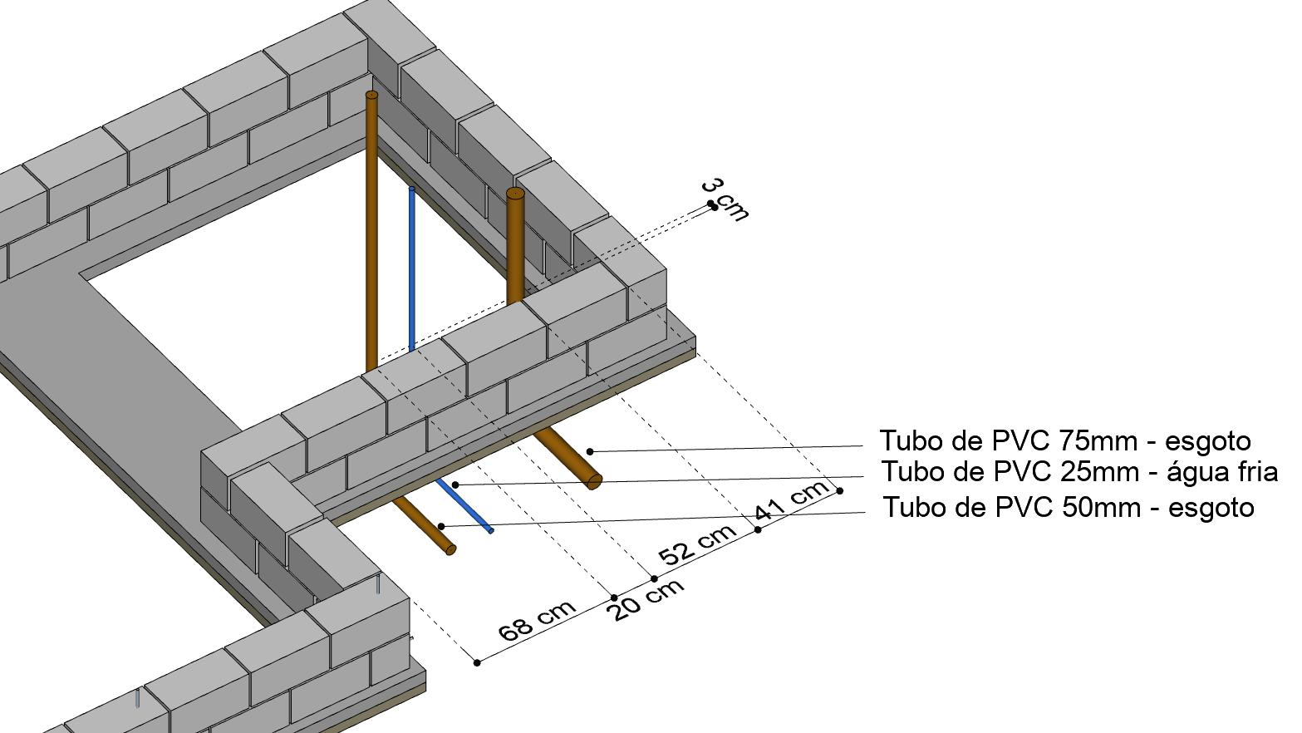
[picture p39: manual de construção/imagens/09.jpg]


Da mesma mandeira, dois tubos são colocados para chegada de energia elétrica e lógica (rede/internet):

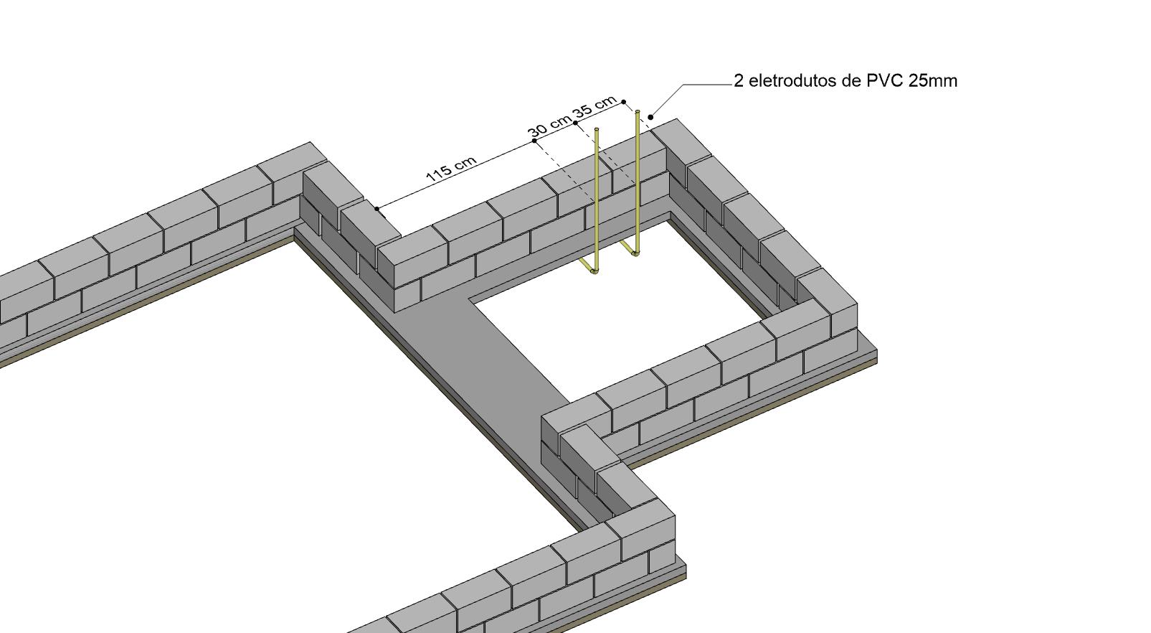
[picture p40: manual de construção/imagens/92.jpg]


Em seguida, as duas fileiras de blocos são impermeabilizadas com pintura bituminosa:

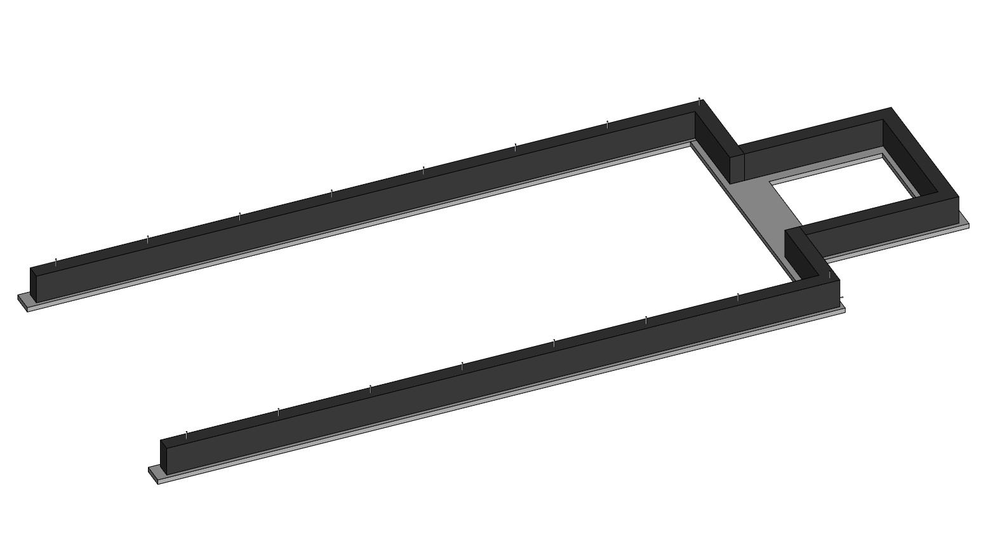
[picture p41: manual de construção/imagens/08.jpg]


Apos esta operação, as valas devem ser reaterradas até o nível do solo.

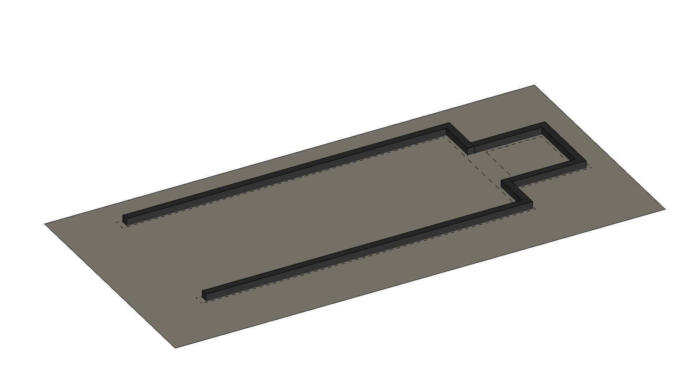
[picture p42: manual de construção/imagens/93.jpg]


Uma fileira adicional é colocada em cima do bloco sanitário:

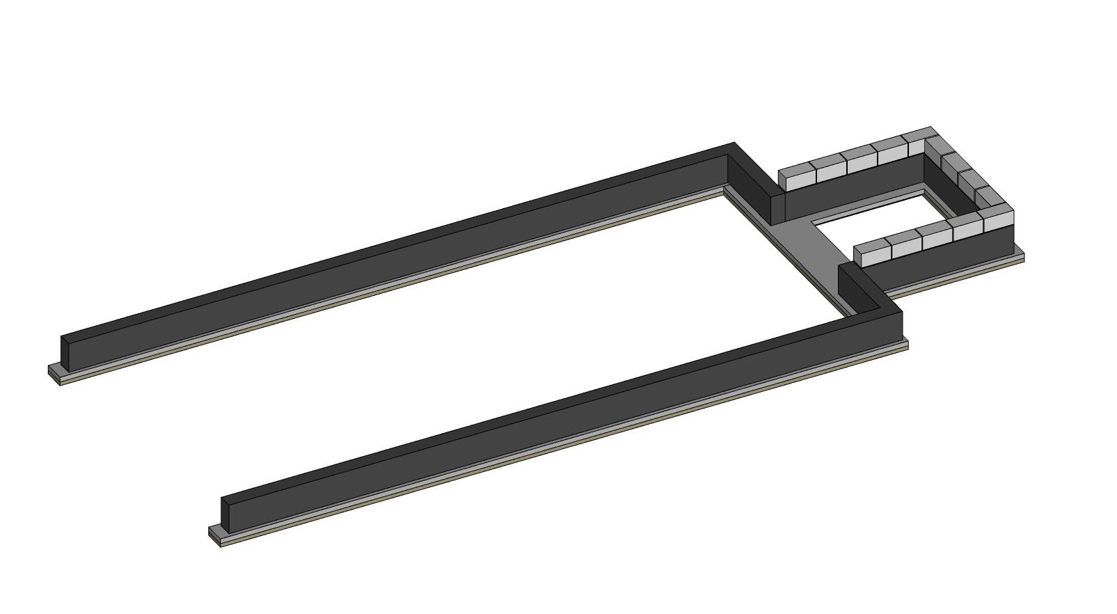
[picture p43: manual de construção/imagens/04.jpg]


### 1.3. Alvenaria superior e lajes

Antes de realizar a laje do bloco sanitário,  a parte situada embaixo da laje será reaterrada e compactada, para formar uma base para a concretagem. A terra é em seguida recoberta com uma membrana plástica.

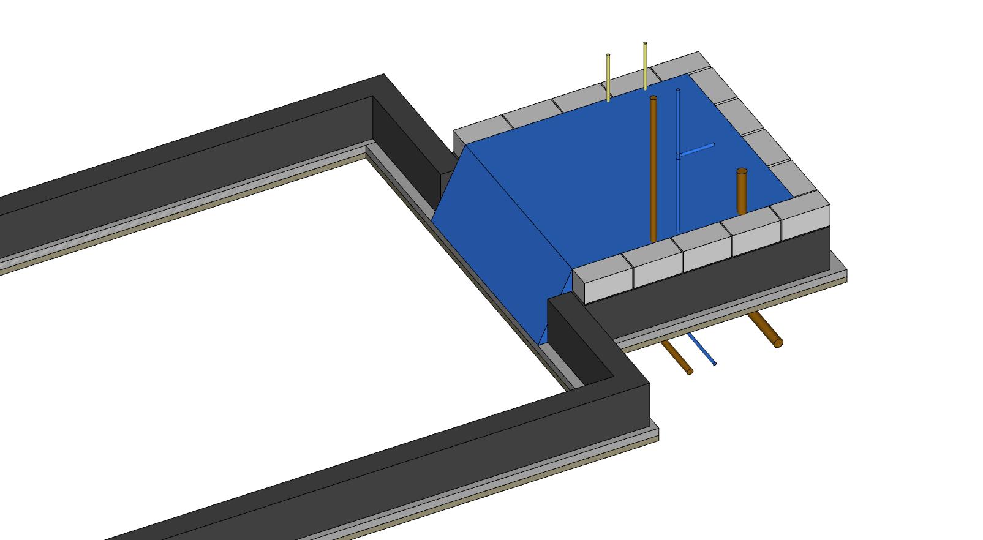
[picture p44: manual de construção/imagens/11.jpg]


Tábuas são colocadas na periferia e pregadas umas à outras. A borda superior das tábuas deve ser perfeitamente horizontal, a 9 cm em cima da alvenaria. Os furos dos blocos de alvenaria podem ser tampados com papelão, isopor ou areia

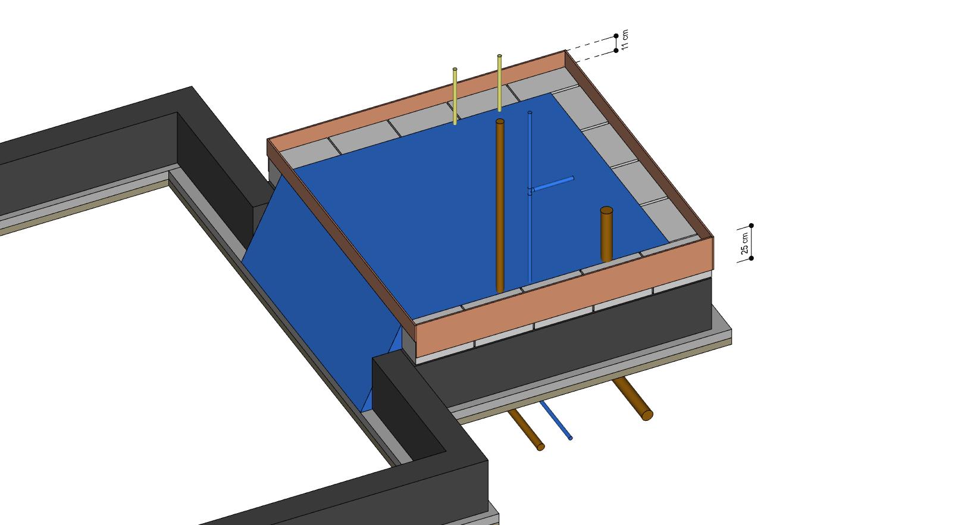
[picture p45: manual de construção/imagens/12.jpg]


No fundo da forma é colocada uma tela de aço de bitola 4.2mm com malha de 20cm, ou de bitola 3.4mm com malha de 15cm, sobre espaçadores de plástico para manter a tela a 2cm do fundo da forma

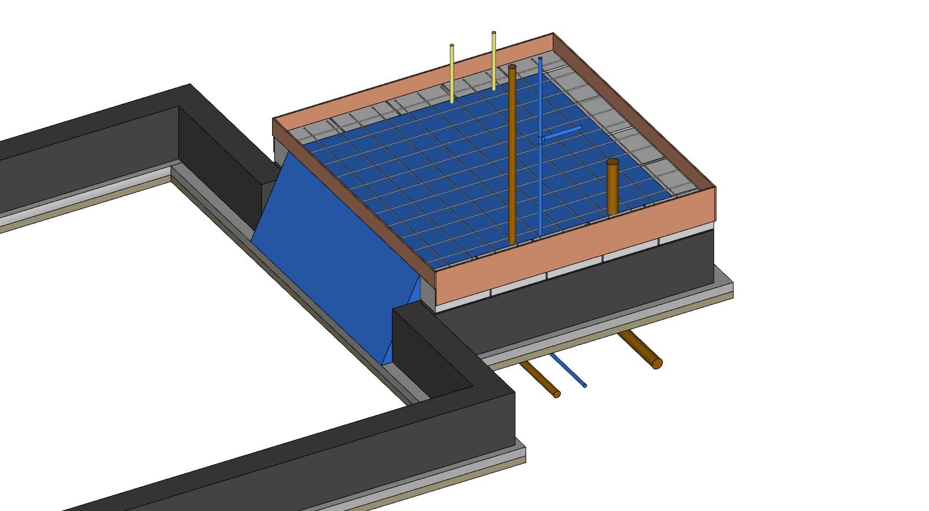
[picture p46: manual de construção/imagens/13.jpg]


Finalmente o concreto é colocado para formar uma laje de 9cm de espessura, até a borda superior das tábuas. Depois da concretagem, as formas de madeira devem permanecer por 3 dias, e a laje deve ser regada 3 vezes por dia, e coberta por uma lona para freiar a evaporação, durante 7 dias.

Deve ser usado um concreto de traço 1:2:3 (uma parte de cimento, 2 partes de areia, 3 partes de pedra)

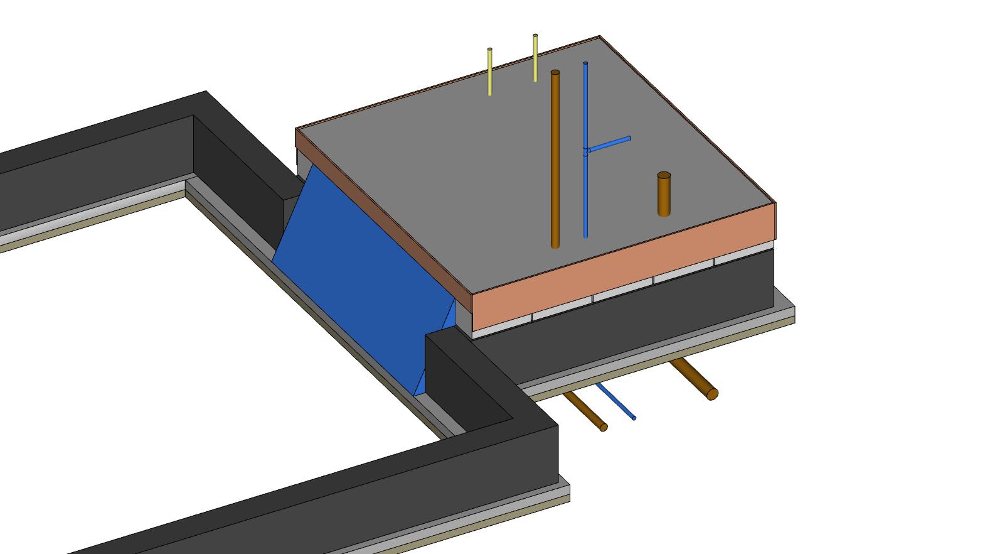
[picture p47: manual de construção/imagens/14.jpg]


A partir de 24 horas após a concretagem, a primeira fileira de blocos já pode ser colocada. Devem ser preivistas barras de reforço de aço de 5mm de 50cm de comprimento em cima da primeria fileira.

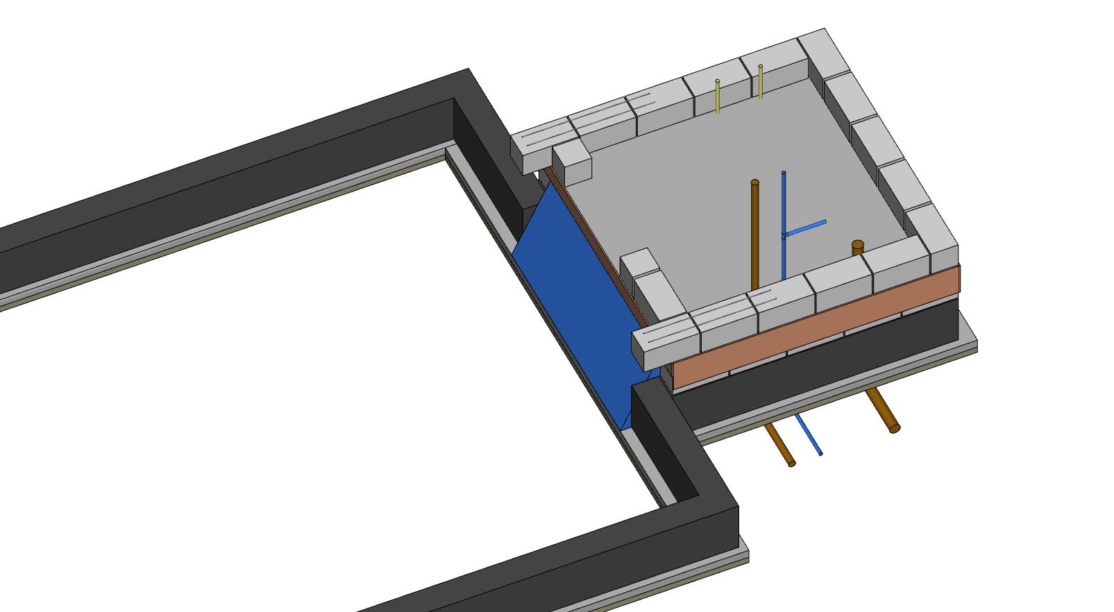
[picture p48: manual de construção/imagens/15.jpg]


Depois se colocam 11 outras fileiras, para obter uma altura total de 12 fileiras x 20cm = 240cm.

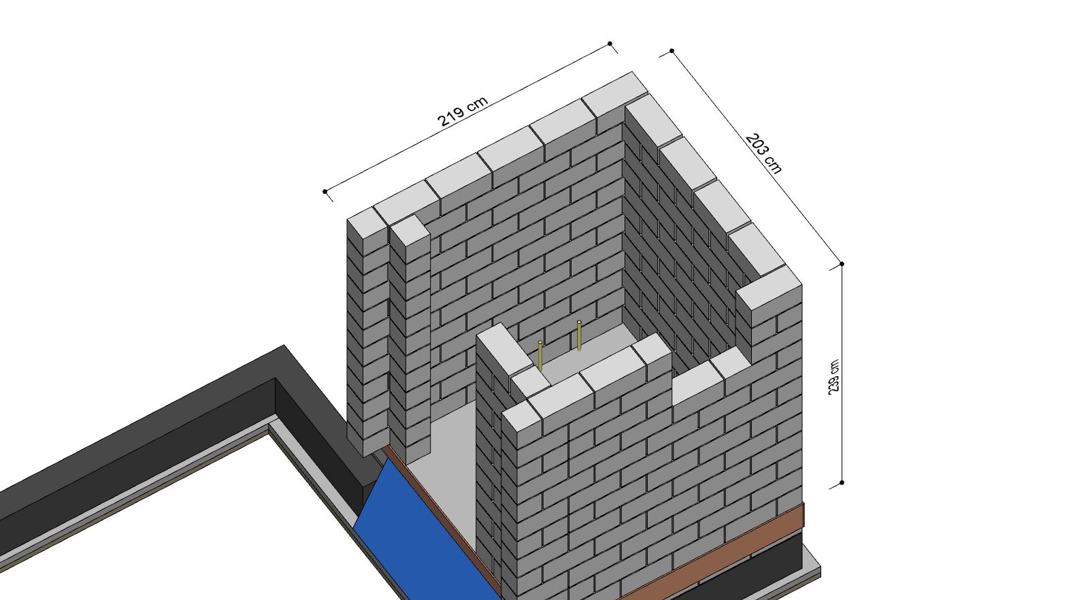
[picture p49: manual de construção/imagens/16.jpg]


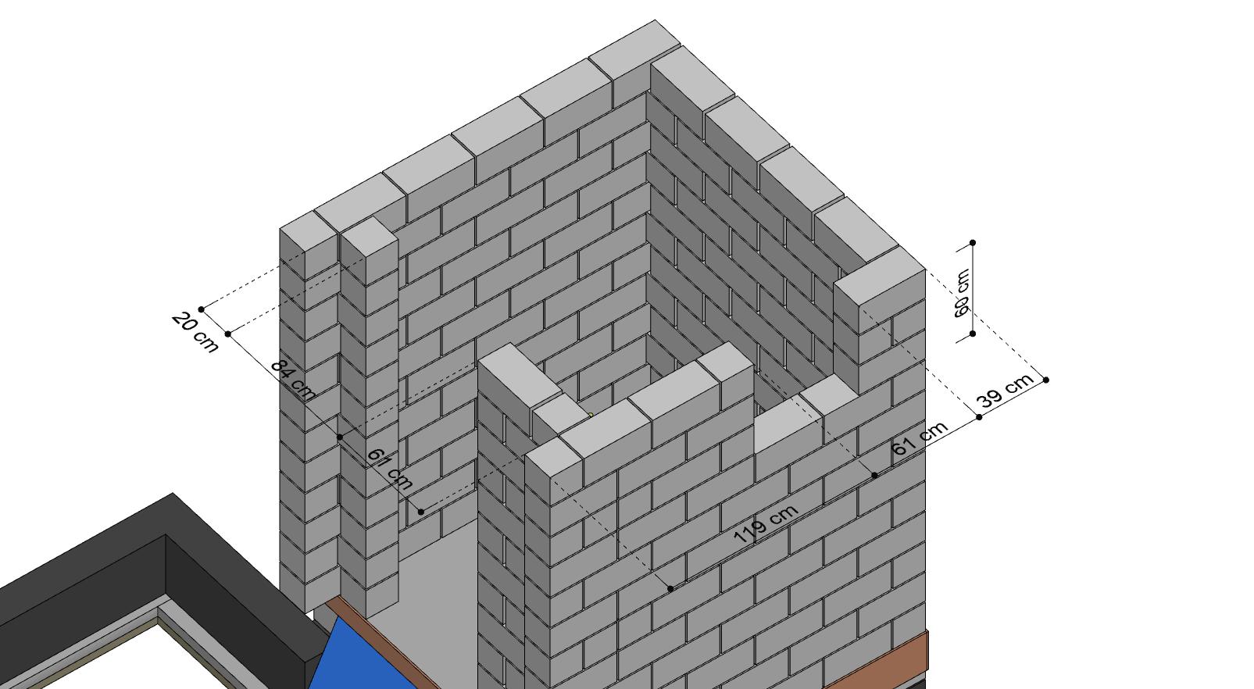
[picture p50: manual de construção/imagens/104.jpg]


A forma da laje superior é feita com painéis de compensado suportados por escoras

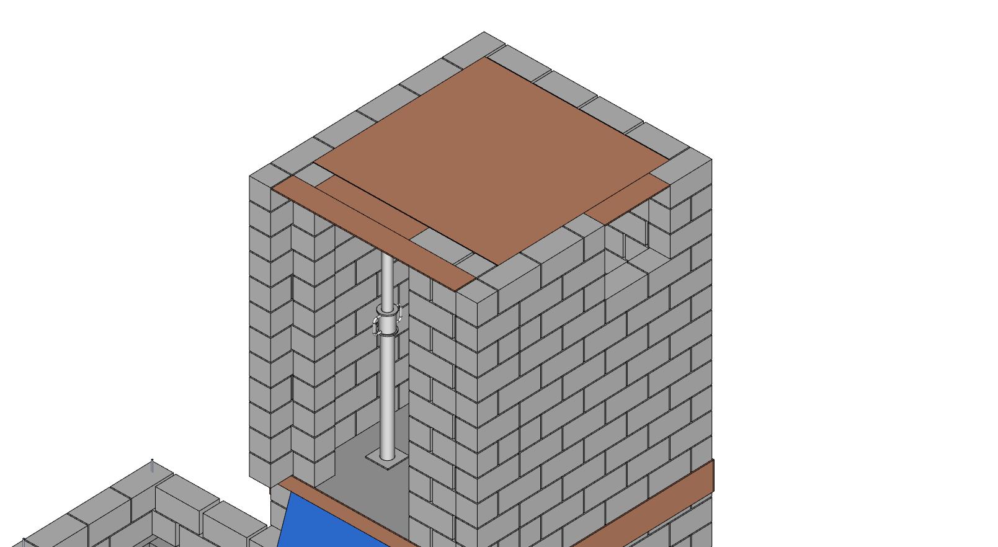
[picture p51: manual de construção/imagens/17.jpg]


Os painéis de borda são colocados da mesma maneira que a laje inferior, para formar uma laje de 9cm do lado exterior, 10cm do lado interior, para formar uma leve inclinação.

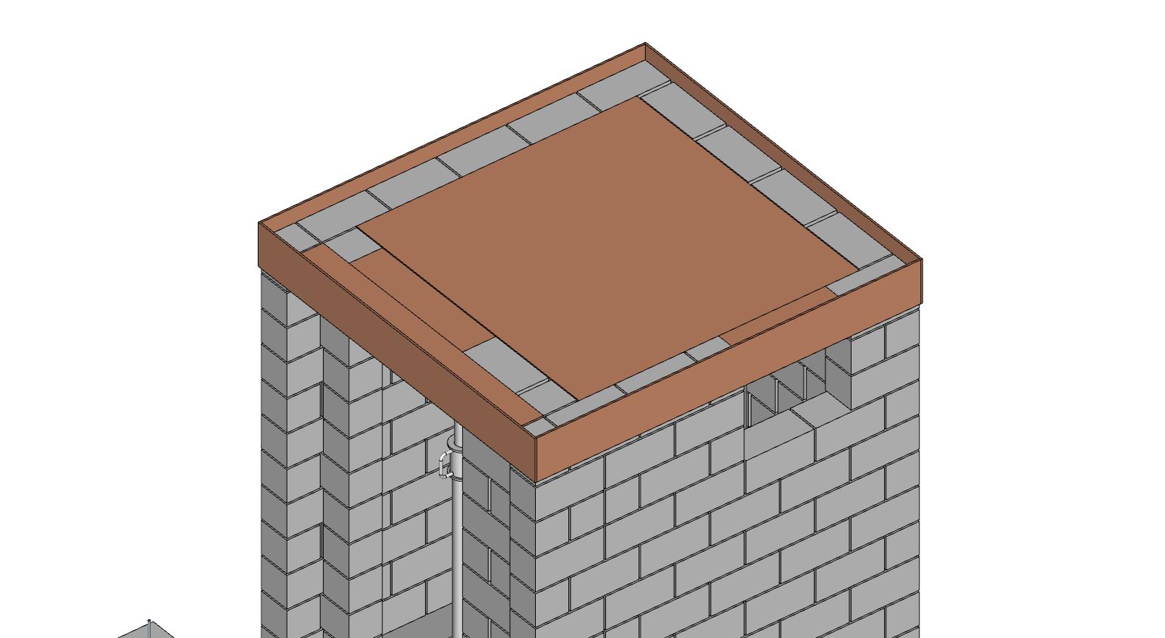
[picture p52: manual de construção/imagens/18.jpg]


Uma tela metálica idêntica à laje inferior (bitola 4.2mm com malha de 20cm, ou de bitola 3.4mm com malha de 15cm) é colocada sobre espaçadores de 2cm

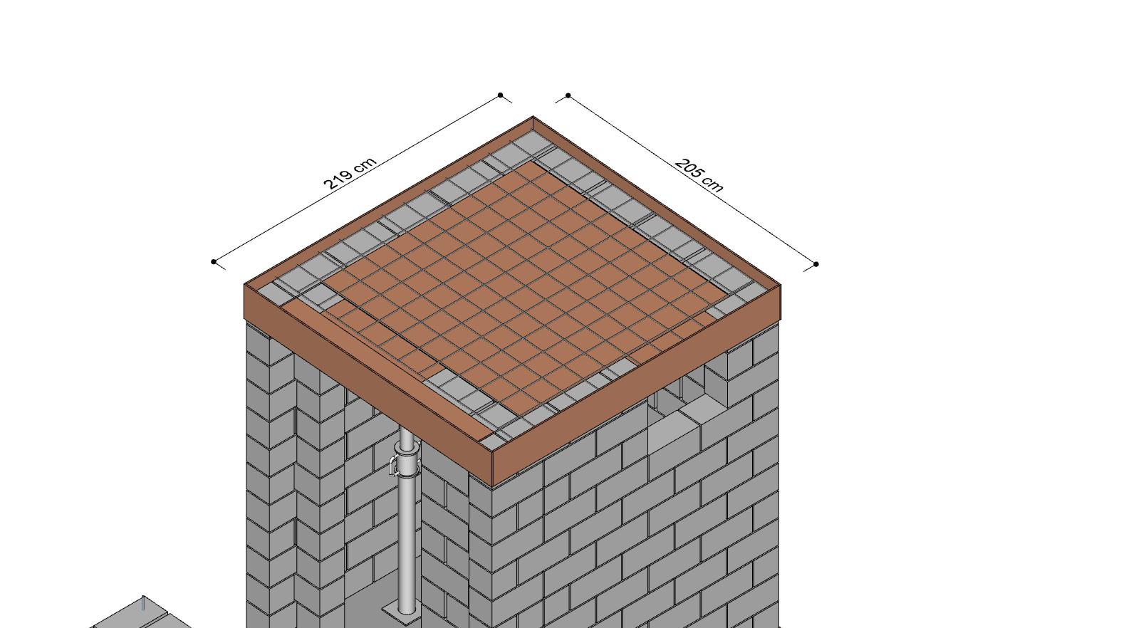
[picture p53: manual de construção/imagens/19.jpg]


E finalmente o concreto é colocado, com adjuvante impermeabilizante. Duas regras são colocadas para formar uma borda de 2cm

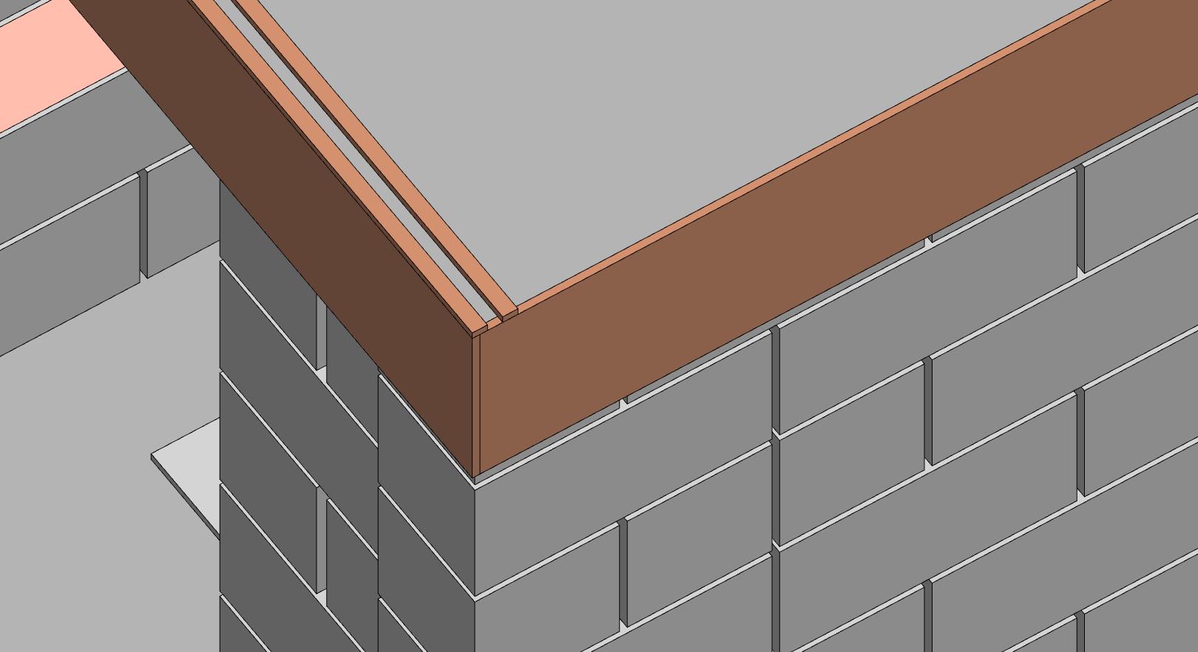
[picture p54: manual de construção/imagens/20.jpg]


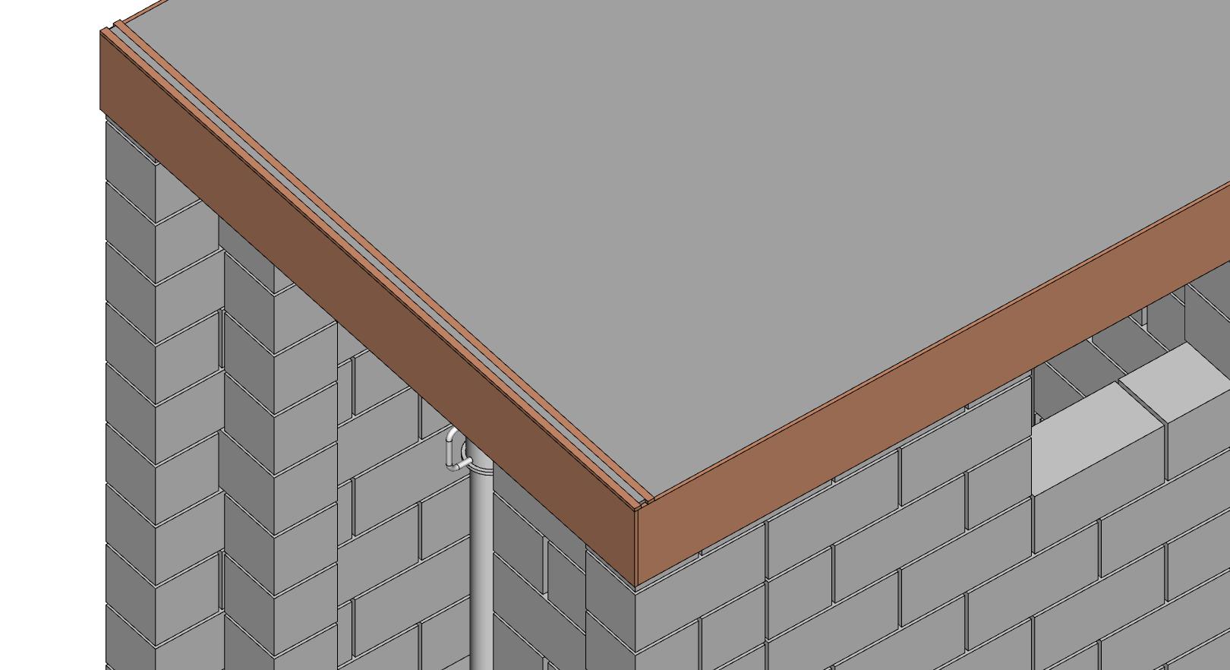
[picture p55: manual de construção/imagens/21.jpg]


A laje deve ser coberta por lona e regada 3 vezes por dia durante 7 dias. As tábuas laterais podem ser retiradas após 3 dias, e as escoras após 21 dias.

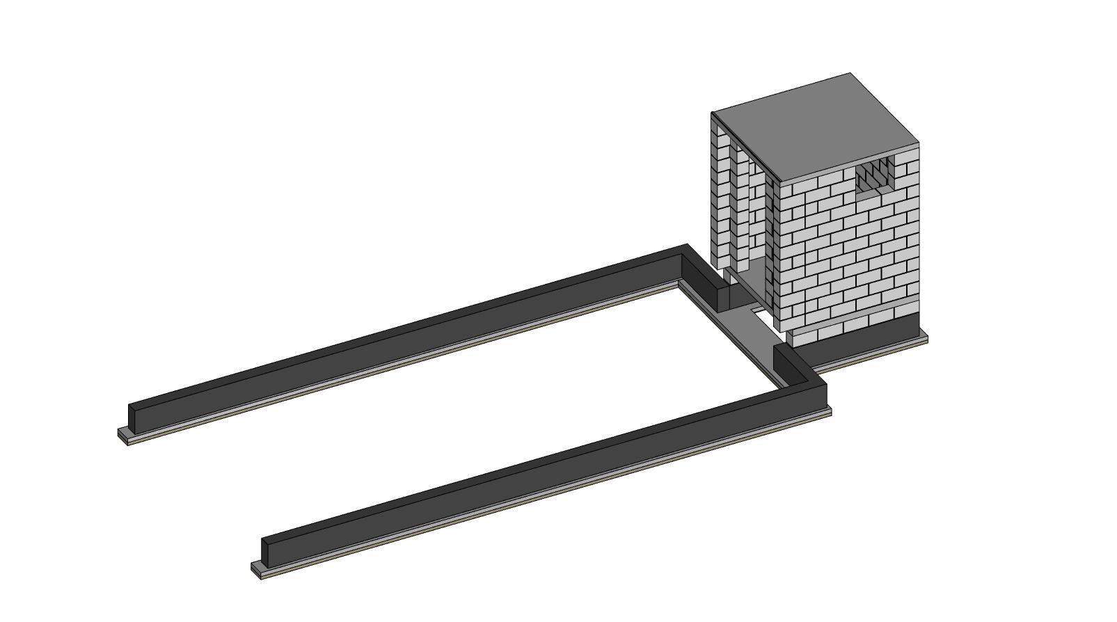
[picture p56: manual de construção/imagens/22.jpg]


### 1.4. Hidráulica

Esta parte não foi instalada no WikiLab por falta de infra-estutura (chegada de água fria e disponibilidade de conexão à rede de esgoto). No entanto, as esperas de tubulação descritas acima permitirão a fácil instalação de uma pia e de um vaso sanitário na construção quando essa infra-estrutura ficar disponível

### 1.5. Vigas-guia

As vigas-guia são feitas de perfis de madeira maciça de 6cm x 8cm (ou mais). É muito importante cuidar para obter uma perfeita horizontalidade do conjunto.

**Atenção**

As vigas devem ser posicionadas com exatamente **390 cm** entre os eixos centrais de cada viga.

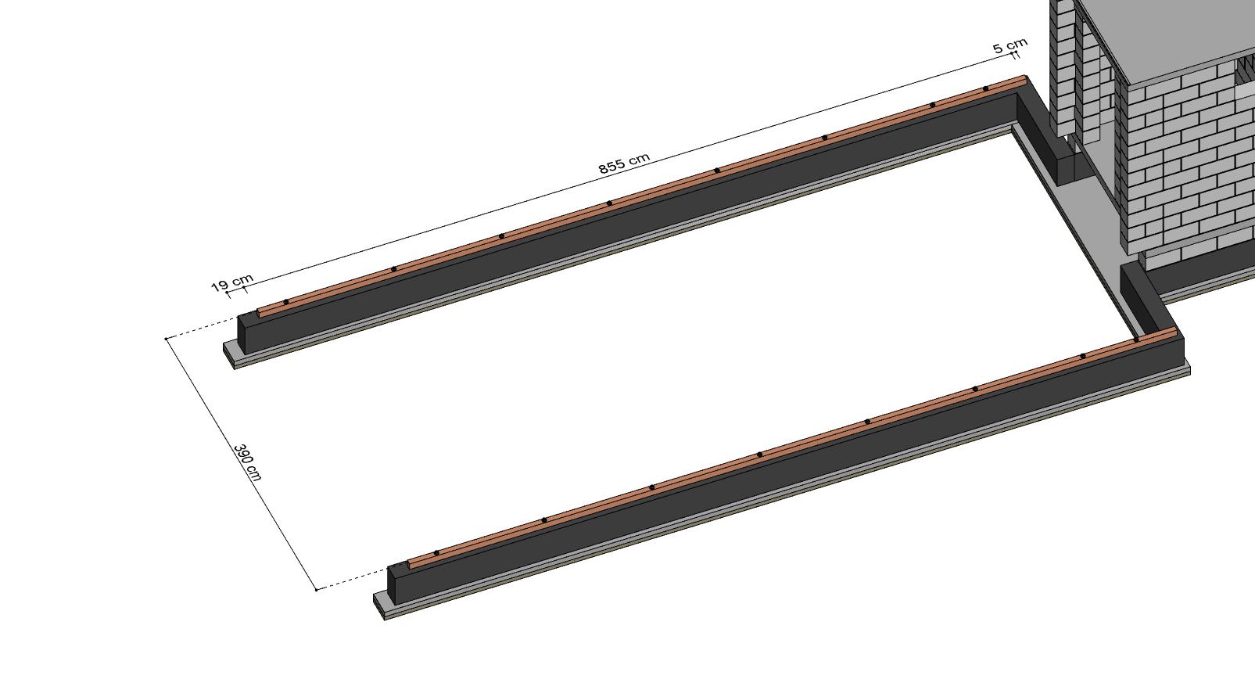
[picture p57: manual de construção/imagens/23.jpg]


**Importante** 

Sempre verificar a horizontalidade n o momento de colocar as vigas, usando um nível. É muito importante obter uma base rigorosamente horizontal, pois pequenos desníveis vão criar deformações na estrutura de madeira acima, que vão dificultar muito a colocação dos painéis depois.

As vigas-guias são fixadas com rodelas e porcas compatíveis com o diâmetro das barras filetadas. Elas devem ficar na posição vertical, para que a altura da viga seja superior a 6cm, para que a construção de madeira que ficará apoiada em cima não entre em contato com a alvenaria.

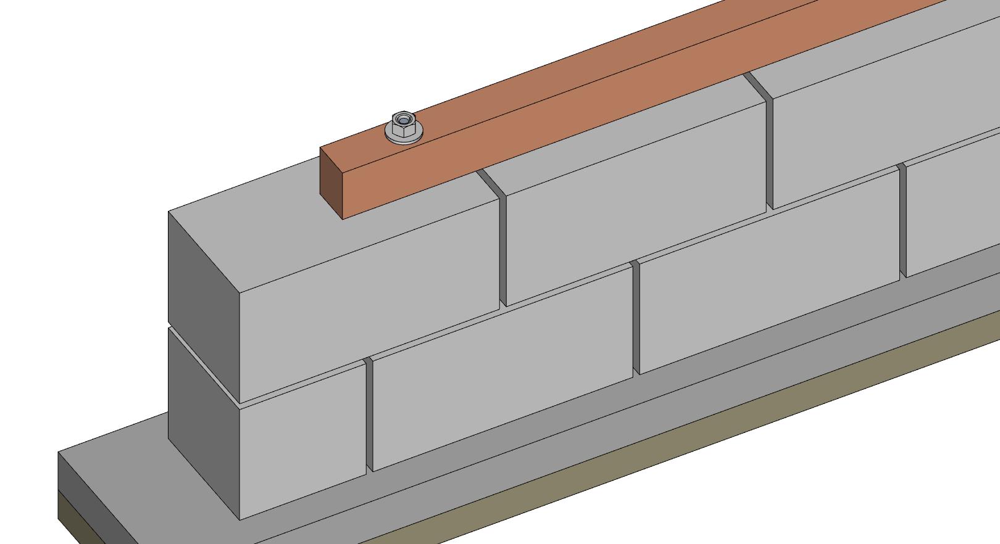
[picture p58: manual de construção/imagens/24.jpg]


## 2. WikiHouse

Esta parte é prevista para ser construída por voluntários. É recomendado contar com uma equipe de 12 a 15 pessoas.

**Atenção**

Uma obra é um entorno perigoso. Verifique que todas as pessoas presentes na obra usem sempre equipamento de segurança (capacete de obra, luvas resistentes a frição, sapatos fechados, óculos de proteção, e colete sinalizador se for trabalhar onde veículos transitam). É importante que hajam sempre pessoas designadas para cuidar da segurança de todos.

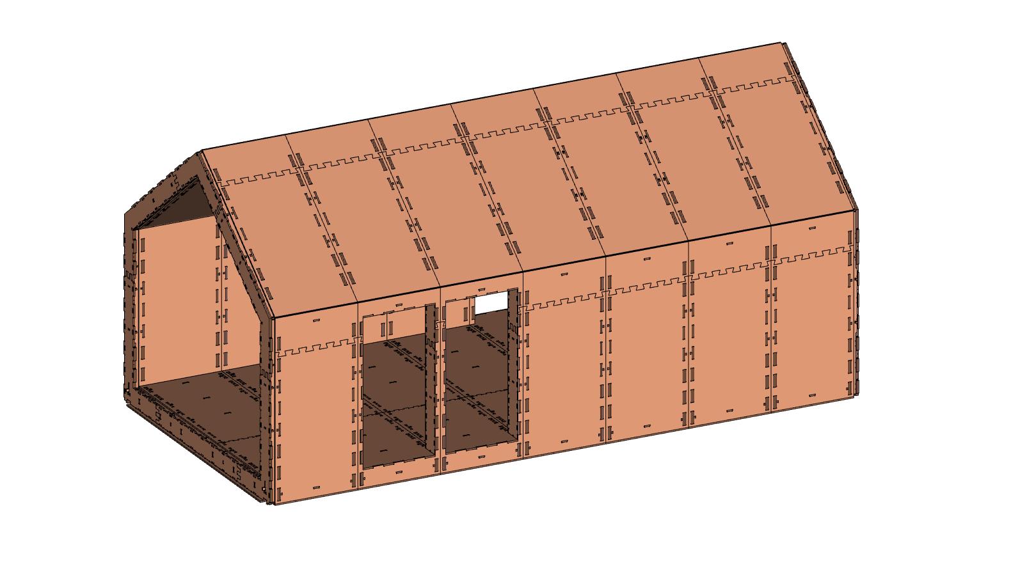
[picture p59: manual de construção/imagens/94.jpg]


**Equipamento necessário**

A construção de um WikiHouse a princípio necessita pouco material e ferramentas. Mas a facilidade e conforto do trabalho dependerão muito da disponibilidade de alguns equipamentos como escadas e andaimes. Recomendamos:

* Um martelo de borracha médio (>= 400g) para cada participante
* 3 ou 4 limas para retirar as rebarbas e alargar encaixes difíceis
* 3 ou 4 chaves de fenda grandes para ajudar o encaixe
* Duas parafusadeiras elétricas
* Uma escada grande que possa alcançar o topo (>= 4.5m)
* No mínimo 2 andaimes de 2m x 2m x 2m. A quantidade de andaimes tem impacto direto sobre a facilidade de montagem. É recomendado alugar andaimes durante a construção toda (2 a 3 semanas)
* Lonas grandes e resistentes (10m x 8m) com ainéis de fixação para poder proteger a construção da chuva
* Cordas para amarrar a lona
* Canivetes, canetas, fita adesiva industrial

### 2.1. Estrutura principal da wikihouse

A primeira parte da montagem consista em montar 8 elementos estruturais. Deve ser reservado um espaço seco, horizontal, e com piso duro (concreto, asfalto, etc...) de mais ou menos 5m x 5m, onde será montado cada elemento, e um outro lugar para armazenar os elementos prontos. Cada elemento faz mais ou menos 4m x 4m. Podem ser armazenados horizontalmente ou verticalmente, mas devem ser sempre protegidos da umidade.

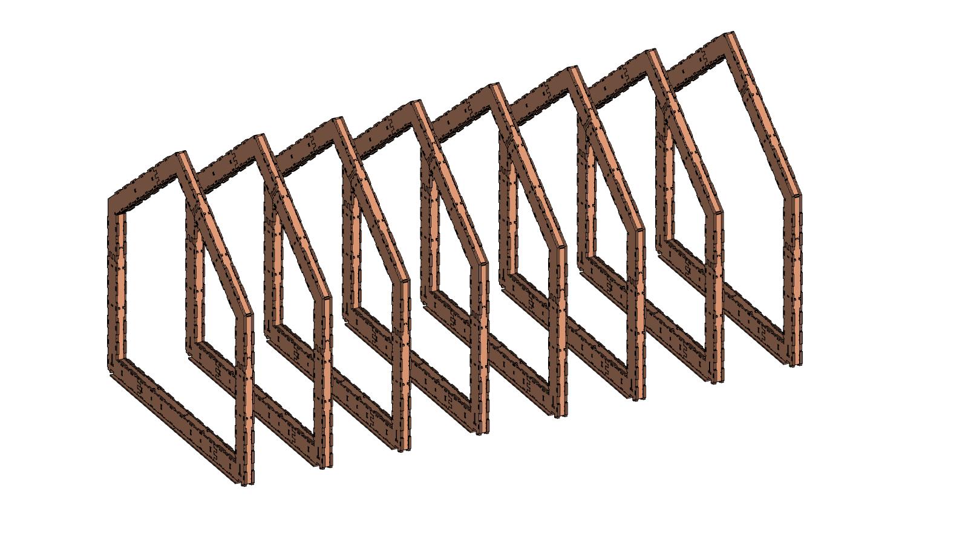
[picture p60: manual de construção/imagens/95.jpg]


As peças são numeradas e fáceis de montar com martelos de borracha. Os martelos são indispensáveis para efetuar a montagem, cada pessoa presente deve dispor de um martelo.

É recomendado sempre tentar por a numeração da peça do lado exterior, para ser mais facilmente identificável após a montagem.

O primeiro passo é colocar no chão os 6 elementos da camada de base:

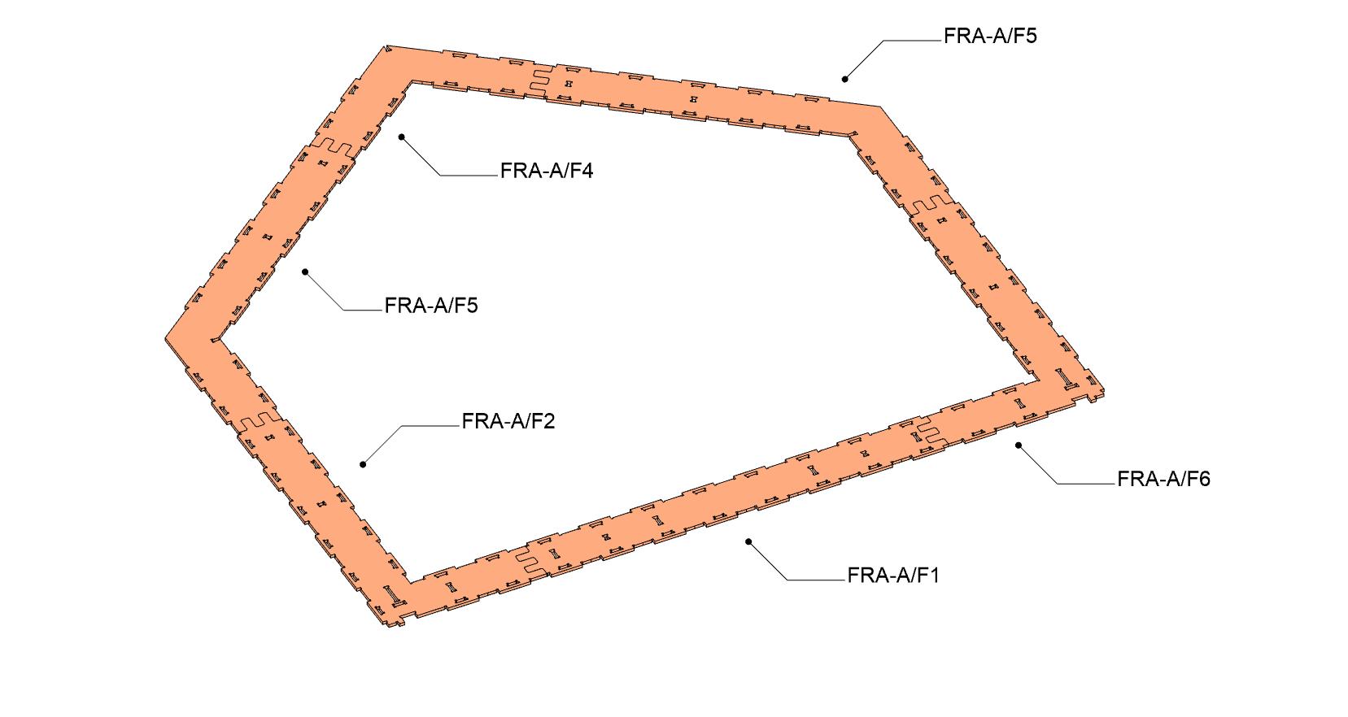
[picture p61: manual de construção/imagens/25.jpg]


Em cima dessa primeira camada, 5 peças de reforço:

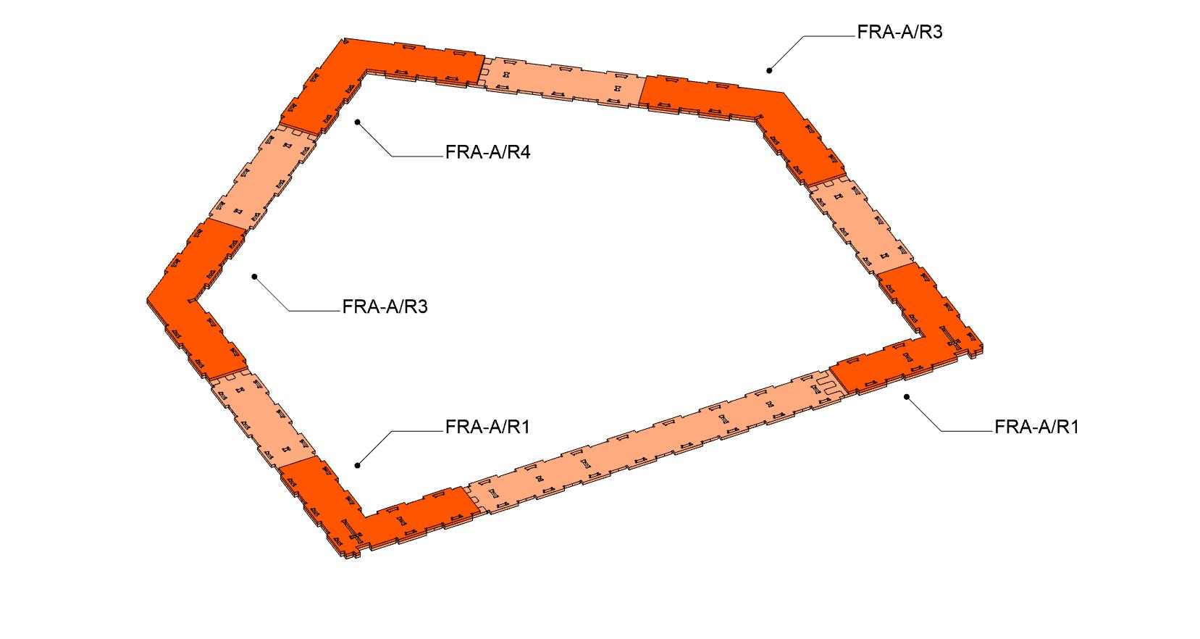
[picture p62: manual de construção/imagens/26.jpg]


As peças de reforço, opcionalmente, podem ser coladas ou parafusadas nas peças principais em baixo.

A etapa seguinte é montar o miolo. É melhor montar todo o miolo a parte:

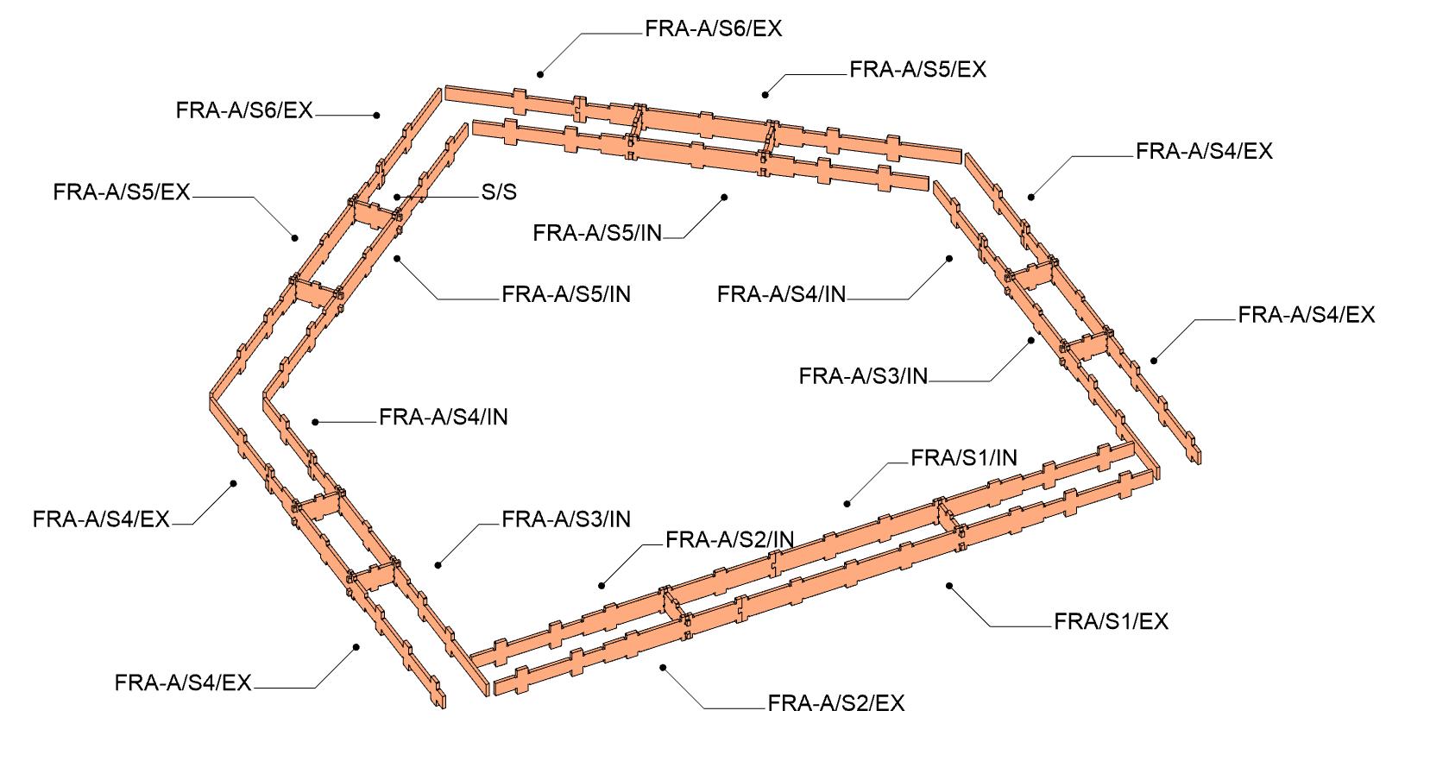
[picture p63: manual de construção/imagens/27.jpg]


Em seguinda, o miolo é inserido nas duas camadas colocadas anteriormente:

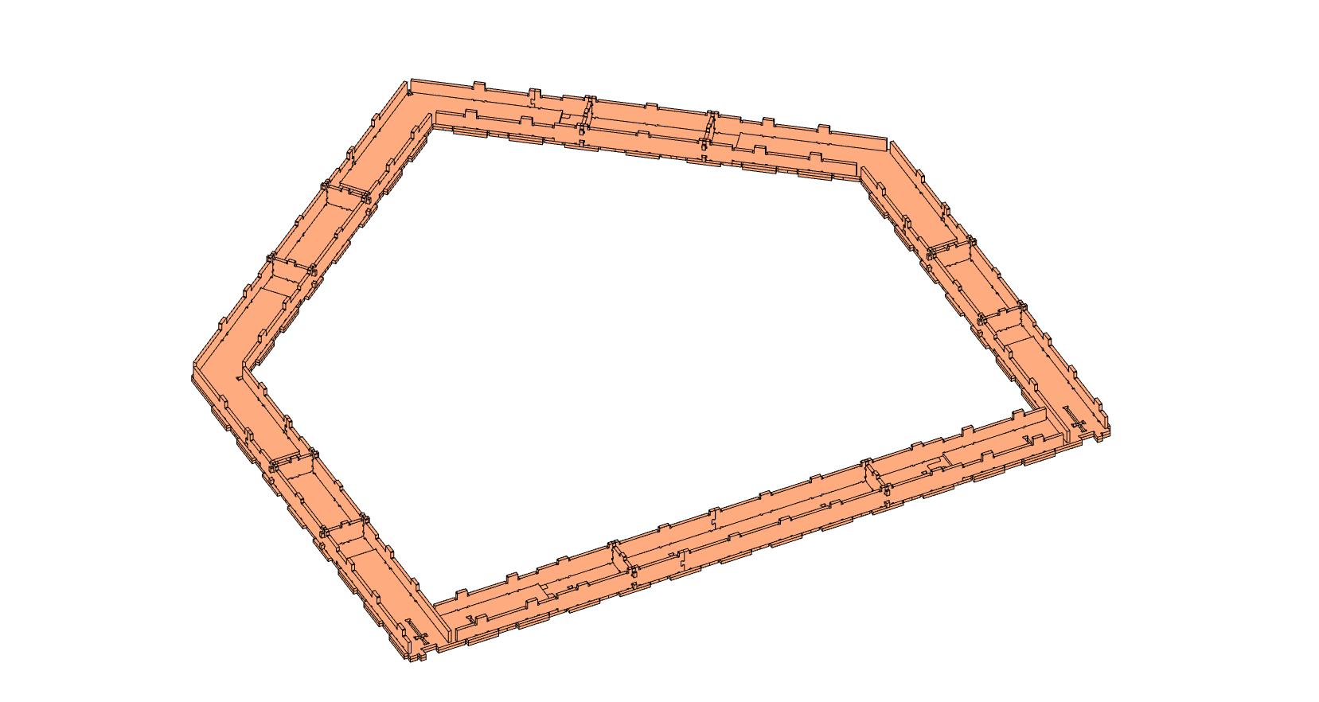
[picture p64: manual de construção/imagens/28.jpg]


Depois, mais uma camada de peças de reforço:

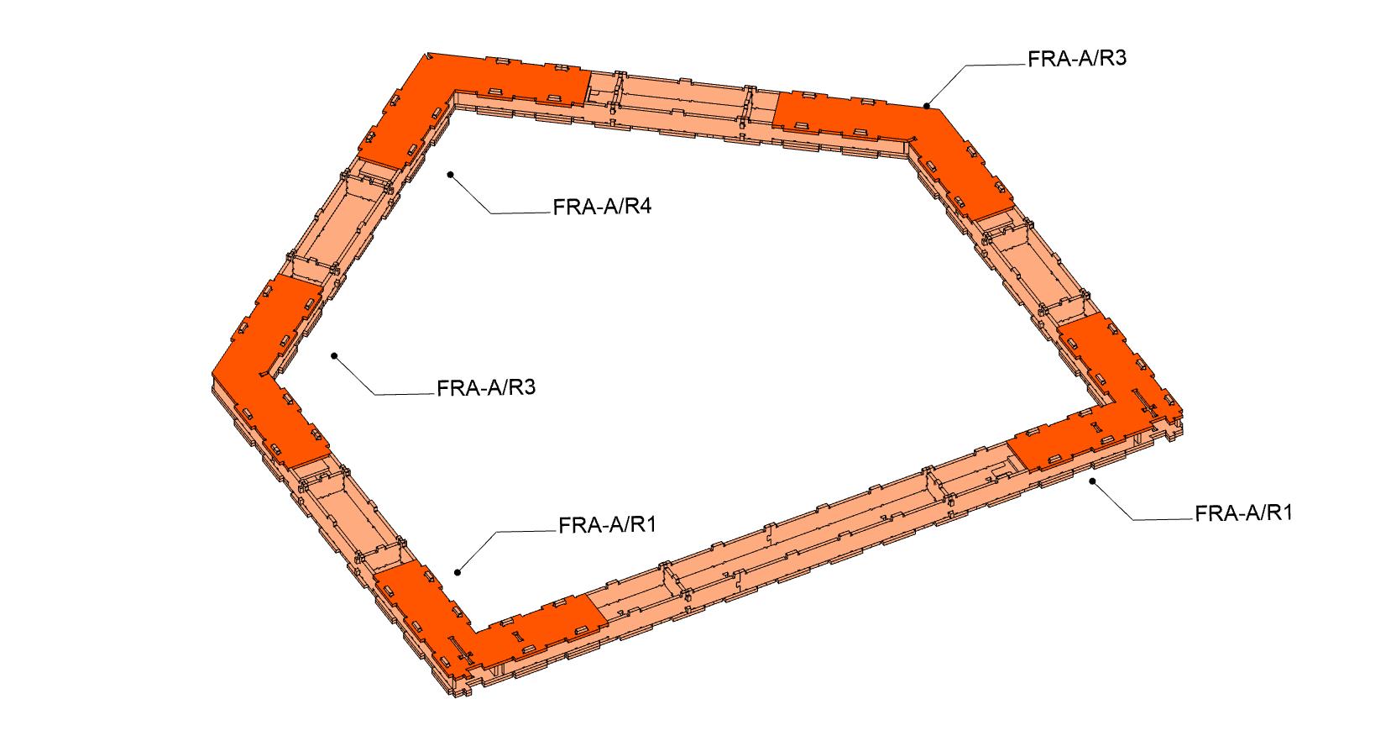
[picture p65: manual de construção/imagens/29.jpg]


E a camada exterior final:

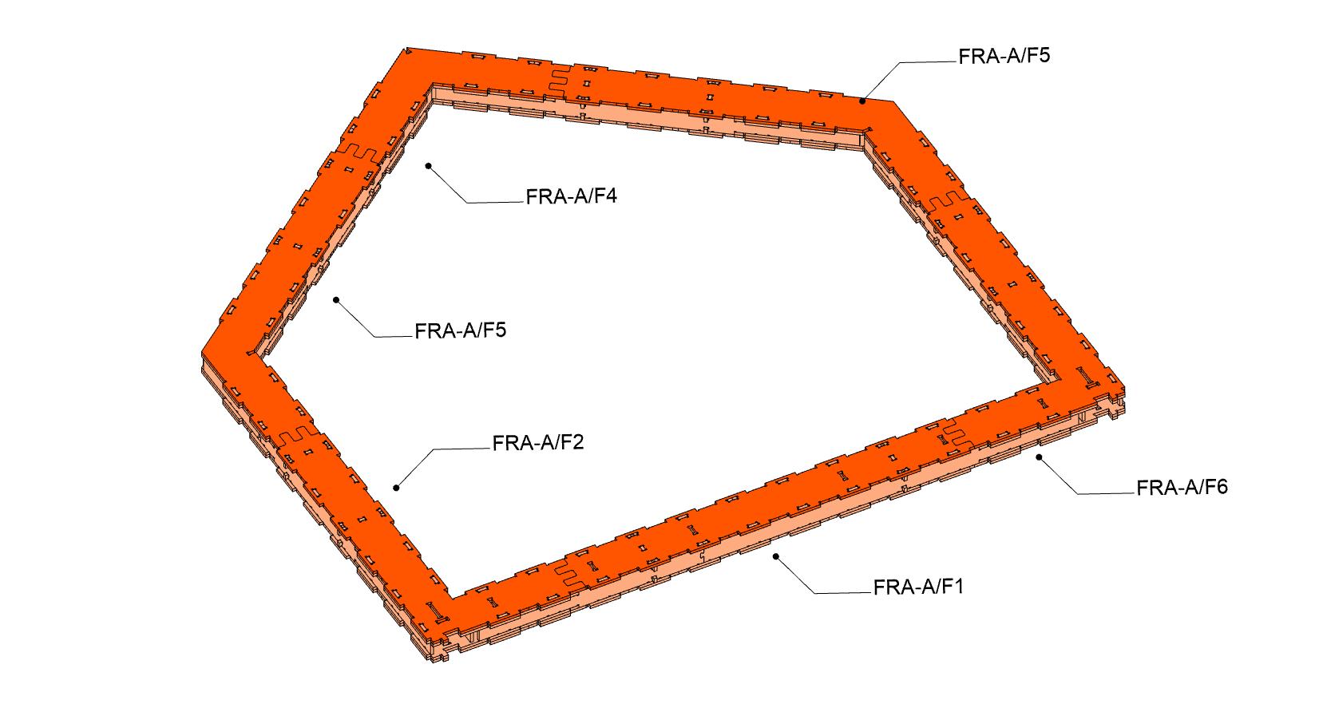
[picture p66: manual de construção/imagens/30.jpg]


A última etapa é a colocação dos "skis". Podem ser difíceis de colocar, é melhor começar pelo meio. Deve ter um pouco de cuidado para não danificar as peças.



São 8 elementos como este. Se não vão ser usado imediatamente, podem ser armazenados deitados ou levantados, desde que estejam totalmente protegidos da umidade, tanto por cima (chuva) como por baixo (umidade do solo)





**Importante**

Antes de afixar a estrutura sobre as vigas-guia, uma camada de verniz deve ser passada nas vigas-guia, para evitar possibilidade da umidade subir e atingir a estrutura.

### 2.2. Colocaço e fixaço da estrutura

Uma vez os 8 elementos contruídos, podem ser colocados em cima da viga-guia, começando pelo primeiro, que está diretamente encostado na alvenaria:



Cada elemento estrutural deve ser fixado às vigas-guia por cantoneiras metálicas parafusadas, usando duas cantoneiras de cada lado (4 por elemento):



Em seguida são colocados 3 espaçadores superiores e 8 espaçadores inferiores:



E uma novo elemento estrutural, na distância marcada pelos espaçadores:



Este novo elemento também é fixado às vigas-guia por cantoneiras metálicas:



O mesmo procedimento de repete até instalar os 8 elementos:





O último elemento coincide exatamente com o fim da viga-guia:



Esse elemento é afixado com um ferro chato em vez de cantoneira:



Novamente, se a próxima etapa não for feita imediatamente, é importante cobrir e proteger esta estrutura da chuva, por exemplo com lona plástica.



### 2.3. Painéis de fechamento

Uma vez a estrutura erguida, os painéis de fechamento interiores e exteriores são colocados em cada módulo. São 3 módulos inteiramente fechados, e 4 módulos com janela. A disposição desses módulos pode ser mudada na hora de montar, no projeto original, a sequência é:

* 1 módulo fechado (laranja)
* 2 módulos com janela do lado esquerdo
* 1 módulo fechado (laranja)
* 2 módulos com janela do lado direito
* 1 módulo fechado (laranja)



Todos os módulos são simétricos, o lado pode ser invertido na obra se desejar.

Os painéis exteriores são colocados primeiros:



Em seguida, os painéis do fundo do piso. Esses painéis devem idealmente ser envernizados ou pintados, ou ser feitos com compensado resistente a umidade, antes da montagem. Esses painéis são colocados por dentro, simplesmente apoiados em cima dos "skis":

**Atenção**

Se a parte elétrica for colocada dentro das paredes ou abaixo do piso, essa parte deverá ser pronta agora, uma vez que não estaŕa mais acesível após os painéis de piso e paredes terem sido colocados.



Finalmente os painéis interiores são colocados:



A mesma operação é repetida para os 2 outros módulos fechados. Para os 4 módulos com janela, a sequência de montagem é a mesma, mas o número das peças é diferente. As peças exteriores:



e interiores:



Para aumentar a resistência do conjunto, todas as peças interiores e exteriores devem ser parafusadas aos elements estruturais, usando parafusos de 35mm.



Devem ser usados mínimo 4 parafusos para as peças pequenas (L46, L48, L61), e 8 parafusos para as peças grandes (L45, L47, L62, L63, L64, W1, W3). São um pouco menos de 100 parafusos por módulos.

Novamente, se a operação posterior não vai ser feita imediatamente, é indispensável proteger esta estrutura da chuva, por exemplo com lona plástica





**Opcional** 

Para aumentar a resistência ao fogo da construção, é recomendado passar um verniz anti-chamas na parte interior da construção. Seguir as instruções fornecidas com o verniz.

## 3. Cobertura

A cobertura funciona como um guarda-chuva, e protege a estrutura de madeira da chuva, sem encostar nela, para permitir que o ar passe em volta da madeira. Esse ponto é muito importante para garantir que a madeira sempre possa secar sem que se forme condensação. 



Para que o ar circule entre a madeira e a cobertura, aberturas são deixadas, para que o ar mais frio (mais pesado) entre por baixo, seja esquentadopelo sol batendo na cobertura, suba (o ar quente, mais leve, sobe) e possa escapar por aberturas superiores.

Desse modo, não somente impedimos a água de atingir a madeira, mas também permitimos uma ótima secagem caso alguma umidade consiga chegar de algum modo até a madeira.

### 3.1. Montagem da estrutura da cobertura

Uma primeira camada de ripas de 3cm x 3cm é parafusada na estrutura de madeira. São 60 ripas de 260cm, com 6 parafusos de 45mm por ripa (360 parafusos no total)



A seguir, são colocadas ripas transversais, também de 3cm x 3cm. São 24 linhas de 905cm. Usando ripas de  3.5m, são 72 peças. Deve ser colocado um parafuso de 55mm a cada cruzamento com ripas verticais. No total, são 360 parafusos.





As emendas entre as diferentes ripas devem ser feitas quando cruzam as ripas verticais:



No topo, duas ripas de 3x6cm são parafusadas a última fileira de ripas horizontais. Essas duas ripas maiores suportarão a cumeira.





**Opcional**

Em vez das ripas de suporte da cumeira, a mesma pode ser afixada diretamente na telha, usando calços de plásticos para manter o espaçamento entre a telha e a cumeira.



### 3.2. Colocaço das telhas

A cobertura é prevista para ser feita com telhas de polipropileno transparentes. Podem também ser usados painéis de policarbonato, ou fibro-cimento, nestes casos verificar as recomendações de montagem do fabricante, e adaptar os instruções abaixo se necessário.

As telhas de polipropileno são baratas, e como são tranparentes, deixam passar a luz. No entanto, deixam também passar muito sol. Pode ser necessário cobrir elas depois de prontas, totalmente ou parcialmente, por exemplo pintando com spray de tinta branca, ou deixando crescer vegetação rasteira, ou, idealmente, plantando árvores ao redor da construção, o que também vai protegê-la do vento.

No total são 2 painéis de 270cm x 905cm e dois painéis de 280cm x 905cm, e 905cm de cumeira:



As telhas devem ser montadas com o lado liso virado para o exterior. Quando colcoadas uma ao lado da outra, devem cobrir duas ondulações da telha anterior:



É recomendado usar telhas de comprimento maior que 280cm, para que cada pano seja feito de uma telha só. Caso não for possível, o recobrimento mínimo entre uma telha e outra no sentido do comprimento é de 30cm:



As telhas devem sempre ter um parafuso na primeira e última ondulação. A primeira onda deve passar da borda da madeira de 5cm, para protegê-la.



No total, usando telhas de 110cm, 40 telhas de comprimento mínimo de 280cm são necessárias.

A linha inferior da telha superior deve formar uma linha horizontal com a linha superior da telha inferior, para evitar que chuvas com muito vento consigam entrar:



As telhas são afixadas com parafusos apropriados, com uma rodela de borracha de cada lado da telha, no máximo a cada 50cm (diminuir essa medida se necessário, para cair num número certo de ondulações). Veja mais recomendações para fixação das telhas, inclusive com recomendações de regulagem da prafusadeira [nesta página](http://www.hipertelhas.com.br/parafusos-de-fixacao-para-telhados.html) e [nesta outra página](https://www.pinezi.com/data/arquivos/downloads/Manual%20Telhas%20Translucidas%20ESAF.pdf):



**Atenção**

Os parafusos são de um tipo especial, e devem ser usadas com uma aruela metálica e duas rodelas de borracha (uma de cada lado).



### 3.3 Cumeira

A cumeira pode ser de outro material caso não se encontre cumeira com o mesmo aspecto que as telhas. O tamanho da onda não precisa ser igual, já que a cumeira não vai encostar nas telhas.

A cumeira também deve respeitar as mesmas duas ondulações de sobreposição das demais telhas. É afixada sobre as duas ripas maiores colocadas anteriormente, de maneira a permitir a saida do ar entre a cumeira e as telhas:



É afixada com os mesmos parafusos e rodelas que as telhas:



**Opcional**

Pode também ser usada uma chapa metálica glavanizada dobrada como cumeira. Essa chapa pode ser parafusada diretamene nas ripas que suportam as telhas, usando calços de plástico para manter o espaçamento entre a chapa galvanizada. As chapas devem ser previamente furadas onde serão colocados os parafusos.





## 4. Marcenaria e caixilharia



### 4.1. Janelas e portas na alvenaria

Existe uma porta de madeira e um caixilho metálico a serem colocados na parte de alvenaria. Ambos são de dimensões padrão e podem ser comprados diretamente no comércio.

A porta é de madeira é uma porta padrão de 80cm x 210cm (essa é a dimensão do vão de alvenaria, não da folha da parta, que mede 73cm de largura, deixando 7cm para os dois montantes, um de cada lado, de 3.5cm cada um). A porta simplesmente se parafusa na alvenaria, usando buchas.



Antes de instalar a porta, deve ser decidido o sentido de abertura. A porta tem 4 configurações possíveis, deve ser pensado onde vai ficar a folha da parta quando for aberta e se não bate em obstáculos ou móveis, ou dificulta o acesso.

Em cima da porta existe um espaço de 29 cm a ser fechado com dois painéis de madeira de 29 x 80cm, por exemplo sobras dos painéis de OSB, afixados em duas peças de madeira de 29cm parafusadas na parede:



O caixilho lateral é um caixilho de alumínio do tipo basculante, também chamado "Maxim-ar", de 60cm x 60cm. É muito comum e fácil de encontrar em lojas. É fixado diretamente na alvenaria, com parafusos e buchas.



A base de alvenaria em baixo do caixilho deve ser protegido da chuva. Os blocos de concreto precisam ser grauteados, e alguma forma de proteção posta em cima, por exemplo usando uma folha de aço galvanizado presa entre o caixilho e a alvenaria:



### 4.2. Estruturas frontal e traseira

Nas partes frontais e traseira da construção de madeira, são colocados conjuntos feitos com caibros de madeira parafusados na estrutura de OSB. Nesses caibros são colocados caixilhos de alumínio de tamanho padrão, comprados em lojas, fechamentos de vidro, e fechamentos de painéis de madeira envernizados.

O suporte é feito com caibros de 6x6cm afixados diretamente na construção de OSB com cantoneiras metálicas parafusadas. A parte frontal permite a inclusão de uma porta de alumínio de 90cm x 210cm, e duas janelas de 120cm x 100cm. A parte traseira inclui duas janelas de 80cm x 80cm. As partes restantes são fechadas com vidro fixo afixado em réguas de madeira, e placas cimentícias do lado exterior, e painéis de OSB do lado interior.



#### 4.2.1 Fachada frontal



A fachada é composta de 3 camadas: 1) uma estrutura de caibros de 6x6cm, 2) um revistimento exterior de placas cimentícias, e 3) um revestimento interior de OSB. Na estrutura de caibros também são afixados os caixilhos e vidros fixos.



A estrutura de caibros é fixada diretamente no módulo WikiHouse com cantoneiras metálicas parafusados, ou pregos onde possível. Os caibros devem ser envernizados, ou deve ser usado madeira tratada para uso no exterior.





Os caixilhos de alumínio são parafusados dirtamente nos caibros, usando as instruções do fornecedor dos caixilhos:



Na parte superior, 4 quadros feitos com régua de madeira de 1.5cm x 1.5cm são pregados aos caibros, e 4 folhas de vidro são afixadas nestas réguas com massa de vidraçeiro. A régua fica do lado interior, e a massa de vidraçeiro do lado exterior:



O lado exterior é coberto com placas cimentícias parafusadas nos caibros:



**Opcional**

Em vez de placas cimentícias, podem ser usadas também chapas de polcarbonato. No WikiLab, por economia e rapidez de instalação, usamos chapas de policarbonato de 4mm de espessura para toda a parte de placas cimentícias e também a parte de vidro fixo superior.



A junção entre as placas cimentícias, e entre as placas cimentícias e as partes aparentes dos caibros e caixilhos, deve ser vedada com silicone, de maneira a formar uma fachada inteiramente impermeável.



As bordas dessa fachada, entre as placas cimentícias e a telha de polipropileno, fica aberta para permitir a passagem do ar:





Por fim, 3 painéis de OSB de 1cm de espessura são parafusados do lado interior:



#### 4.2.2 Fachada traseira

O procedimento é idêntico na fachada traseira, com medidas diferentes. Abriga dois caixilhos de alumínio basculantes de 80cm x 80cm.





Os caibros que ficam rentos à alvenaria não devem ser parafusados à alvenaria, para que possa ocorrer um movimento vertical entre a parte de alvenaria e a parte de madeira. A junta entre a madeira e a alvenaria deve ser selada com silicone (indicado em vermelho na imagem abaixo):



Dois caixilhos de 80cm x 80cm são colocados, e axixados apenas na madeira. A borda que fica rente a alvenaria é vedada com silicone.



4 folhas de vidro fixas são instalada da mesma maneira que a fachada da frente:



E o todo coberto com placas cimentícias da mesma maneira que a outra fachada:



3 painéis de OSB de 1cm são parafusados aos caibros, do lado interior:



A fachada acabada:



O WikiLab está agora totalmente protegido da chuva.



## 5. Acabamentos

Neste ponto a construção já está pronta para ser usada. No entanto, é recomendado acrescentar alguma proteção adicional como um revestimento de piso (por exemplo, piso emborrachado, EVA, piso vinílico, ou um revestimento para pisos de madeira como Cascolac ou  Bona). 

As paredes exteriores não necessitam proteção adicional, mas as paredes interiores podem ser coberta com pintura, verniz, ou verniz especial anti-chamas para aumentar a resistência ao fogo. 

As alvenarias exteriores também não precisam de revestimento adicional, mas podem ser cobertas com chapisco ou nata de cimento, e/ou pintura.

### 5.1. Rampa

Para garantir a acessibilidade da construção a pessoas com mobilidade reduzida e/ou com cadeira de rodas, é necessário a construção de uma rampa na frente à porta de entrada. A rampa deve ter no máximo 5% de inclinação (isso é, uma rampa de 6m de comprimento), e dispor de um patamar plano de 110cm no mínimo, para que uma pessoa usando uma cadeira de rodas possa girá-la.

A rampa pode ser feita de várias maneiras, a mais fácil sendo construindo uma mureta de alvenaria na borda, e enchendo com argamassa para formar o piso da rampa.

## 6. Eletricidade



A parte elétrica da construção depende muito do uso que se faz do espaço. É recomendado sempre procurar um engenheiro ou eletricista para fazer um projeto adequado e calcular a carga elétrica a ser fornecida, o tamanho e comprimento dos cabos necessários, e o diagrama do quadro elétrico.

As instalações elétricas (condutos para fiação, tomadas, interruptores, pontos de luz) podem ser aparentes, afixados após o fim da construção, o que simplifica a mesma. Neste caso, devem ser usados condutores e caixas apropriadas (de PVC ou aço), ou instaladas dentro do vão entre os painéis interiores e exteriores. Neste caso, tuda a fiação deve ser instalada antes da colocação das paredes e pisos internos, o que complexifia muito a obra. Neste caso, é recomendado estabelecer um projeto elétrico completo antes do início da obra, e incluir furos a serem cortados nos painéis e estruturas já na fase de projeto, na preparação das chapas para que esses furos sejam cortados pela mesma máquina que fará o corte das peças.

No WikiLab, foram colocadas uma tomada no pé de cada placa interior (excluindo as janelas), e 6 lâmpadas LED no topo das paredes (3 de cada lado), comandadas por um interruptor colocado do lado da porta de entrada. Eletrodutos flexíveis foram colocados sob o piso e dentro das paredes, já com toda a fiação apropriada, antes do fechamento das mesmas.



Após o fechamento das paredes, tomadas, lâmpadas e interruptores foram parafusados diretamente na madeira.

Finalmente, um quadro geral é instalado na parte de alvenaria, alimenta dois circuitos, um para as tomadas e um para a iluminação. 



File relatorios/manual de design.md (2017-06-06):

# Manual de design do wikilab



Este manual foi/está sendo escrito no correr do desenvolvimento do projeto [Wikilab](https://github.com/uncreatednet/wikilab-ufabc) por Yorik, arquiteto do [Uncreated](http://www.uncreated.net) e um dos desenvolvedores do projeto.

O conteúdo deste manual é sob licença Creative Commons, e pode ser copiado, distribuído, usado e modificado livremente por quem quiser. Ele é construído a partir da nossa própria experiência, e a partir do [manual de design do módulo "Wren" do WikiHouse](https://github.com/wikihouseproject/Wren/wiki/Wren-Technical-Design-Guide).

#### Atenção

Não esqueça, este manual apenas reflete a nossa experiência no desenvolvimento do WikiLab, e não deve ser considerado como algo oficial, ou como uma garantia qualquer. Se você planeja construir um WikiHouse, procure sempre o conselho de algum profissional da construção (engenheiro, arquiteto ou afim). O custo disso é pequeno quando se trata apenas de aconselhar, e a construção de uma estrutura onde pessoas vão permanecer é algo sério, que pode ter consequências graves. O lugar e as condições onde você vai construir podem requerer medidas que não estão neste manual. 

Contate um engenheiro ou arquiteto, combine um preço para o conselho, e inclua este custo no orçamento desde o início, e nem vai doer ;)

## O WikiHouse

Segundo a [Wikipedia](https://en.wikipedia.org/wiki/WikiHouse): O [WikiHouse](http://www.wikihouse.cc) é um sistema [aberto](https://pt.wikipedia.org/wiki/Hardware_livre) para construir casas. Ele foi pensado para democratizar e simplificar a construção de habitações sustentáveis e que necessitem poucos recursos. O projeto foi concebido em 2011 no Reino Unido, por Alastair Parvin (Aconselho muito assistir a [palestra dele no TED](w.ted.com/talks/alastair_parvin_architecture_for_the_people_by_the_people) (tem legendas em português disponíveis clicando no botão "subtitles"), Nick Ierodiaconou, Tav of Espians, James Arthur e Steve Fisher.



O sistema permite que pessoas baixem arquivos com [licenças abertas](https://pt.wikipedia.org/wiki/Creative_Commons) da internet, modifiquem se quiser esses arquivos com programas de modelagem 3D como [SketchUp](http://www.sketchup.com) ou [FreeCAD](http://www.freecadweb.org), e a partir daí criem, como uma [máquina CNC](https://pt.wikipedia.org/wiki/Comando_num%C3%A9rico_computadorizado), peças de madeira encaixáveis como em um quebra-cabeça gigante. Essas peça são montadas sem prego nem cola, com técnicas inspiradas das construções de madeira tradicionais asiáticas. Uma WikiHouse pode ser construída em um dia só, por pessoas que nunca trabalharam com construção antes.





Essa construção de madeira ainda deve ser protegida da chuva e da umidade, e equipada com instalações elétricas e hidráulicas, para poder ser usada por pessoas.

## Planejar o projeto

Essa etapa é muito importante, um bom planejamento faz toda a diferença entre um projeto bem executado, que fica dentro do custo estabelecido, e que dá pouca ou nenhuma dor de cabeça, e um projeto caro e cheio de complicações. 

#### É para mim?

O sistema WikiHouse não fornece uma habitação mais barata que uma construção tradicional de tijolos e cimento. O preço é bem similar, em torno de R$ 1200 por m² de piso. No entanto, se trata de um sistema extremamente fácil de montar, onde você está no controle total da construção. Em vez de comprar um produto (supostamente) acabado de uma empresa, você mesmo planeja, decide, construí, e modifica depois quando quiser.

Com grandes poderes vem grandes responsabilidades, e a construção de um WikiHouse requere um trabalho consequente, e, sendo experimental (tem poucas unidades construídas no mundo ainda), um acompanhamento sério após a construção. No entanto, esse trabalho todo é muito interessante, instrutivo e em muitos momentos muito divertido.

#### Encontrar uma máquina CNC

Um ponto merce um pouco de atenção antes de começar: Uma WikiHouse é feita de painéis de madeira (geralmente [compensado](https://pt.wikipedia.org/wiki/Madeira_compensada) ou [OSB](https://pt.wikipedia.org/wiki/Oriented_Strand_Board)), cortados por uma [máquina CNC](https://pt.wikipedia.org/wiki/Comando_num%C3%A9rico_computadorizado) (também chamada "Fresadora" ou "Roteador"). A possibilidade de construir depende da disponibilidade desse tipo de máquina, razoavelmente perto da obra para não gerar custos de transporte elevados.

Cada vez mais, hoje em dia, empresas aparecem em cidades de médio ou grande porte, que possuem esse tipo de máquina. Grupos como associações de makers, [hackers](https://pt.wikipedia.org/wiki/Hackerspace), ou [fab-labs](https://pt.wikipedia.org/wiki/Fab_lab) também são cada vez mais equipados com máquinas CNC. Finalmente, existem máquinas que podem ser [compradas na internet](https://www.buildyourcnc.com/blackFoot48v40.aspx) e montadas pelo usuário, que já podem ser encontradas na faixa dos R$ 10 000, o que torna isso uma solução possível para grupos e associações. Essas máquinas não tem a mesma precisão que uma máquina profissional, e requerem bastante dedicação para ser usadas, mas já foram usadas muitas vezes pelo mundo afora para produzir peças para WikiHouses.

O que se deve procurar é: uma máquina CNC que tenha o tamanho suficiente para cortar painéis de madeira de 18mm de espessura, de 1.20m x 2.40m (tamanho padrão desses painéis no Brasil).

O custo pedido por uma empresa ou associação para cortar todas as peças de uma WikiHouse pode variar muito, é sempre bom começar essa pesquisa cedo. Veja abaixo a seção "Montar o orçamento" para mais detalhes sobre o custo do corte.

#### Apoio técnico

Como já explicado acima, é importante ter o apoio de alguém que tenha bons conhecimentos e experiência na área da construção, como um arquiteto, engenheiro ou outra pessoa que tenha bastante experiência com construção, e que possa orientar, aconselhar, e evitar problemas e consequências que podem ser graves. Se trata apenas de pagar algumas horas de trabalho para que essa pessoa possa aconselhar você e vir dar uma olhada na construção. No preço total da construção, vai ser um gasto bem pequeno para ter uma segurança boa.

#### Legislação

A legislação no Brasil, como na maior parte do mundo, não permite que você construa uma estrutura onde pessoas vão permanecer sem autorização prévia. A ideia disso é garantir que todo mundo more em condições minimamente salúbrias. Para obter essa autorização, que geralmente é concedida pela secretaria de obras da sua prefeitura, deve ser feita uma demanda de autorização de construir (o nome dessa demanda, e do documento que você recebe que dá a autorização, pode variar de uma prefeitura para outra). Essa demanda geralmente incluí o preenchimento de alguns formulários, e a entrega de desenhos (plantas, vistas das fachadas, etc) do projeto, que vão permitir aos funcionários da prefeitura julgar se o projeto atende a todas as leis necessárias. Cada prefeitura tem suas próprias regras que dizem quais desenhos ela vai exigir.



A lei mais importante que um projeto de construção deve respeitar, é o código de obras do município. Esse código geralmente define todas as caraterísticas de salubridade, solidez e respeito aos demais usuários da cidade que uma construção nova deve ter. O terreno onde você planeja construir também pode ter leis municipais ou estaduais como plano diretor ou lei de uso e ocupação do solo, que podem obrigar ou proibir certos aspectos. Mas podem existir outras leis municipais, estaduais ou até federais que se aplicam também ao seu projeto. A secretaria de obras do seu município, ou seu arquiteto ou engenheiro se você já chamou algum, poderá dizer quais leis se aplicam no seu caso. 

A partir de um certo tamanho, a prefeitura vai também exigir que os desenhos estejam assinados por um profissional (arquiteto ou engenheiro) registrado.

Cada prefeitura terá também um prazo próprio para a entrega da autorização, e pode pedir mudanças no projeto se julgar que algum aspecto no se enquadra em alguma lei. É bom planejar toda essa parte com bastante antecedência.

Não se esqueça também que o WikiHouse é um sistema experimental, com poucas unidades construídas no mundo ainda, e que pode por isso assustar os funcionários da prefeitura. É sempre uma boa ideia, quando se trata de um projeto experimental, ir conversando com os funcionários da secretaria antes de fazer o pedido, explicar o projeto, mostrar outros exemplos (como este WikiLab), e "preparar o terreno".

#### O lugar

#### O orçamento

#### O programa

#### As opçoes técnicas

## Software

## Obter os arquivos

## Adaptar os arquivos

## Montar o orçamento

## Obter os recursos

## Preparar o corte

## Planejar a obra

## A obra

## O pós-obra

## A manutenção

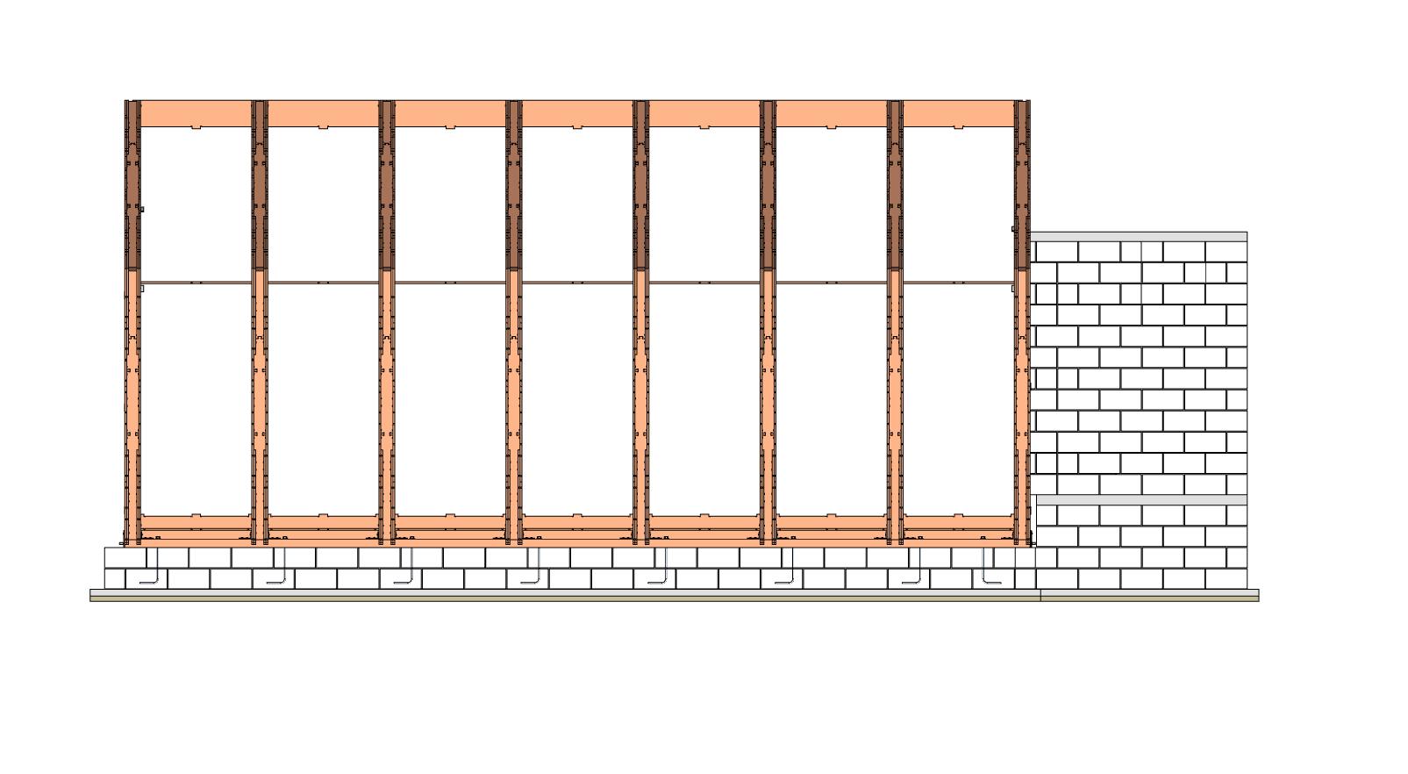
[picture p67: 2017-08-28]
manual de construção/imagens/87.jpg

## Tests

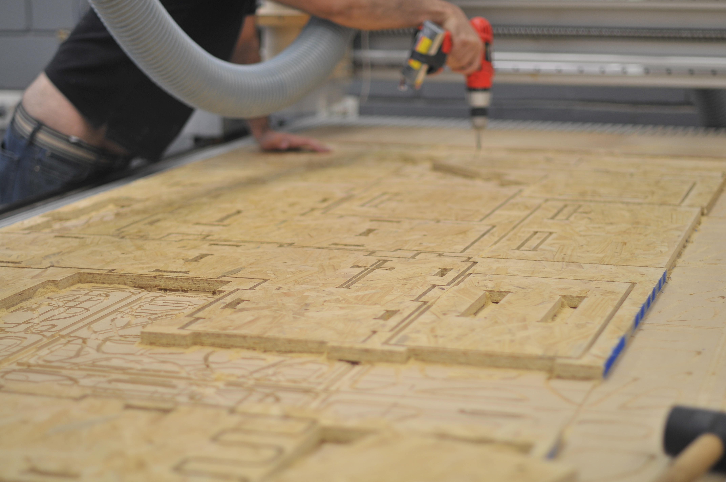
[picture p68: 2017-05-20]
fotos/teste de encaixe/_RSN6865.JPG

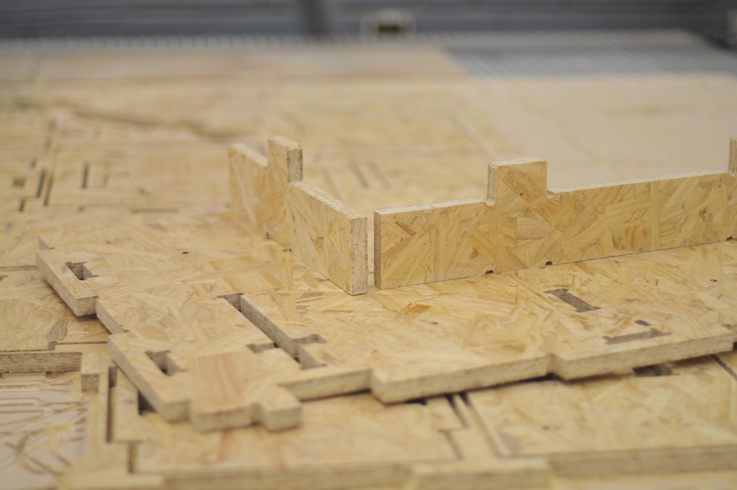
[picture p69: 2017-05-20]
fotos/teste de encaixe/_RSN6867.JPG

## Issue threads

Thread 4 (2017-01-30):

Fazer lista de empresas que podem cortar os painéis em SP

yorikvanhavre, 2017-01-30:
Procurar empresas por CNC no google ou outros meios, verificar
- se cortam painéis de 240cm x 120cm x 18mm, arquivos fornecidos em DXF, padrão wikihouse, exemplo abaixo
- se podem cortar uma parte ou todos os nossos 100 painéis, exemplo abaixo
- se estão prontos a trabalhar com a gente para resolver detalhes e probleminhas que poderão aparecer e formatar os nossos arquivos corretamente
- um estimativo de preço
- se tem como ajudar na questão do transporte

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

Closed 2017-04-18.

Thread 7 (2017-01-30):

Pesquisar empreiteiros

yorikvanhavre, 2017-01-30:
Pesquisar empreiteiros de pequeno porte que possam fazer a parte de alvenaria, e seriam dispostos a trabalhar com a gente na interface entre as partes de alvenaria e de wikihouse, e ajudar com a cobertura.

Closed 2017-04-18.

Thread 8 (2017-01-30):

Impregnação

yorikvanhavre, 2017-01-30:
* Ver possíveis meios de impregnação (contra fungos, insectos, e incêndio)
* Ver qual é necessário
* Ver qual tipo de painel pode ser tratado
* Obter estimativa de preço

Closed 2017-04-18.

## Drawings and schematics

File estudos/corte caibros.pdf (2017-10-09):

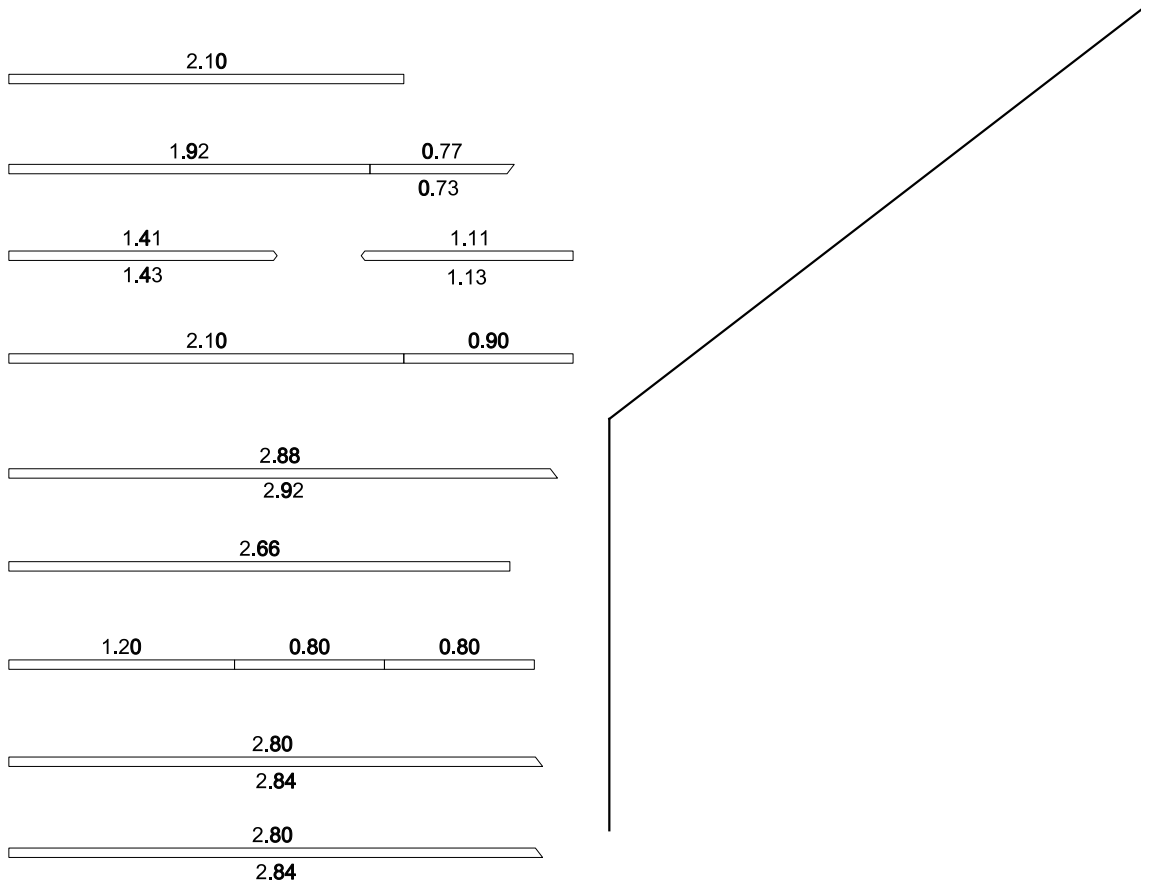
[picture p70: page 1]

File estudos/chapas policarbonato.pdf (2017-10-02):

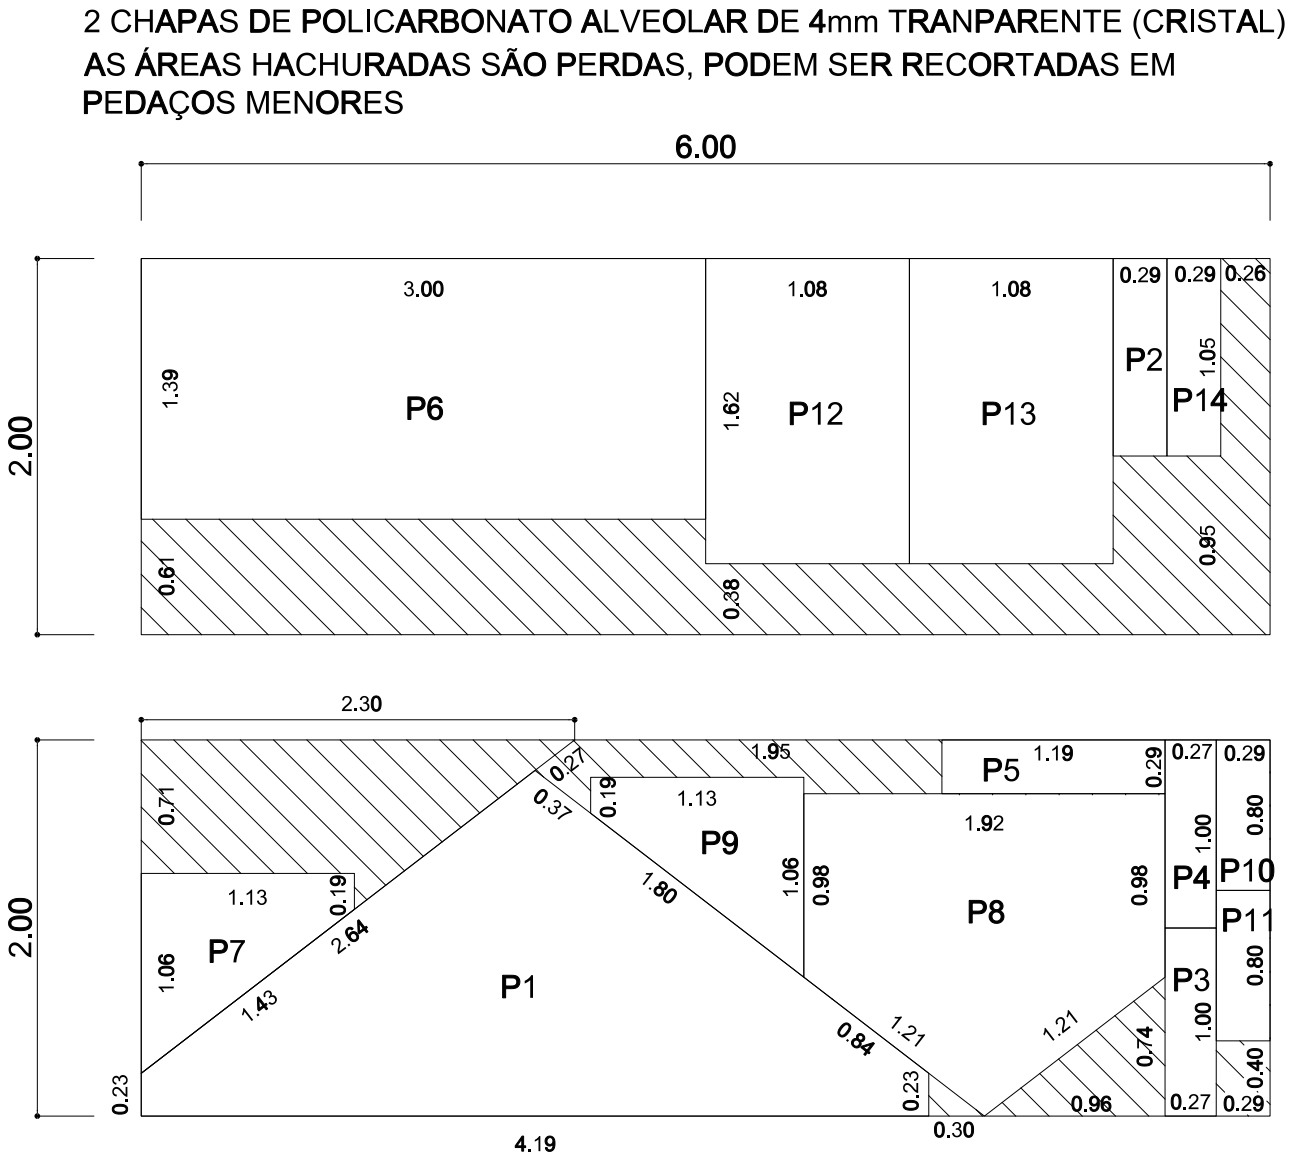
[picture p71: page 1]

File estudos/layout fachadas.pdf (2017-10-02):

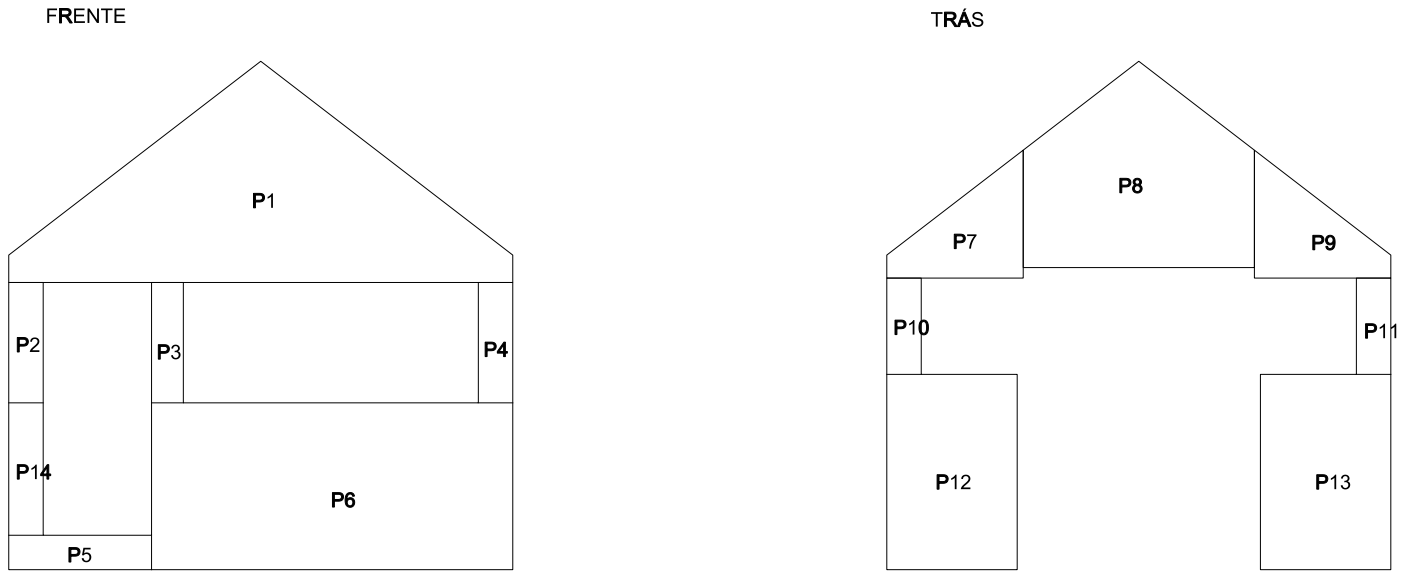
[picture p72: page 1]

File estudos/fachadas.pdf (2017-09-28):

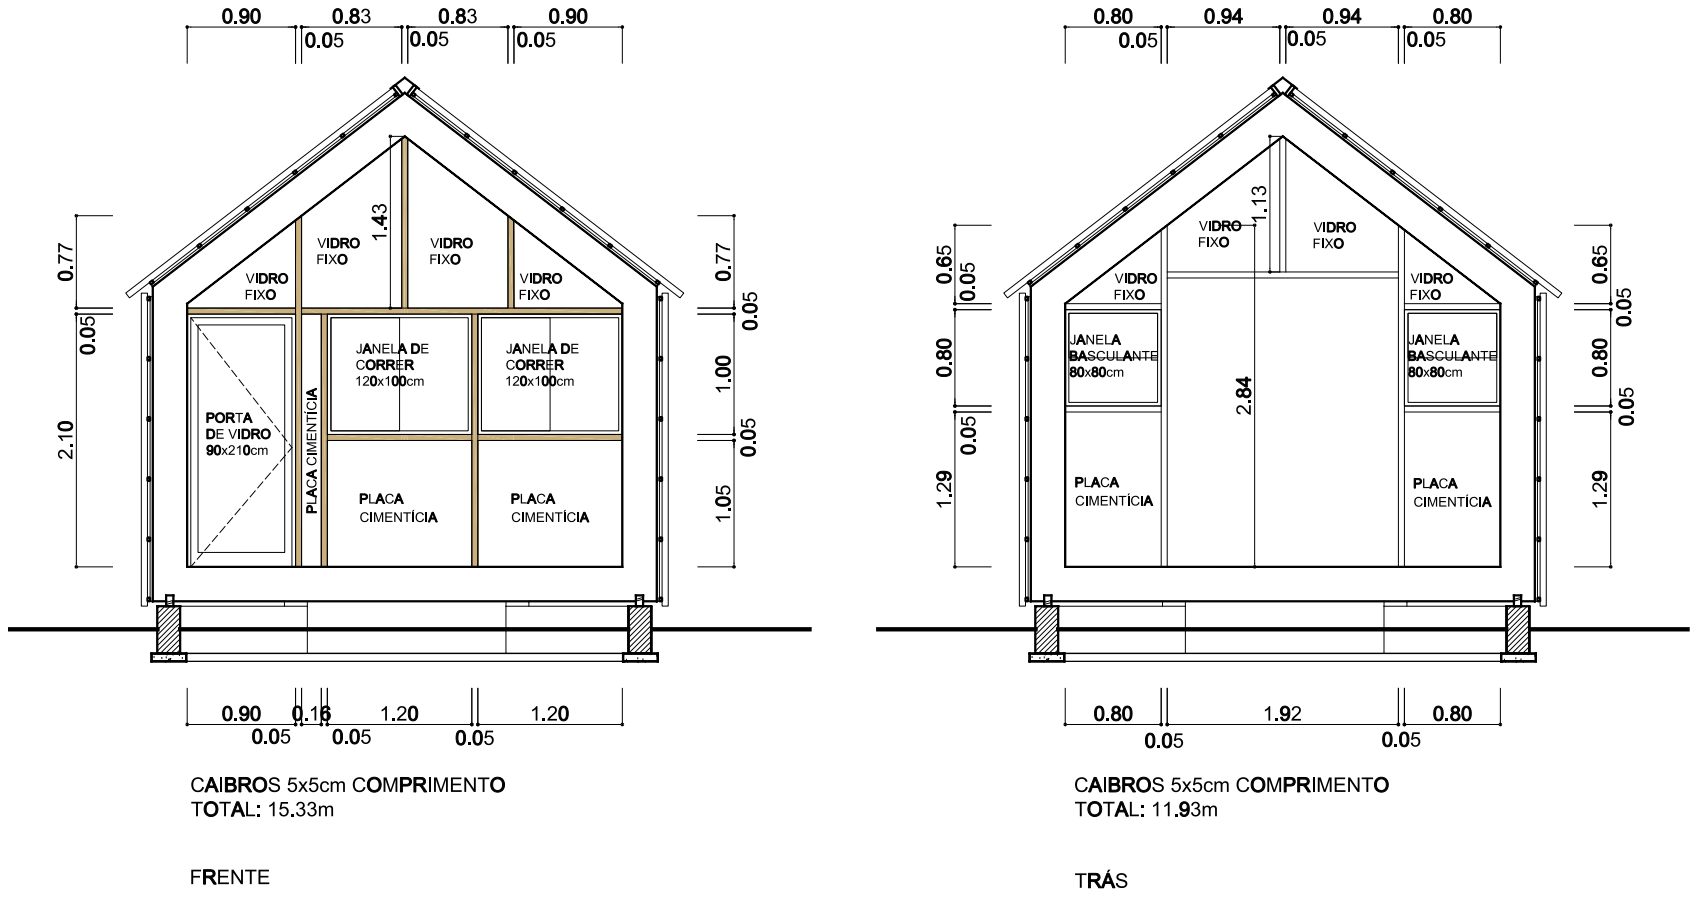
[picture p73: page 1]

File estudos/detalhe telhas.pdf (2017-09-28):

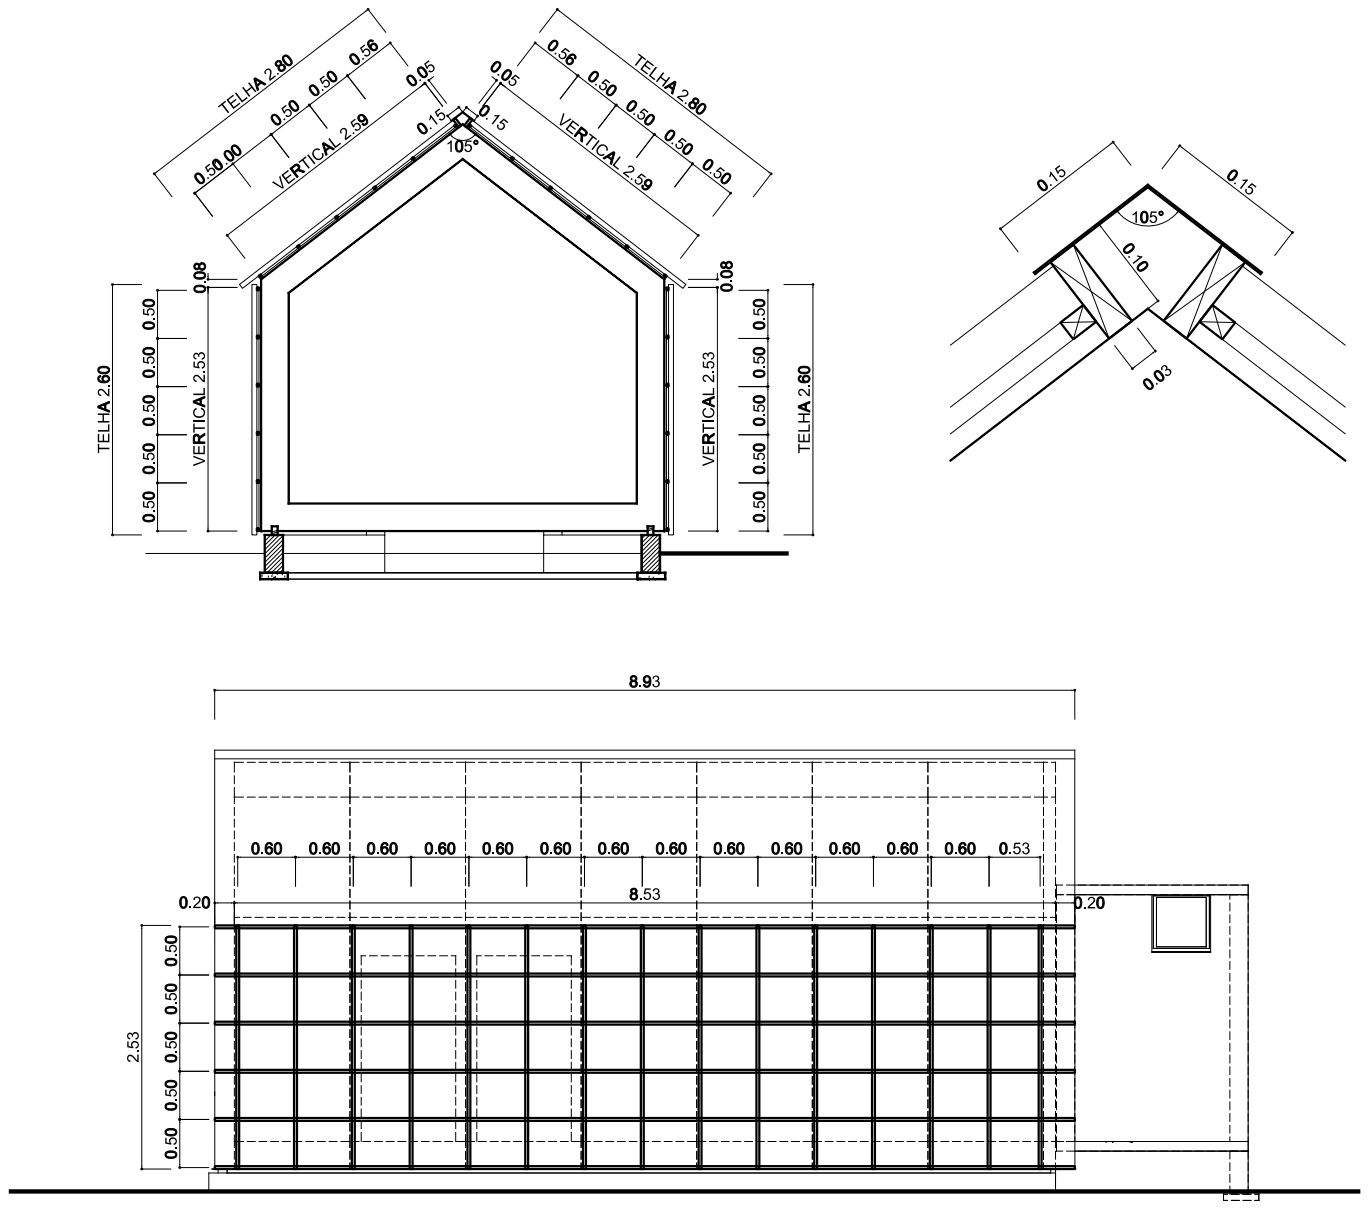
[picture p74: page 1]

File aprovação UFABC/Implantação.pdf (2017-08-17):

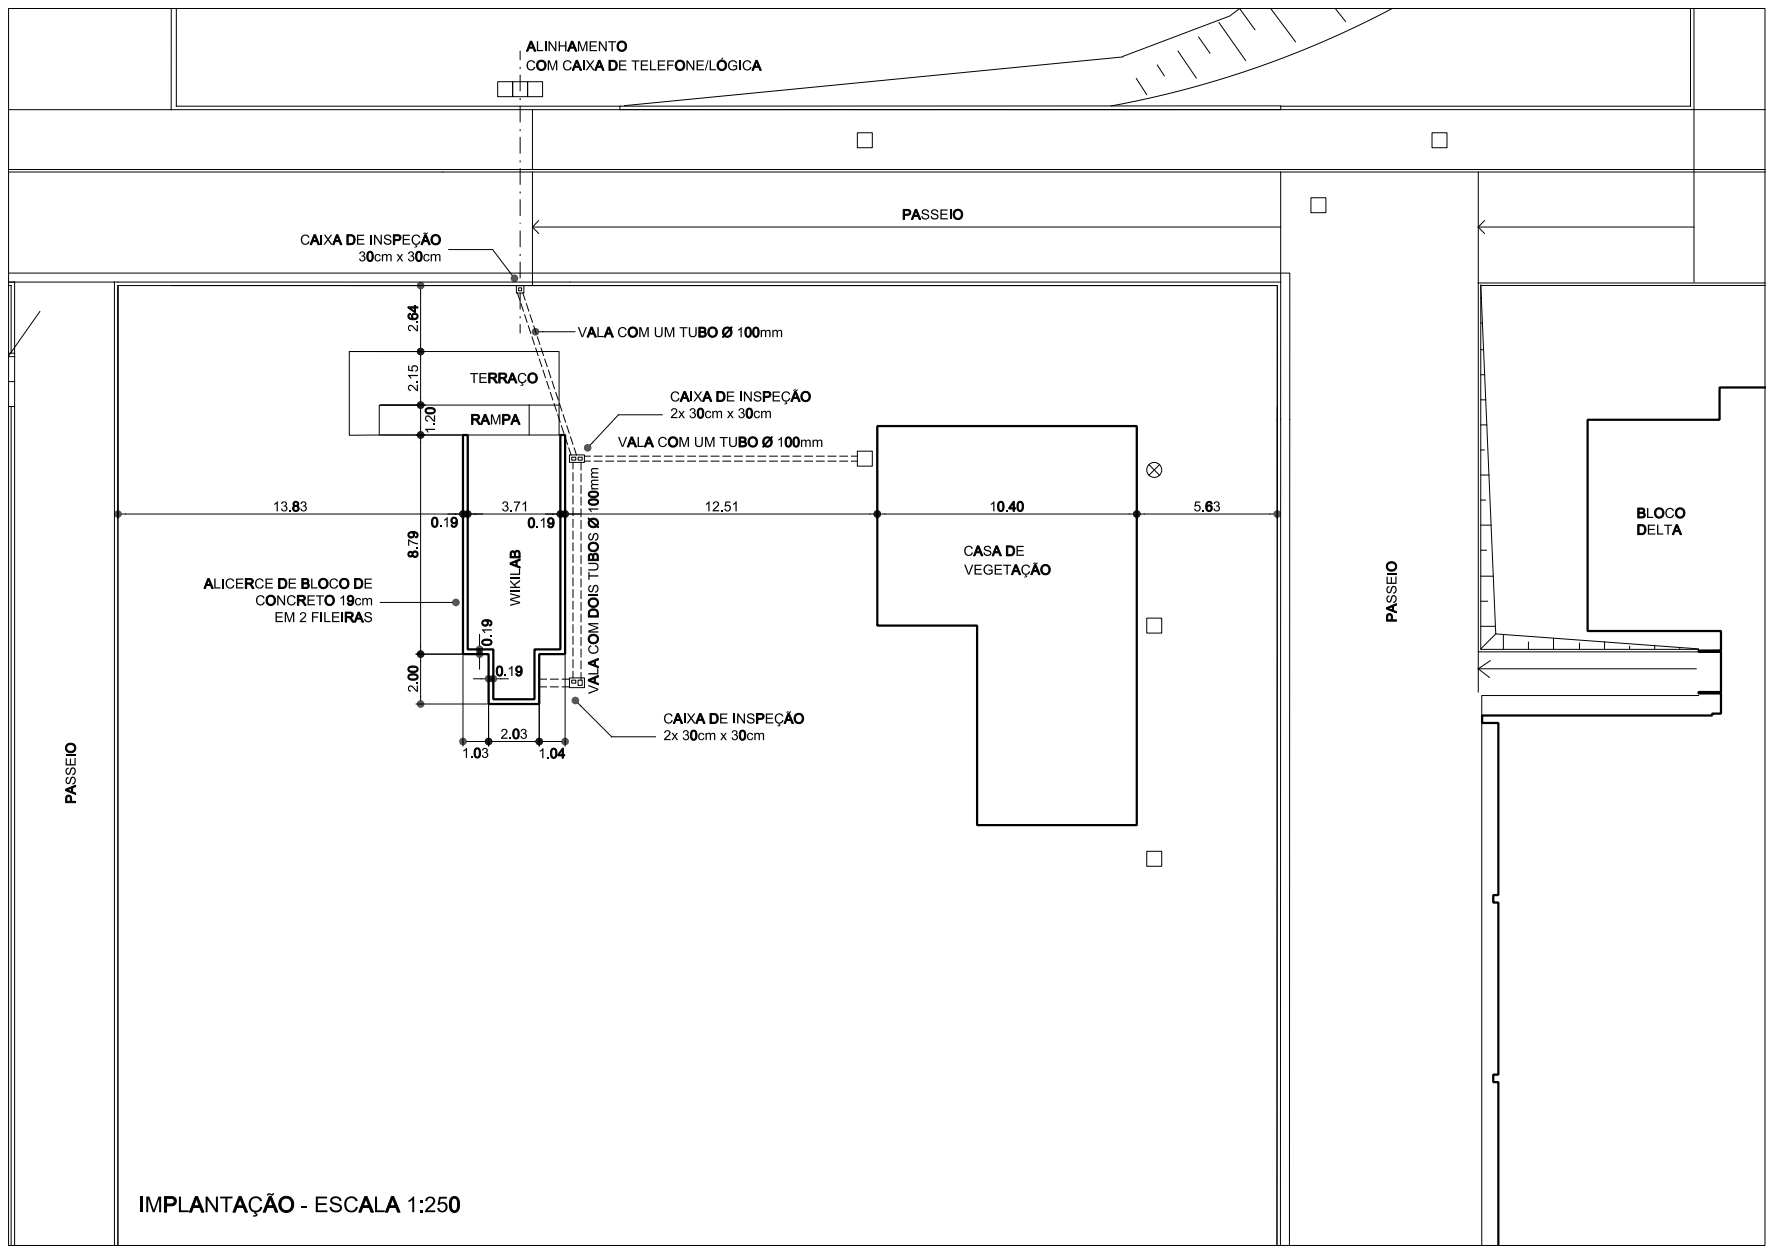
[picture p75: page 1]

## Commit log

2016-10-17 Módulos de exemplo do wikihouse
2016-12-01 modulo básico
    [modulo.blend, modulo.fcstd]
2016-12-18 modelo atualizado
    [cut sheet.dxf, modulo.blend]
2016-12-27 submodulos atualizados
    [cut sheet.dxf]
2017-01-31 modelo blender
    [modulo.blend, wikilab.blend, wren.obj]
2017-02-05 modelo blend completo
    [base.obj, wikilab.blend, wren.obj]
2017-02-07 Modelo final + pdf
    [base.obj, perspectiva.blend, wikilab.blend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]
2017-02-07 Mobiliário
    [mobiliário.blend]
2017-02-08 Orçamento preliminar
    [cut sheet.dxf, orçamento.ods]
2017-02-08 orçamento em pdf
    [orçamento.ods]
2017-02-08 imagens de referencia
2017-02-08 nova imagem exterior
    [perspectiva.blend, wikilab.blend]
2017-02-11 mais uma imagem com grafitti
    [wikilab.blend]
2017-02-23 Inclusão das árvores no orçamento
    [orçamento.ods]
2017-02-24 foha A1
    [Levantamento de custos da Wikilab.xlsx, estrutura similar.dwg]
2017-03-07 Arquivo fcstd com shapes HiRes + arquivo ifc
    [Levantamento de custos da Wikilab.xlsx, cut sheet.dxf, estrutura similar.dwg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]
2017-04-20 Maquete 10.5x5x5cm
    [maquete.FCStd, maquete.dxf, maquete.stl]
2017-04-20 versão STL
    [wikilab.stl]
2017-04-20 Deslocado exemplo de cut sheet para pasta 'partes'
    [cut sheet.dxf]
2017-04-20 Teste de encaixe
    [test part.dxf, test part.stl, test.FCStd]
2017-04-20 gerados plotsheets do projeto
    [plotsheet 1 - elemento final (1x).dxf, plotsheet 2 - elemento basico (3x).dxf, plotsheet 3 - elemento vazado (4x).dxf]
2017-05-17 maquete v2
    [maquete v2.dxf, maquete.FCStd, maquete.dxf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]
2017-05-18 Martel adicionado
    [mallet.dxf]
2017-05-20 Adicionados dogbones no teste de encaixe
    [test part.dxf]
2017-05-20 Adicionadas fotos do teste de encaixe
2017-05-20 file permission
    [mallet.dxf]
2017-05-20 pasta teste renomeada
    [test part.dxf, test part.stl, test.FCStd]
2017-05-21 Dogbones adicionais
    [cut sheet.dxf, plotsheet 1 - elemento final (1x).dxf, plotsheet 2 - elemento basico (3x).dxf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]
2017-05-25 Apresentação WikiHouse 29 de maio
2017-05-31 início manual de design
2017-06-01 Update manual de design.md
2017-06-16 início manual de construção
2017-06-16 Update and rename Manual de montagem.md to manual de montagem.md
2017-06-20 Arquivos licitação
    [pedido de orçamento.xls]
2017-06-28 Novas folhas de corte
    [plotsheet 1 - elemento final (1x).dxf, plotsheet 2 - elemento basico (3x).dxf, plotsheet 3 - elemento vazado (4x).dxf]
2017-06-28 dossiê de licitação
    [pedido de orçamento.xls]
2017-06-28 dossiê de aprovação
2017-06-28 Estimativa de consumo elétrico
2017-06-29 Tampas de madeira nas folhas de corte
    [plotsheet 2 - elemento basico (3x).dxf, plotsheet 3 - elemento vazado (4x).dxf]
2017-07-07 Sequencia manual de montagem
2017-07-07 file permissions
    [plotsheet 1 - elemento final (1x).dxf]
2017-07-25 manual de construção até fim da primeira fase
2017-07-25 atualização arquivo principal com detalhes de construção
2017-08-02 manual de montagem - parte 2
    [wikilab.stl]
2017-08-03 manual de montagem - parte 3
    [telhas.FCStd]
2017-08-07 relatório - telhas
    [telhas.FCStd]
2017-08-09 manual parte 04 - fim
    [caixilhos frontais.dxf]
2017-08-10 orçamento infraestrutura
    [orçamento.ods]
2017-08-11 orçamento atualizado
    [Comp Custos Unit EDIF SEM Des JAN 2017.xls, Custos Unit EDIF SEM Des JAN 2017.xls, orçamento preliminar.ods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]
2017-08-14 Ajustes projeto executivo para aprovação UFABC
    [Proposta Wikilab para infraestrutura.dxf]
2017-08-18 Documentos painel de OSB + revisão do orçamento
    [Orçamento.xls, orçamento.ods]
2017-08-23 Elementos de bordas
    [plotsheet 4 - acabamentos de bordas (1x).dxf]
2017-08-24 Cronograma de obra
    [cronograma da obra.ods]
2017-08-28 Atualização da posição dos ferragens
    [cronograma da obra.ods]
2017-08-28 reorganização das pastas
    [Comp Custos Unit EDIF SEM Des JAN 2017.xls, Custos Unit EDIF SEM Des JAN 2017.xls, Levantamento de custos da Wikilab.xlsx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]
2017-08-29 Retirada de uma fileira de blocos
2017-08-30 Reorganização dos arquivos
    [Comp Custos Unit EDIF SEM Des JAN 2017.xls, Custos Unit EDIF SEM Des JAN 2017.xls, Orçamento.xls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]
2017-09-11 removendo arquivo admin
    [estimativo de custos.xlsx]
2017-09-21 nova versão do dossiê de aprovação
2017-09-26 Atualização do cronograma
    [cronograma da obra.ods]
2017-09-28 Anteprojeto elétrico
    [Elétrica - Projeto Básico - proposta.dwg, Elétrica - Projeto Básico.dwg]
2017-10-02 Fachadas em chapas de policarbonato
2017-10-11 projeto elétrico final
    [1718-EL-DE-01-R00.dwg]
2017-10-25 orçamento elétrica
    [quantitativo.ods]
2018-01-25 manual de construção atualizado
    [1718-EL-DE-01-R01.dwg]
2019-03-15 Update relatório de reparos março 2019.md
